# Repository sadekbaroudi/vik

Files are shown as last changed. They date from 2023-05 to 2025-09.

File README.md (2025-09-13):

# VIK

> **Warning**  
> This is a work in progress. It has been tested to be functional, but please consult **sadekbaroudi** in the **#vik** channel of the [fingerpunch discord server](https://fingerpunch.xyz/discord) if you'd like to design a keyboard or module.

> **Note**  
> **To see the list of known supported keyboards and modules, go to [this section](#known-list-of-vik-certifications) at the bottom of the readme**

> **Note**  
> Please be aware that for keyboard pcbs, VIK assumes that it's running at 3.3v logic levels. This is easily achieved by using a RP2040. If you are using a 5v controller, it is the keyboard's responsibility to level shift before going to the VIK module. See the [Microcontroller selection](#microcontroller-selection) section below

## License

**The licensing for VIK works as follows:**  
The main `LICENSE.md` in the git repository root directory applies to the whole repo, except where there is a `LICENSE.md` in the sub-folder. In that case, that `LICENSE.md` is then applied recursively until there is another `LICENSE.md` in any of its subdirectories (if any).

## Overview

VIK is a standard for a data interface between printed circuit boards. It is intended to provide modularity between a mechanical keyboard pcb and additional features. The main pcb can have a controller and a switch matrix, while the modules can provide additional features.

The standard specifies the following:
1. The type of connector
2. The signals mapped to each pin on the connector
3. The type of cable
4. (optional) The size of the module pcb and mounting hole locations
5. Inclusion of the VIK logo on the PCB

> **Note**  
> Adding support for VIK is as simple as adding a symbol and footprint, provided in this repository, followed by some basic wiring. If you want to jump straight to the guide to do this using Kicad, go to [Implementation with Kicad](#implementation-with-kicad) 

## Renders

Keyboard with VIK certification using the keyboard footprint

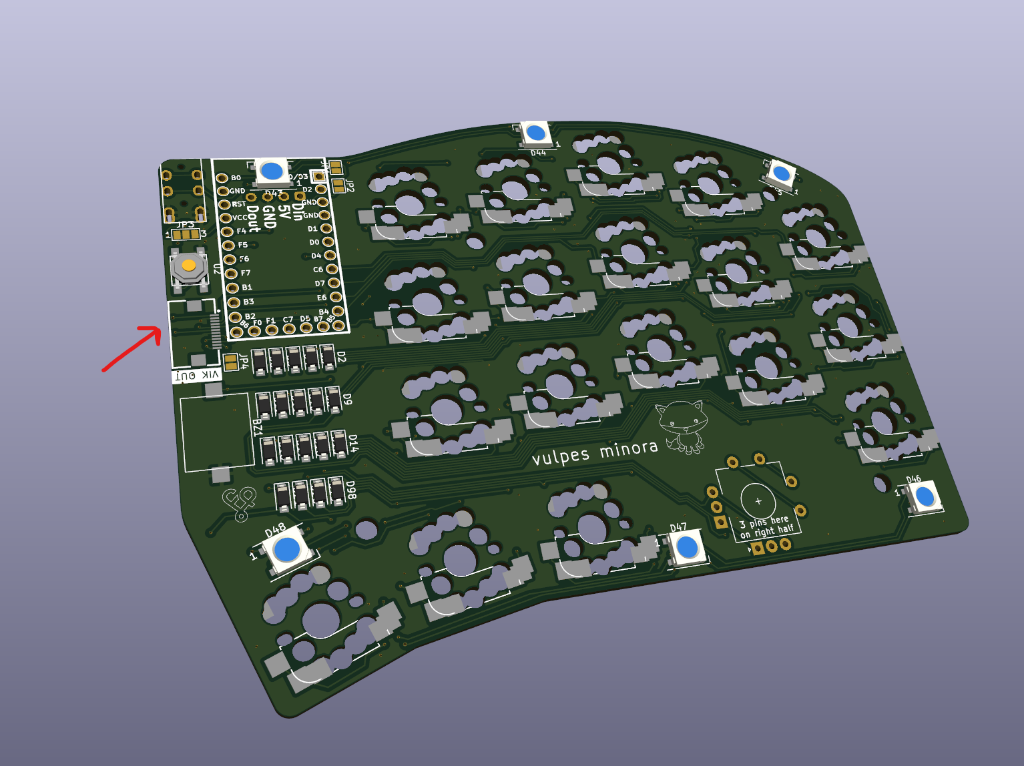
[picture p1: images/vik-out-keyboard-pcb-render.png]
vik-out-keyboard-pcb-render


Module with VIK certification using the module footprint

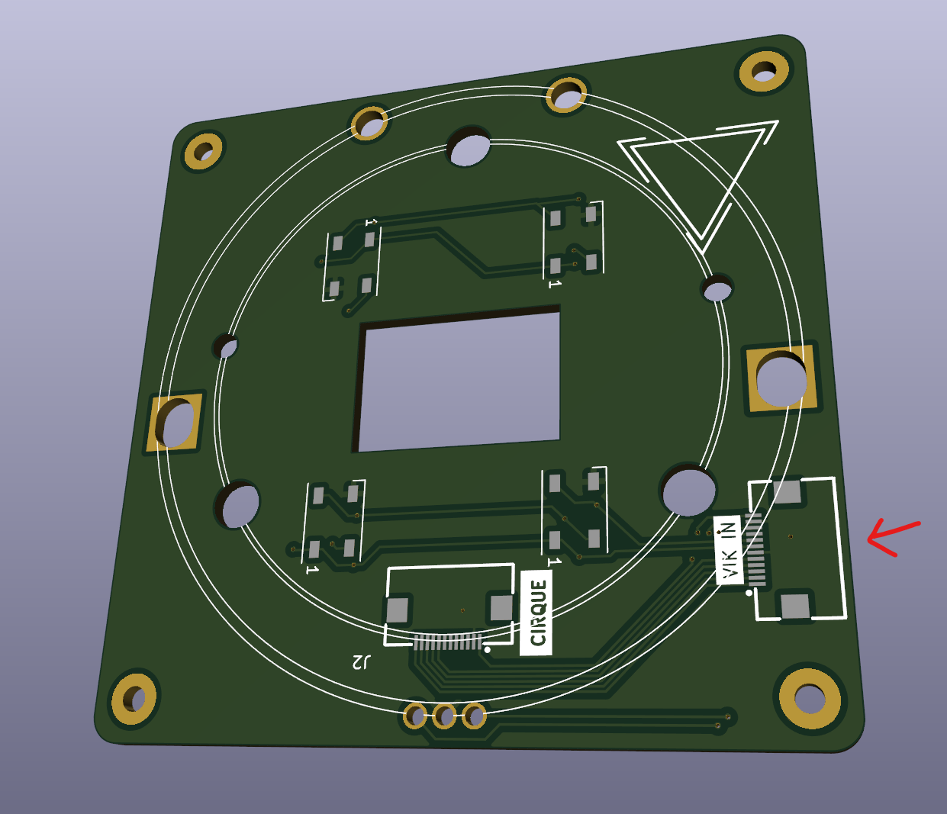
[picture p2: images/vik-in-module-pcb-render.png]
vik-in-module-pcb-render


### What value does this bring?

#### Consoldiates efforts for feature design

In a community full of talented people doing lots of innovation, we are seeing a plethora of new options for keyboard layout configurations, features, etc. With all this innovation, we're doing very little to share our efforts.

For example, if one person invests in adding support for a trackball with a scroll wheel, others have to identify how to do that, and add support for their keyboard design.

#### Ease of upgrades

With VIK support, upgrading your features is as simple as getting a new VIK module, and swapping it out.

Let's say you built a keyboard with an integrated trackpad, and you love it. Months after setting it up, you realize that you'd love to have a trackball and haptic feedback. Now you need to design a new pcb (or find someone who has) with the features you'd like. Most people don't know how, or don't want to put forth this effort, so they will settle for their current configuration. With much less effort, you can create a new VIK module, assemble it, and connect to your existing keyboard.

#### One feature for many keyboard layouts

One of the biggest challengs I find, is that a keyboard may have some really excellent features, but I really don't like the key layout. In that case, I won't be interested in the keyboard, despite wanting the features.

Provided that keyboard designers adopt the VIK standard on the main keyboard pcb, the modules are usable on any of those keyboards. So, you can design or find a keyboard that has your preferred layout, and then add the features that you like. True customizability for the exact keyboard you want to use.

## Specifications

There are two things that must be implemented for this to be successful. The keyboard pcb must support the VIK interface, and the module pcb must support the VIK interface

### Connector

The required connector is a FPC 12 pin 0.5mm pitch connector. It should be available on both the keyboard pcb and the module pcb.

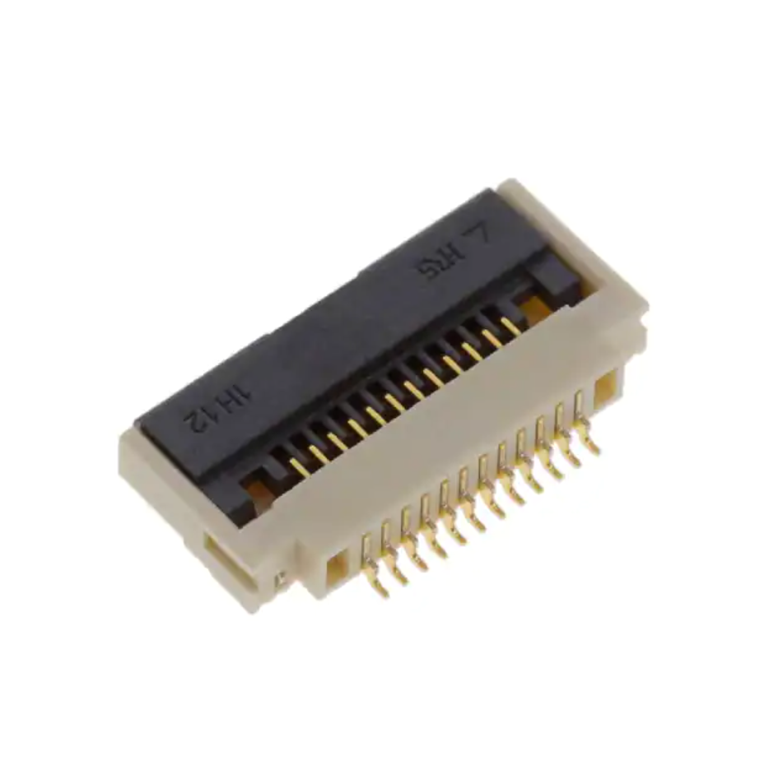
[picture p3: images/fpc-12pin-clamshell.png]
fpc 12 pin 0.5mm clamshell


#### JLCPCB part selection tips

I've received feedback that the recommended part number `C479750` for the fpc connector (`vik-{keyboard|module}-connector-horizontal`) is frequently out of stock. Fortunately, there are many equivalent parts that line up identically to this one.

To find an equivalent, I generally just search for "12p 0.5mm fpc clamshell". Then I pick one that looks identical to `C479750`. During PCBA part placement, go into 3D mode and adjust the view to make sure the pads line up nicely with the connectors. An example of an alternative part number is `C2906115`.

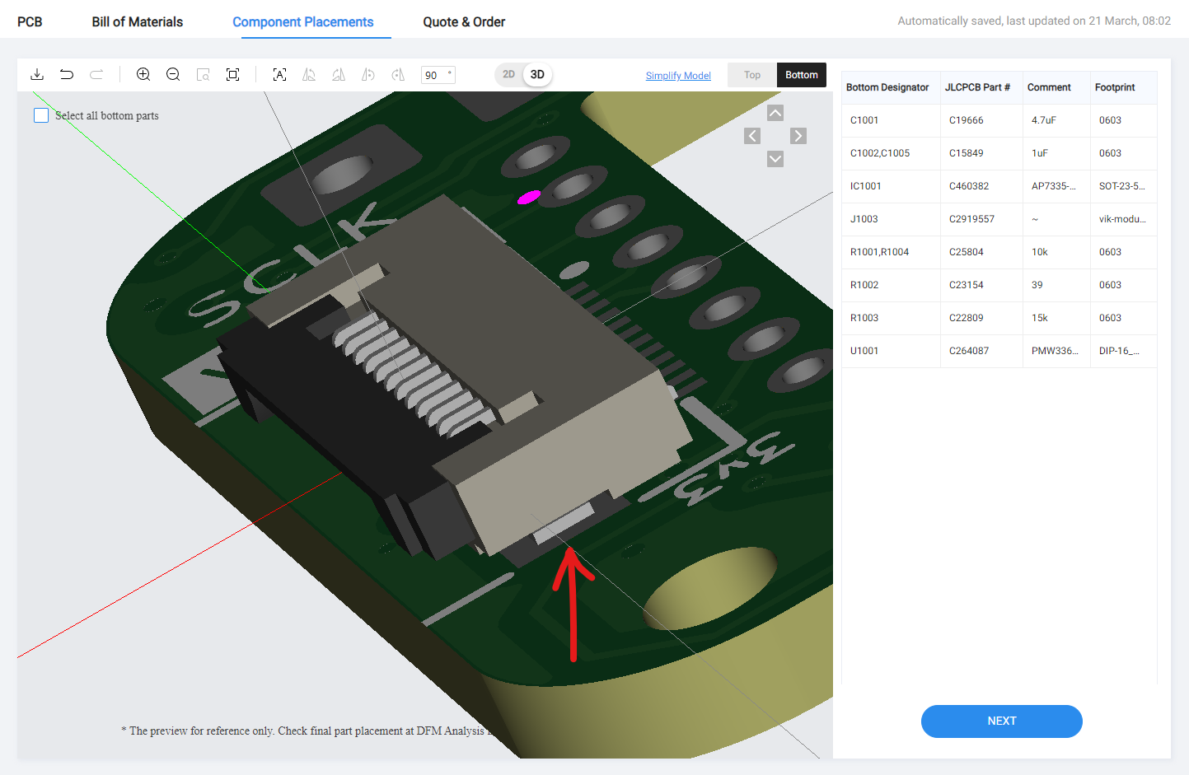
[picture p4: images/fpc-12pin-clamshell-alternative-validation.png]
fpc 12 pin 0.5mm clamshell alternative validation


### Cable

The cable should be a 12 pin 0.5mm pitch FPC Type A cable (leads are exposed on the same side).

The specs below state that you must invert the connector pin order between the keyboard and the module, which means Type A is required.

### Interface

The interface includes the following signals:
* 3.3V
* GND
* SDA
* SCL
* RGB Data Out
* 5V
* Digital/Analog GPIO 1
* MOSI
* Digital/Analog GPIO 2
* SPI CS
* MISO
* SCLK

The order specified above is the order they should be used on the FPC connector on the **keyboard side**, pins 1 through 12. For the module pcbs, they should be inverted, since the cable will automatically invert the order when connected. If you use the VIK Kicad symbols and footprints, this is managed for you. See the [Implementation with Kicad](#implementation-with-Kicad) section below

### VIK logo

So long as you adhere to the specs above, you can consider your keyboard pcb or module VIK enabled. The last thing you do before publishing or manufacturing your PCB is to include the VIK logo.

There are a collection of logos you can use in the kicad/vik.pretty directory of this repository, all prefixed with `vik-logo`. For instance, you could take the pre-made kicad footprints and include them on your pcb. If you aren't using kicad, there is a dxf and svg you can use as well.

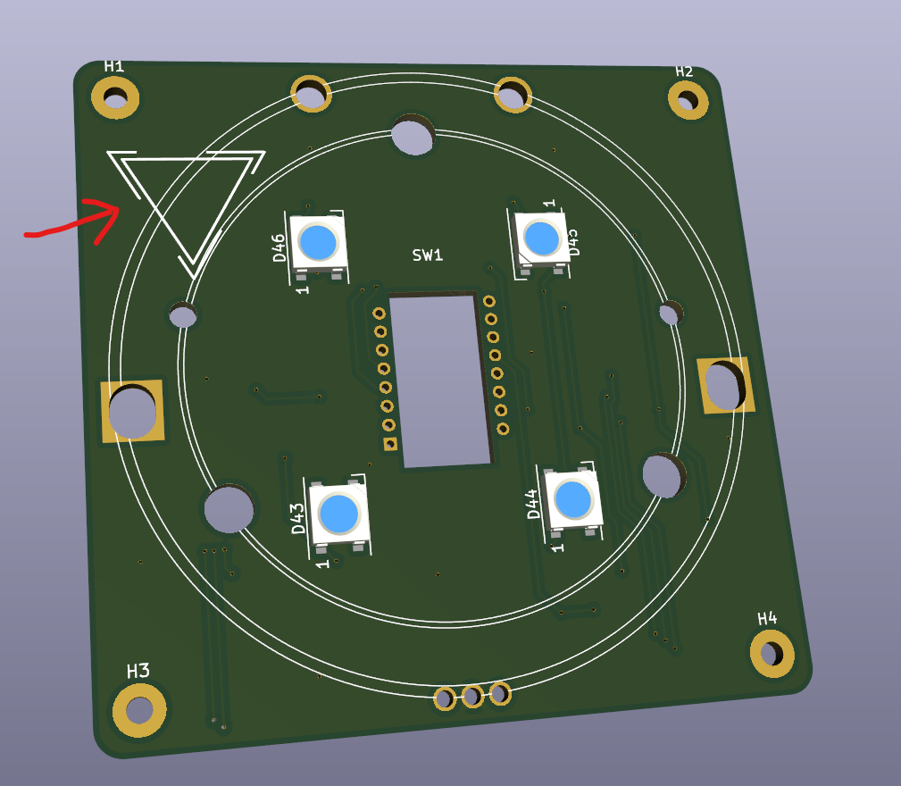
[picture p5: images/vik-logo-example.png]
vik logo example


## Module PCB shape and mounting

This is optional, but highly recommended. By adhereing to a standard size and mounting, this will allow others to design keyboard pcbs and/or cases that will support mounting a variety of modules.

There are two specs, a small and large pcb.

**All mounting holes should fit M2 screws**

### Small PCB

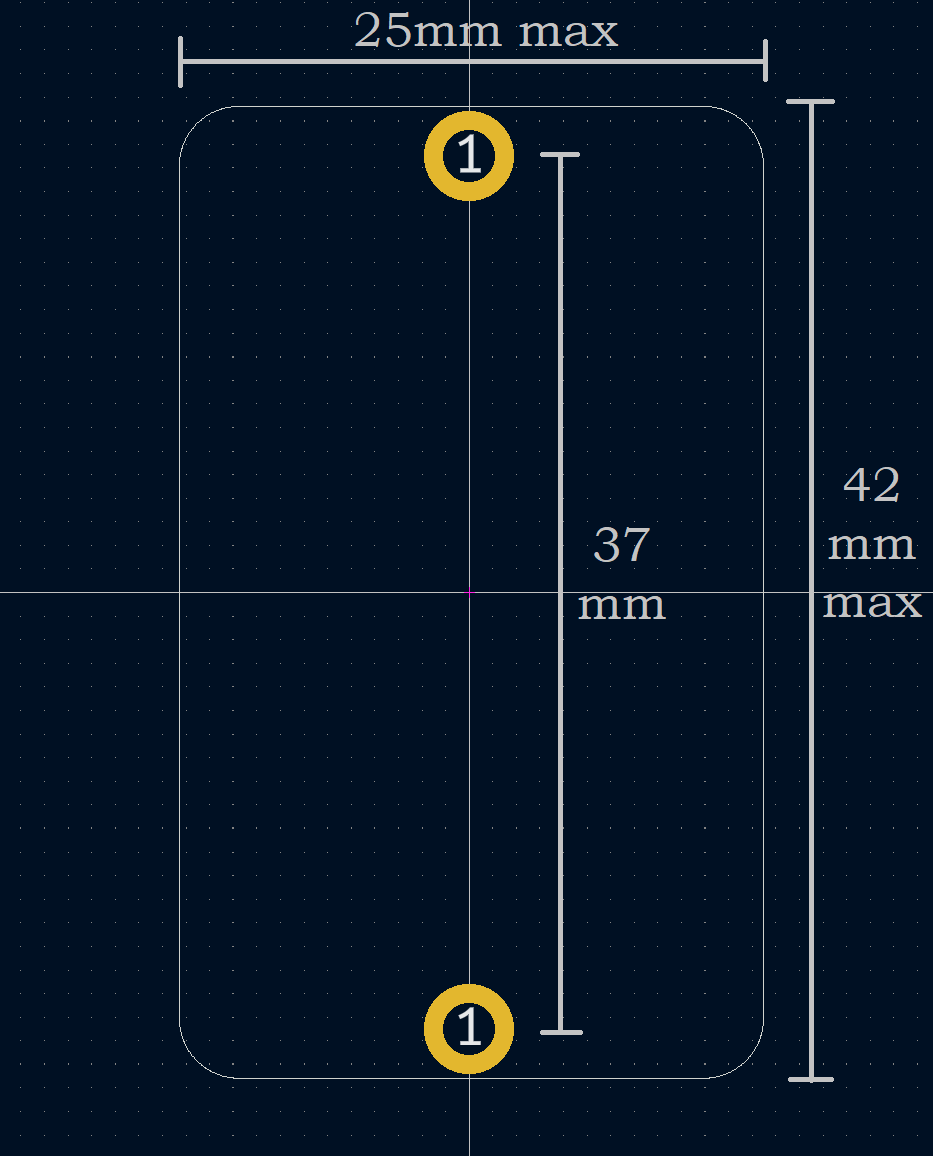
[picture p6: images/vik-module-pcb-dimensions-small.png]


Size: less than 25mm by 42mm

Mounting: 2 mounting holes

### Large PCB

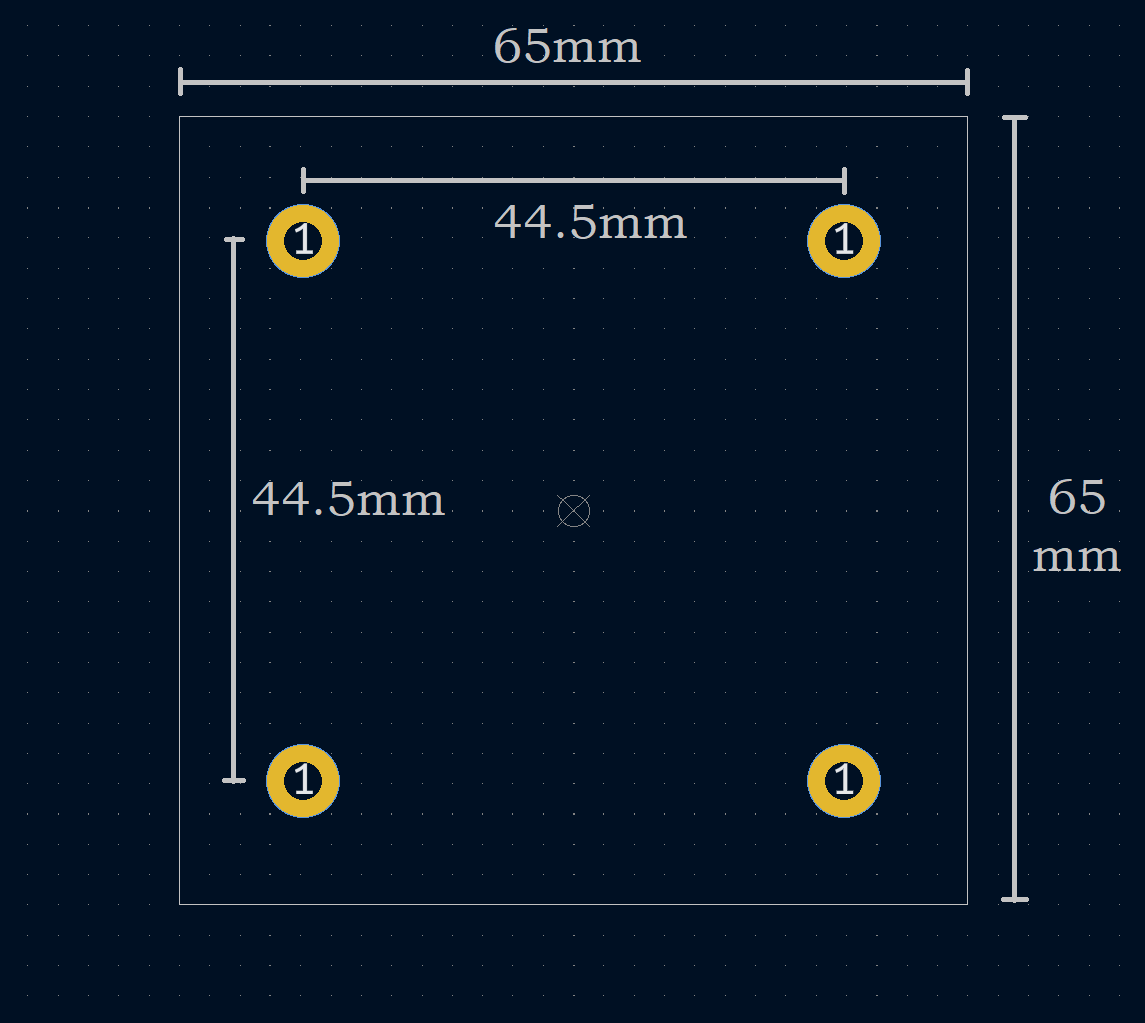
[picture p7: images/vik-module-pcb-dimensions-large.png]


Size: less than 65mm by 65mm

Mounting: 4 mounting holes

The mounting holes should 44.5mm apart in a square, centered around the center of the pcb. Alternatively, you can place these mounting holes evenly distributed around a 63mm circle, also centered around the center of the pcb.

### Module mounting Kicad footprints

There are two mounting footprints, found in the vik.pretty footprints folder:
* vik-module-mounting-small
* vik-module-mounting-large

You can use these for one of two purposes:
1) When creating a module, use the footprint to ensure that your module pcb has the correct mounting locations
2) When creating a keyboard, use the footprint to position where you'd like to mount a module pcb

You can use the Mounting Hole symbol in the schematic, and associate one of the footprints as shown below:

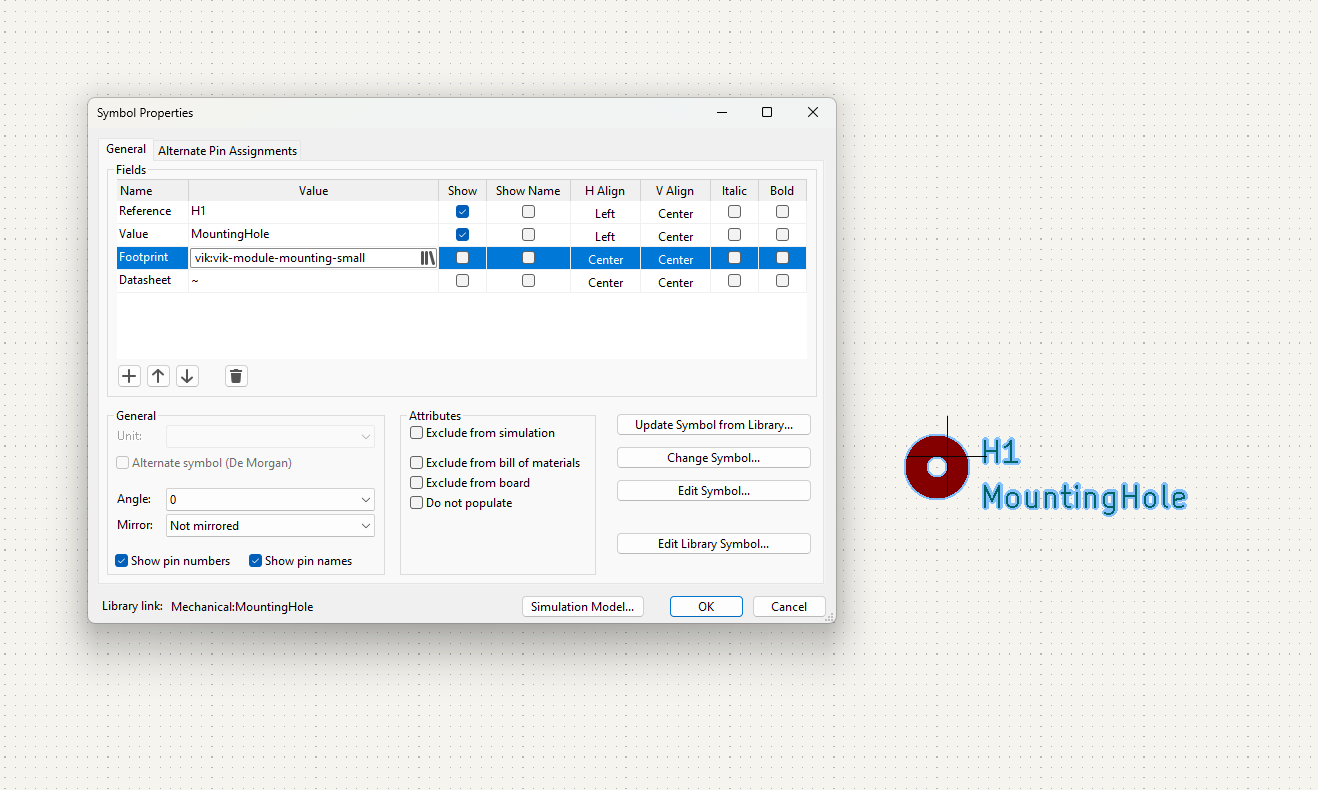
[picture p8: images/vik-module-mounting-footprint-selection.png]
vik-module-mounting-selection


## Implementation with Kicad

Given Kicad's popularity, I've made it (hopefully) very convenient to implement VIK on the keyboard and module side.

### Add symbols and footprints to your Kicad project

1. Clone this repository to your local machine
2. Add the VIK symbol library your project
3. Add the VIK footprint library to your project

Please note that the path in the screenshots won't be the same as yours. It should be:  
`{PATH TO CLONE OF THIS REPO}/kicad/vik.kicad_sym`  
and  
`{PATH TO CLONE OF THIS REPO}/kicad/vik.pretty`  

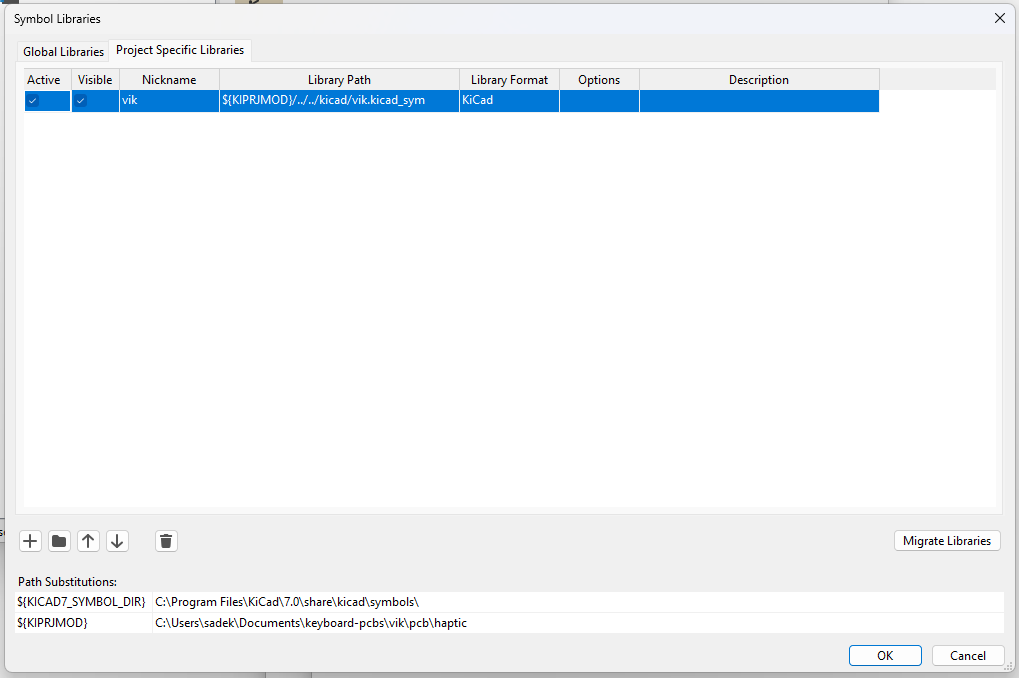
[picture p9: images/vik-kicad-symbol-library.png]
vik-kicad-symbol-library


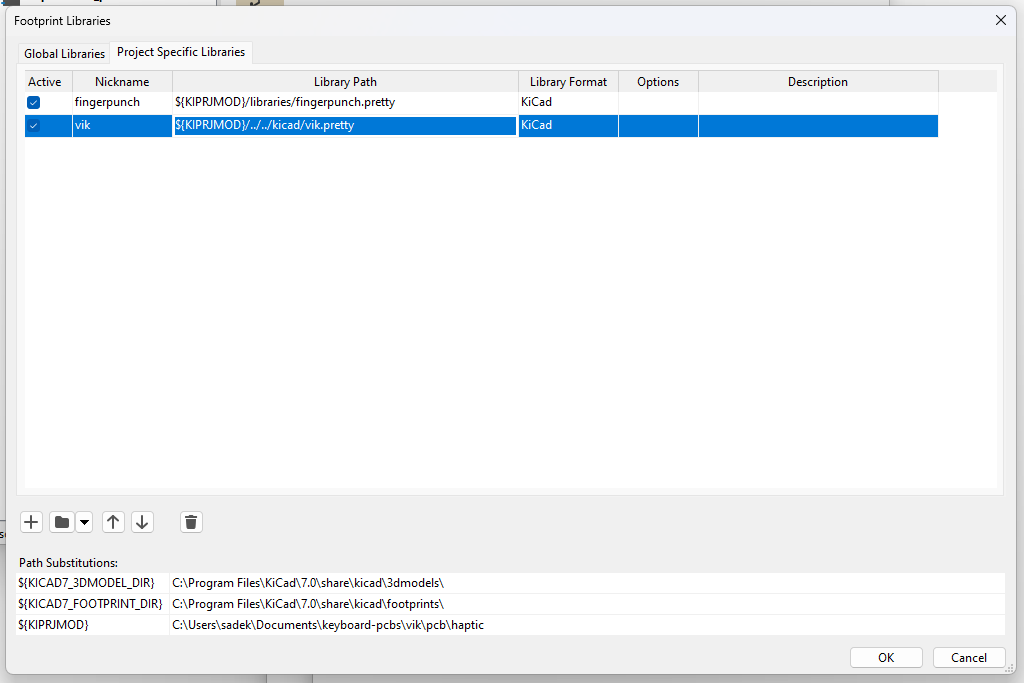
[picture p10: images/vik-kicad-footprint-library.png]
vik-kicad-footprint-library


### Kicad keyboard connector

1. Add a new symbol in the schematic, and select the `vik-keyboard-connector`
2. Connect all the signals as specified
3. Associate with the type of footprint you'd like to use (all of the VIK examples use the horizontal connector footprint). Given you are making a keyboard connector, be sure to use the ones that have the word keyboard in them. See the image below for an example.
4. Update your PCB from the schematic and wire it up!

#### Adding the keyboard connector symbol

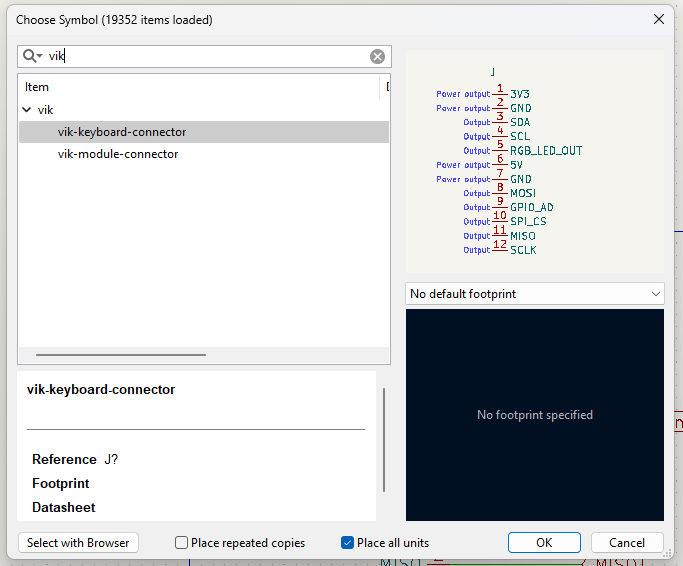
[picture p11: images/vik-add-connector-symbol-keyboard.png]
vik-add-connector-symbol-keyboard


#### Assigning the keyboard connector footprint

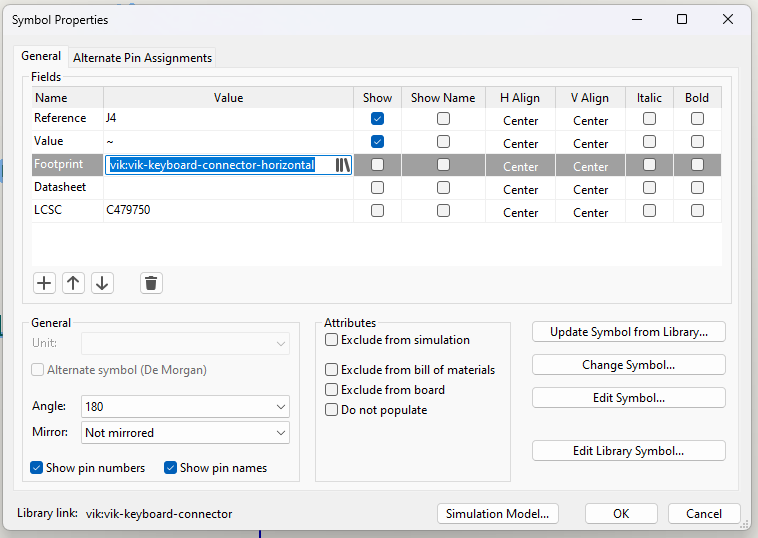
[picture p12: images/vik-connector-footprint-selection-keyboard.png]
vik-connector-footprint-selection-keyboard


#### Example schematic for keyboard connector

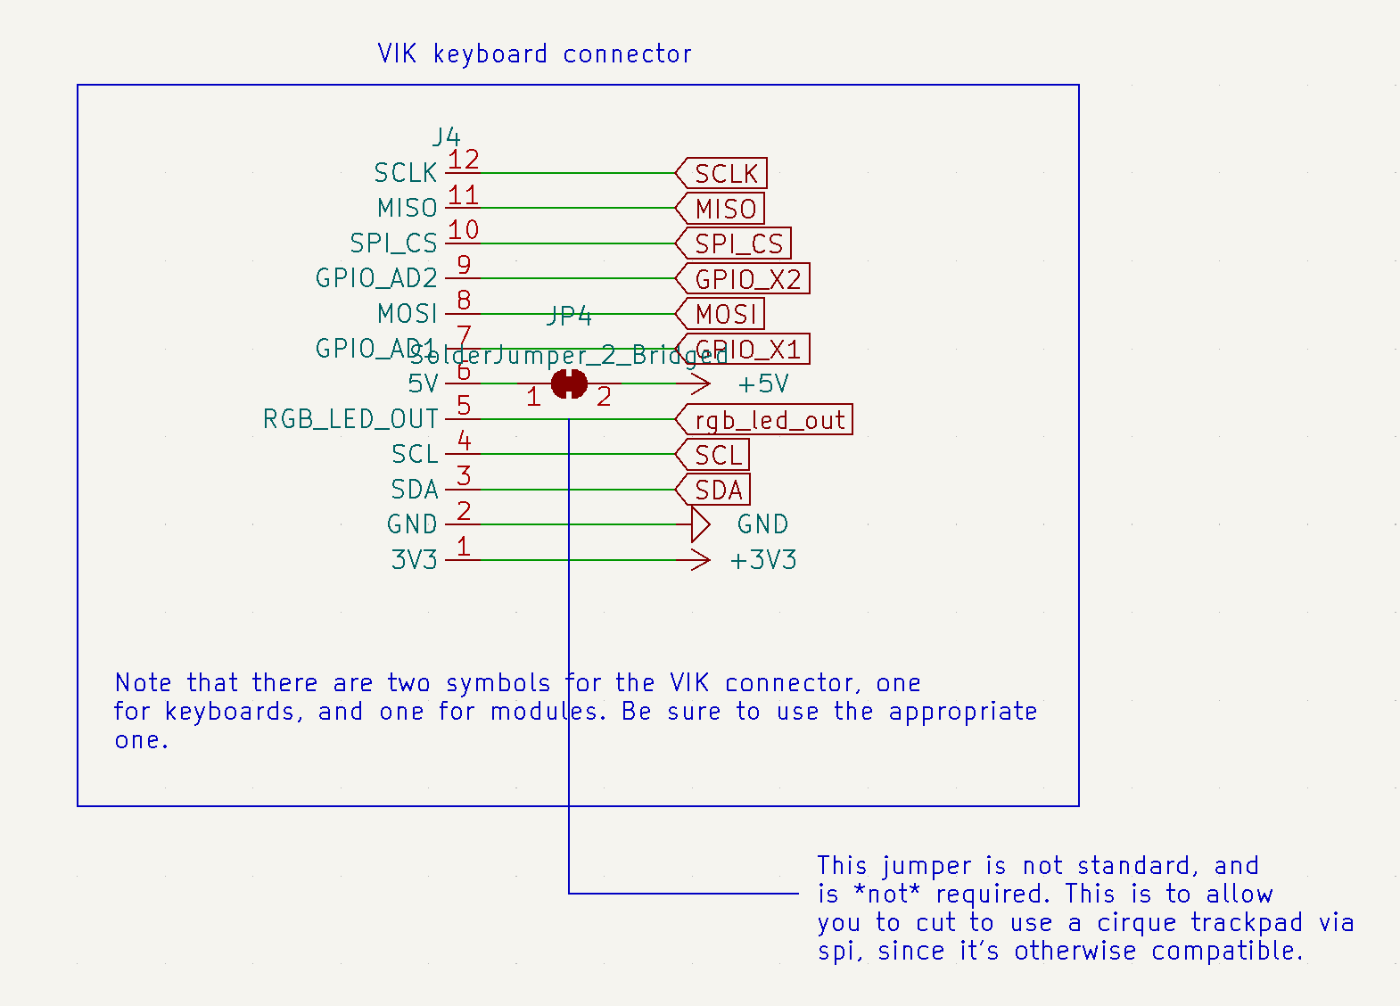
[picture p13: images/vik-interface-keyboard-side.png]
vik fpc keyboard


#### Example wiring for keyboard connector

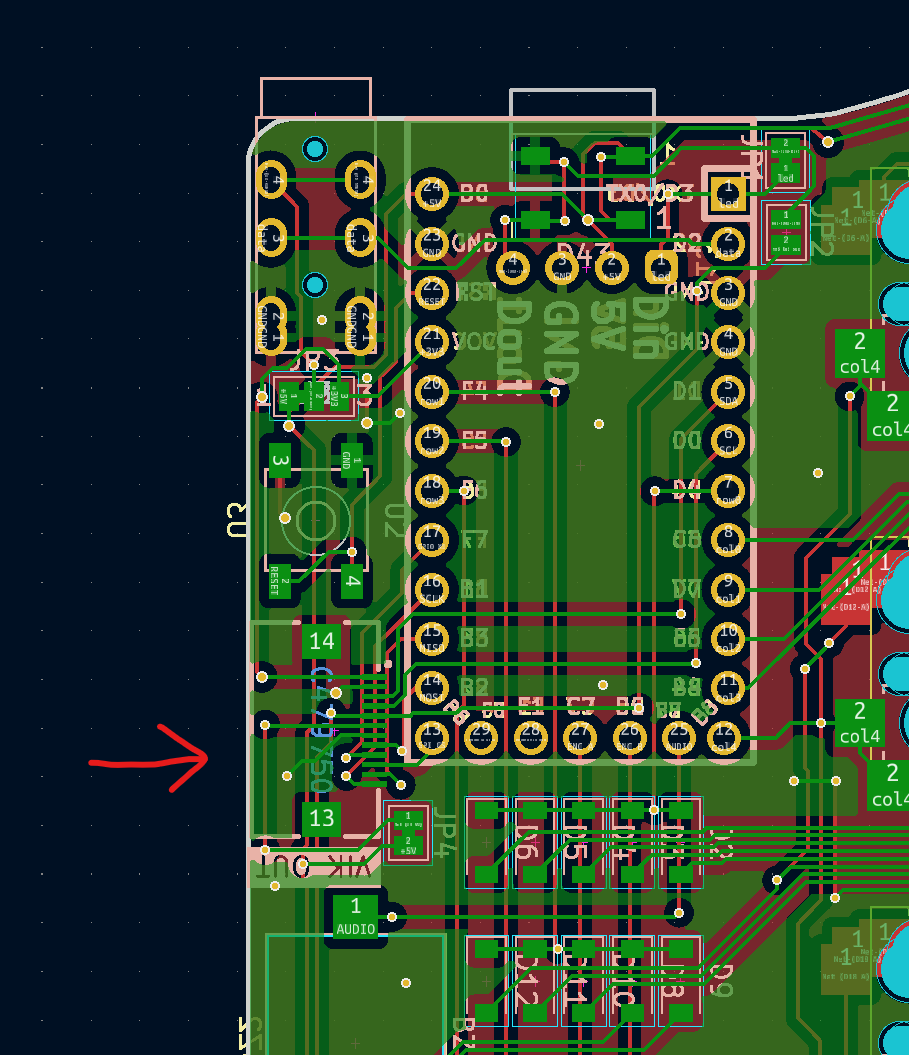
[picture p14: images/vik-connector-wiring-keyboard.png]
vik-connector-wiring-keyboard


### Kicad module connector

1. Add a new symbol in the schematic, and select the `vik-module-connector`
2. Connect all the signals as specified
3. Associate with the type of footprint you'd like to use (all of the VIK examples use the horizontal connector footprint). Given you are making a module connector, be sure to use the ones that have the word module in them. See the image below for an example.
4. Update your PCB from the schematic and wire it up!

#### Adding the module connector symbol

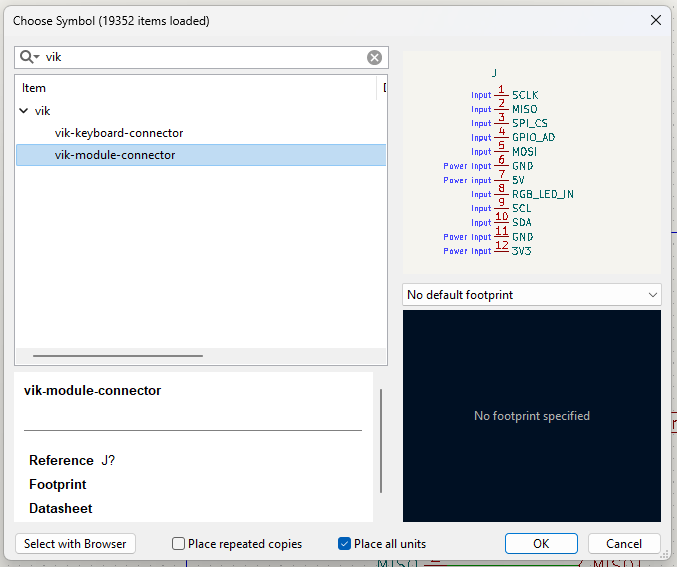
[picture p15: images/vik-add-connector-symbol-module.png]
vik-add-connector-symbol-module


#### Assigning the module connector footprint

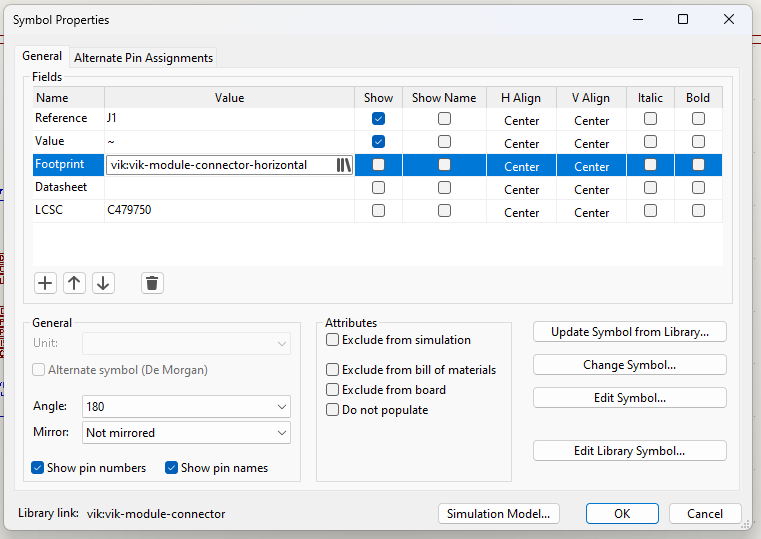
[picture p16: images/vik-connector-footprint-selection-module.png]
vik-connector-footprint-selection-


#### Example schematic for module connector

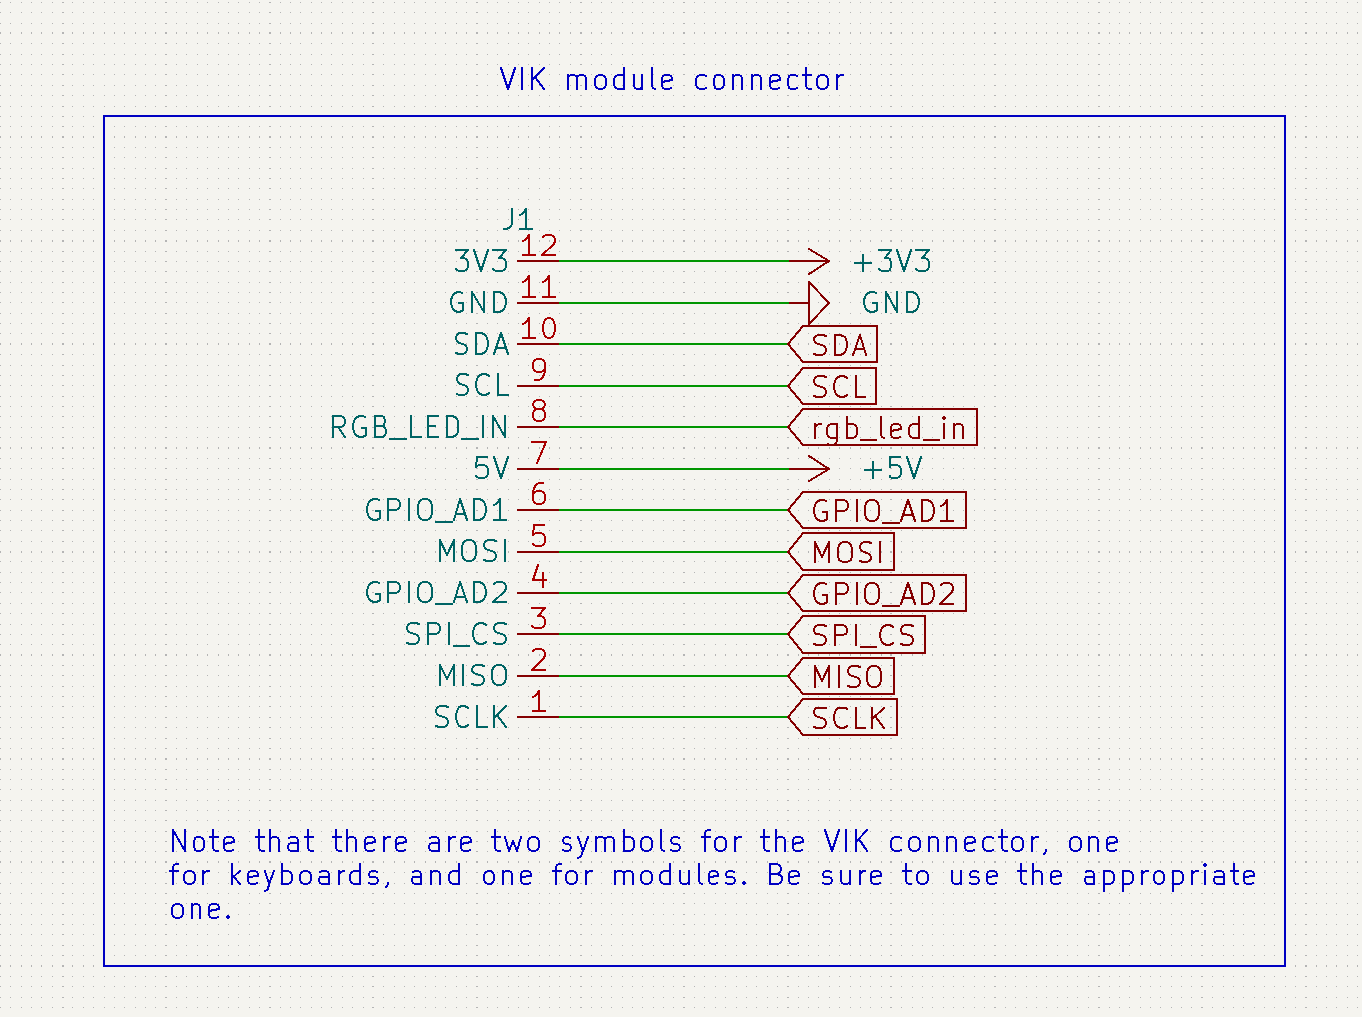
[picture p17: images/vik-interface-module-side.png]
vik fpc module


#### Example wiring for module connector

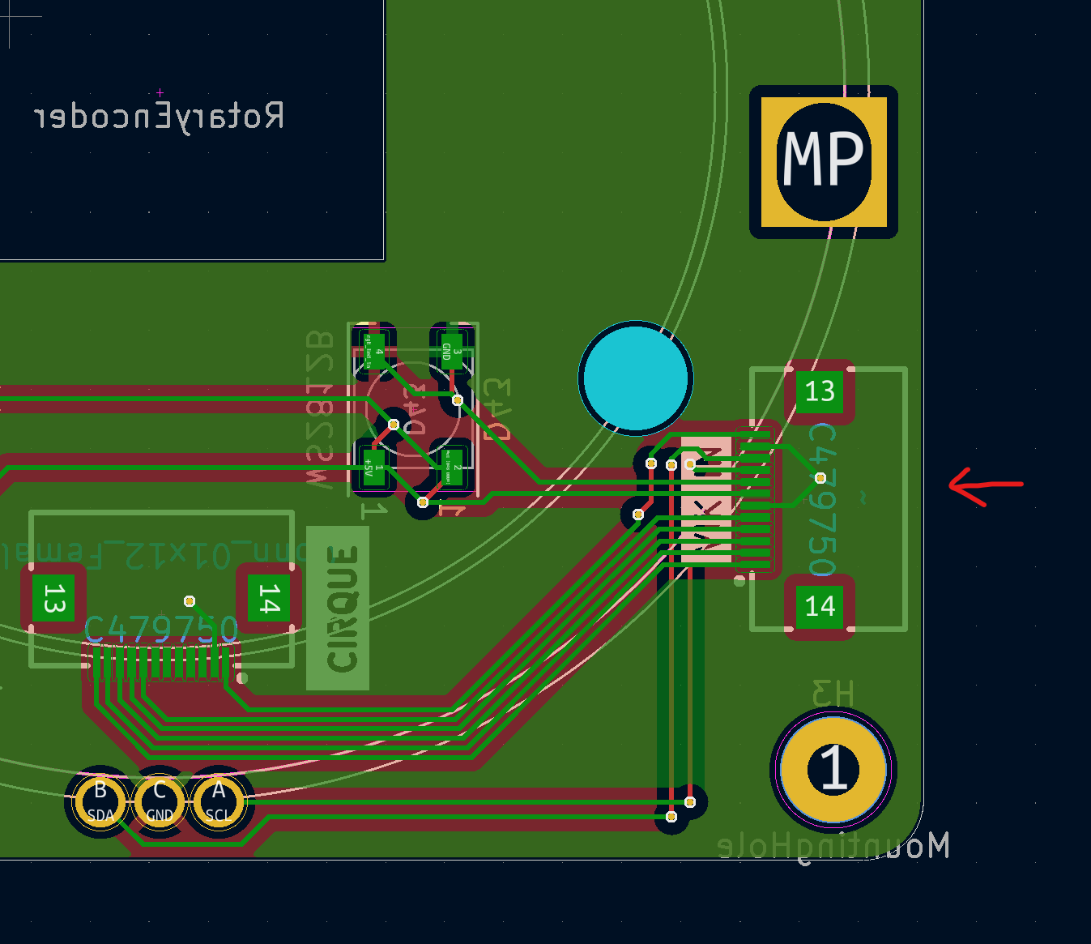
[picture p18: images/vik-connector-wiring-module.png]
vik-connector-wiring-module


## Schematic design guide

Assuming you already have the VIK symbols and footprints included in your schematic, you will need to wire them according to the specs. Let's walk through each signal, and review how to wire. I'll break this into two parts, one for the keyboard design, and one for the module design.

### Keyboard schematic guide

First and foremost, it's very important that the keyboard have everything set up correctly. Given it's the one supplying the signals to the module, you want to be fully compatible with as many modules as possible.

Here is each signal, and an overview of how to wire it.

**3.3V**

This one is fairly straight forward in the sense that you just need to supply 3.3v. That said, there are controllers out there that do not include it natively. Please review the [Microcontroller selection](#Microcontroller-selection) section below for details.

**GND**

Connect ground to this pin.

**SDA**

Microcontrollers usually have more than one set of I2C signals. On dev boards like the [Helios](https://github.com/0xCB-dev/0xCB-Helios) or [Elite-Pi](https://docs.keeb.io/elite-pi-guide), it's as simple as wiring the SDA pin to the corresponding SDA pin on the VIK connector.

**SCL**

This is the exact same as described for SDA, but using SCL instead

**RGB Data Out**

If you don't have RGB leds on your keyboard, this can be any digital GPIO. Just pick any data signal, and route it to the RGB pin on the VIK connector.

If you are using RGB leds, you'll want to do two things:
1. Wire the data out from the last LED to the RGB pin on the VIK connector
2. Connect from the controller LED data pin to the VIK connector, but put an open jumper in the middle. The nice thing about this is that it allows the end user to still use the LED feature on a module without necessarily having the LEDs assembled on their keyboard.

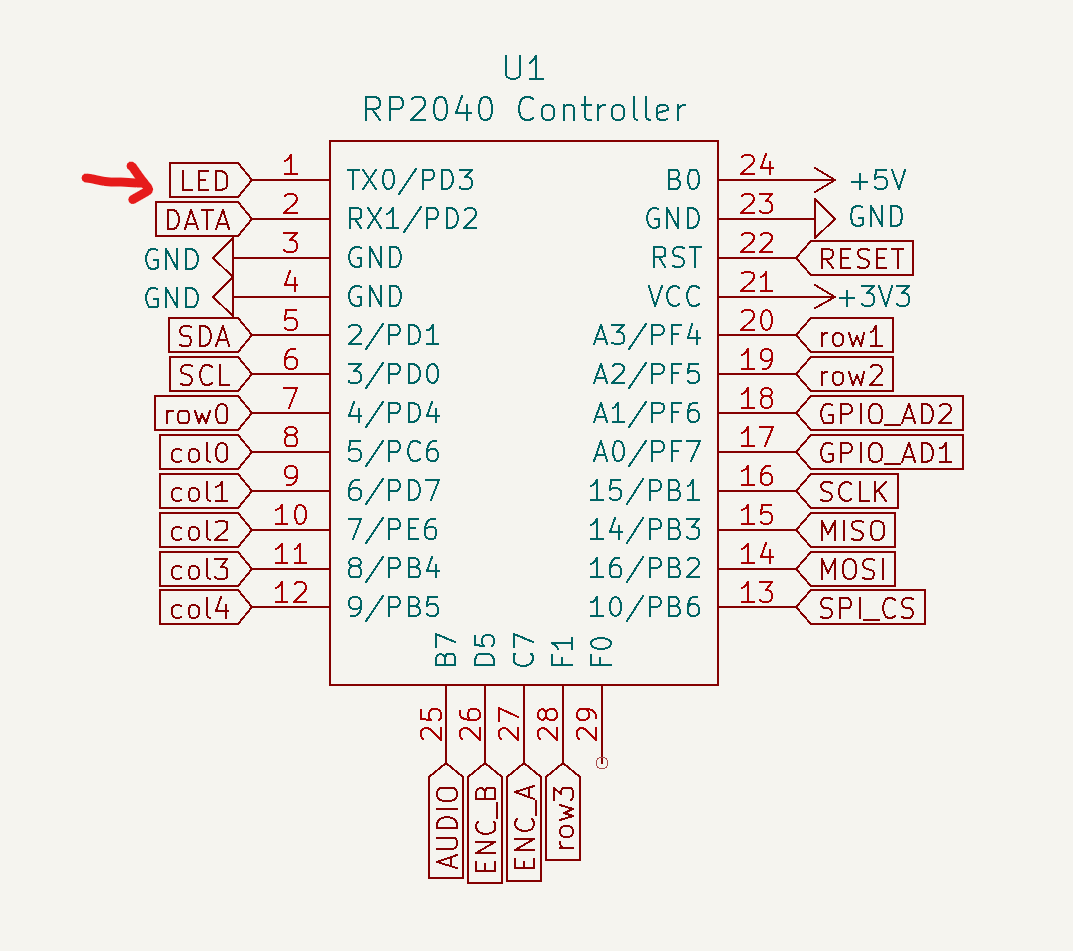
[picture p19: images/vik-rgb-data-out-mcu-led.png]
vik-rgb-data-out-mcu-led

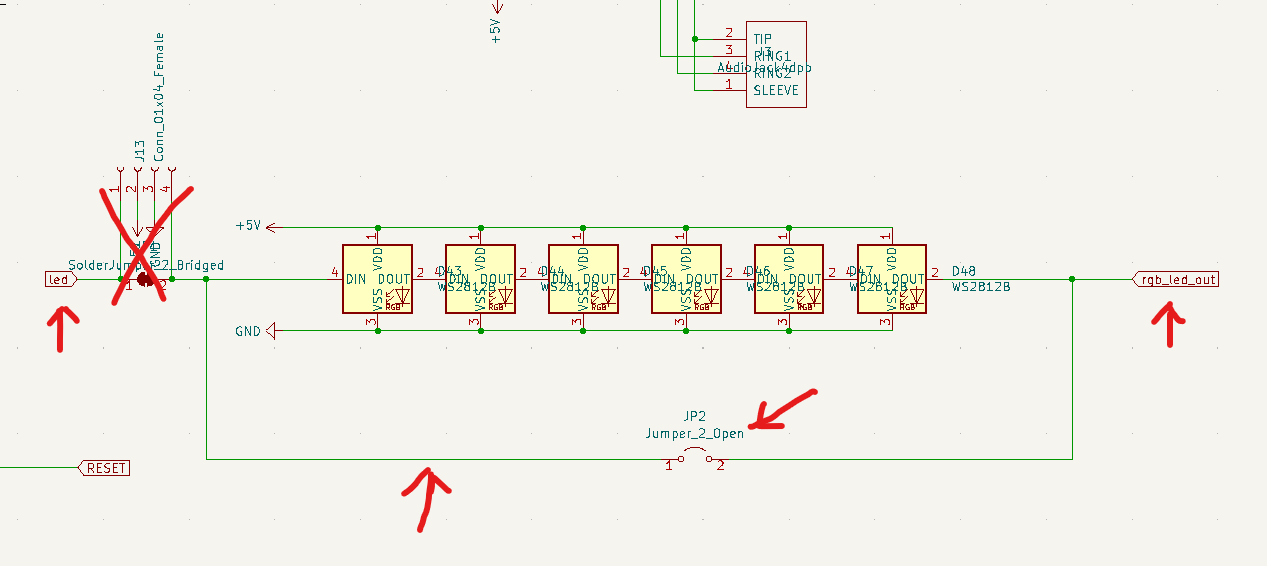
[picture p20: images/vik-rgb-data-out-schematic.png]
vik-rgb-data-out-schematic

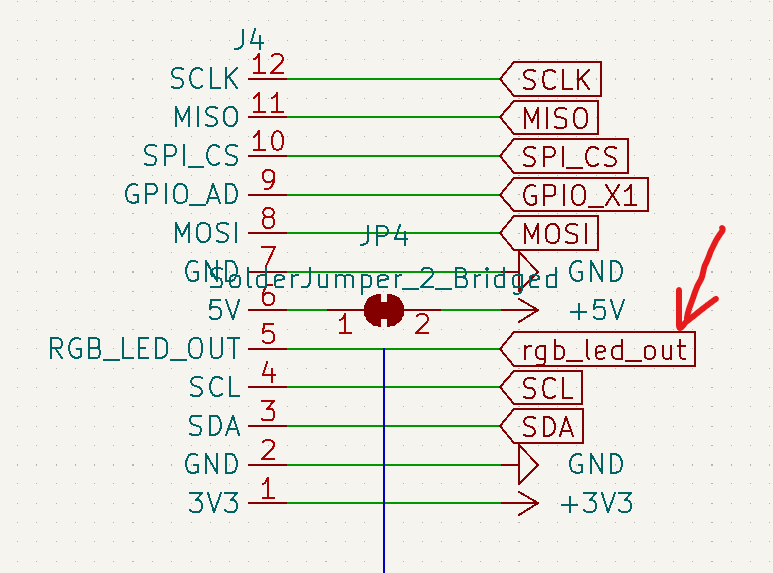
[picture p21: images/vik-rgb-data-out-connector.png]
vik-rgb-data-out-connector


**5V**

Connect 5V to the VIK connector. Be careful not to use VCC on an RP2040 controller, as that is 3.3V. Instead, you can take the RAW output from a controller. On all controllers that I'm aware of as of this writing, it's the top right pin (please double check this before you wire it up).

For example, on the elite-pi:
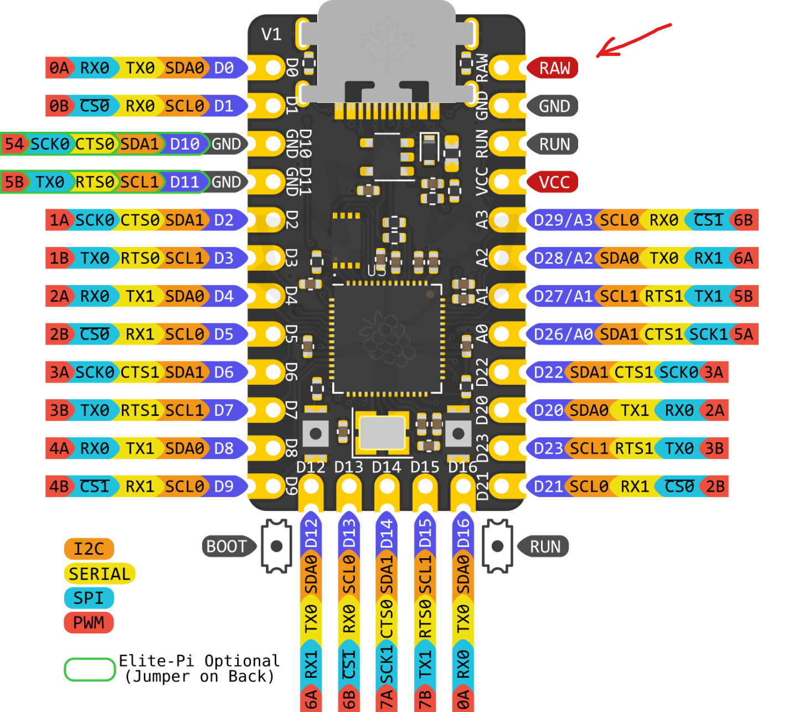
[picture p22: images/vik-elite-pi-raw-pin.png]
vik-elite-pi-raw-pin


**Digital/Analog GPIO 1**

Similar to the RGB Data Out, you can select any pin, but it should support both digital and analog. Below is an example of the Elite-Pi, highlighting its pins that support both.

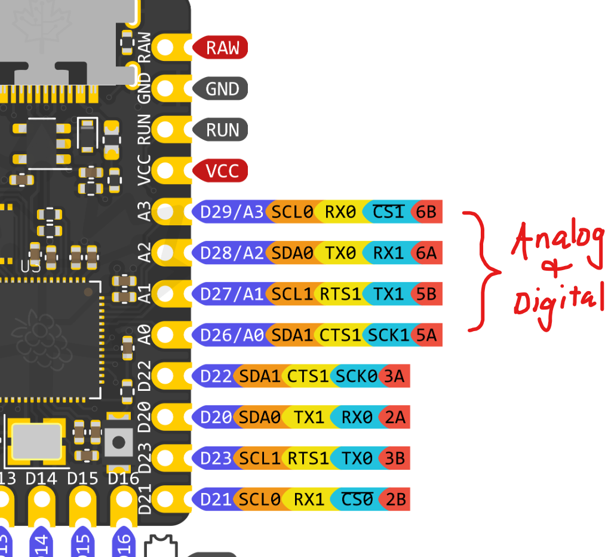
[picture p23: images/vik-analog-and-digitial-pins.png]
vik-analog-and-digitial-pins


**MOSI**

Similar to I2C, SPI has predefined locations on most controllers. If doing an integrated controller, please refer to the datasheet to determine the correct pins.

That said, on dev controllers like the [Helios](https://github.com/0xCB-dev/0xCB-Helios) or [Elite-Pi](https://docs.keeb.io/elite-pi-guide), they are standard locations. See the image below. You can wire the 4 SPI pins as shown.

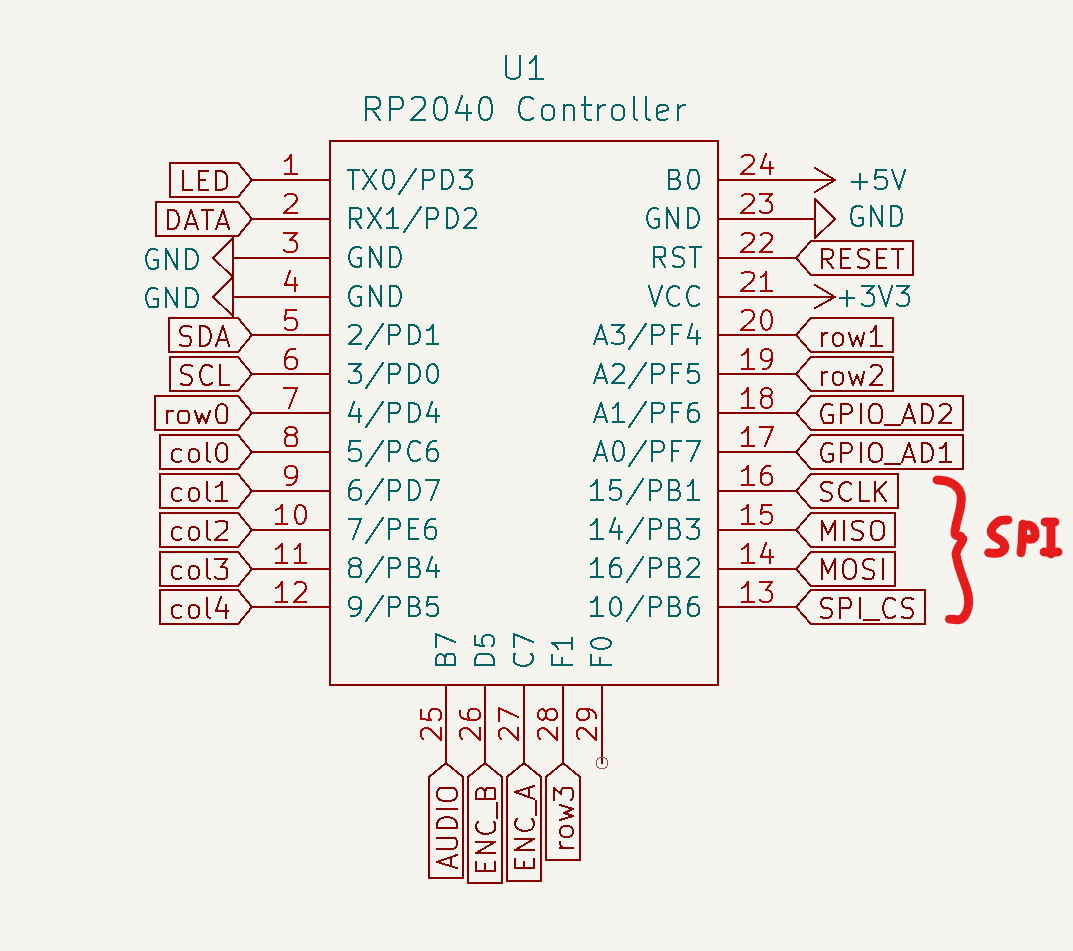
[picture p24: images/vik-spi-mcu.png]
vik-spi-mcu


**Digital/Analog GPIO 2**

Same as `Digital/Analog GPIO 1`, but this should be a second independent GPIO of the same specifications.

**SPI CS**

No additional info beyond the `MOSI` section above. Same course of action, but for the SPI CS signal.

**MISO**

No additional info beyond the `MOSI` section above. Same course of action, but for the MISO signal.

**SCLK**

No additional info beyond the `MOSI` section above. Same course of action, but for the SCLK signal.

### Module schematic guide

There aren't any major considerations for the schematic for the module. Everything on the connector is an input, so you can choose what to do with them.

That said, please note that using the I2C or SPI pins for anything **other than I2C or SPI** will break on keyboards that use those signals on the main board. So, please avoid doing so if you care about maximizing compatibility.

## Design guidelines and recommendations

### Reference designs

For the keyboard side, I created a keyboard called [vulpes minora](http://github.com/sadekbaroudi/vulpes-minora). This keyboard has been manufactured and tested to work with VIK modules.

For the module side, please see the pcb directory in this repository. Each subdirectory within it has a module that you can review to see how these are implemented.

### I2C guidelines

#### Keyboard pcb

As mentioned above, the responsibility of using pull up resistors is on the VIK modules. This may cause challenges for a few reasons. You may want (or need) to use I2C on the main keyboard PCB, which means you need to use pull up resistors. If this is the case, please provide instructions to inform the users that when using VIK modules, they will need to remove (or not place) the pull up resistor on the keyboard.

#### Module pcb

When designing a module, please ensure that you include pull up resistors, since the guidelines state that the keyboard pcb is not responsible for it.

### Microcontroller selection

If you are designing a keyboard pcb that uses a dev board as a controller (e.g. pro micro, elite-c, stemcell, etc), you should consider that the VIK specs calls for 3.3V and 5V. Given these controllers operate on 5V and don't provide 3.3V, you won't be able to use them for VIK compatibility without additonal circuitry to convert 5V to 3.3V.

**As described at the top of the README in the note, the keyboard pcb should run at at 3.3v logic levels. The simplest option is to use a RP2040 based development board. For integrated controllers, either use a controller that already runs at 3.3v logic, or level shift the GPIO before going into the VIK connector.**

Some options include:
1. Support only RP2040 based controllers (e.g. splinky, elite-pi, helios), where VCC is 3.3V, and the RAW pin provides 5V
2. Support other 5V controllers, and use something like an LDO to convert 5V to 3.3V for the VIK 3.3V signal and GPIO signals
3. Anything you want, as long as you can provide 5V and 3.3V (both power and 3.3v gpio logic levels)

The vulpes minora is an example of point number 1 above.

## VIK certification

In order to be VIK certified, you should be compliant with everything above, and have your keyboard or module reviewed. Upon review, the reviewer will make a card for your pcb, as explained below.

### VIK keyboard certification card

#### Descriptions

* **FPC connector:** has the correct FPC connector with the right pinout, and is wired to specificaton. See the connectors in the kicad/vik.pretty directory
* **Breakout pins:** includes breakout pins using the [VIK breakout pin footprint](https://github.com/sadekbaroudi/vik/blob/master/kicad/vik.pretty/vik-keyboard-throughole.kicad_mod), or has through holes for all the signals. This allows easy access to all the signals. Also, the footprint is compatible with a [hand solderable FPC breakout board](https://www.amazon.com/uxcell-Converter-Couple-Extend-Adapter/dp/B07RVD1J1K).
* **Supplies: SPI** supplies SPI signals, including MISO, MOSI, SCLK, and CS
* **Supplies: I2C:** supplies I2C, including SDA and SCL
* **I2C on main PCB:** Does the main PCB use any I2C already. Valid responses are `yes` or `no`. If this is true, the `I2C pull ups` field must have a value
* **I2C pull ups:** I2C pull up resistor value, :x: if no pull ups on the main pcb, or resistor value if present
* **Supplies: RGB:** supplies RGB data out
* **Supplies: Extra GPIO 1:** supplies the extra GPIO, response will be one of: (**:x: | Digital Only | Analog/Digital**)
* **Supplies: Extra GPIO 2:** supplies the extra GPIO, response will be one of: (**:x: | Digital Only | Analog/Digital**)

#### Keyboard sample cards

Example of a failing card:

| Category | Classification | Response |
| ---  | --- | --- |
| FPC connector | Required | :heavy_check_mark: |
| Breakout pins | Recommended | :x: |
| Supplies: SPI | Required | :heavy_check_mark: |
| Supplies: I2C | Required | :heavy_check_mark: |
| I2C on main PCB | Discouraged | yes |
| I2C pull ups | Informative | 2.2kΩ |
| Supplies: RGB | Required | :x: |
| Supplies: Extra GPIO 1 | Required | :x: |
| Supplies: Extra GPIO 2 | Required | :x: |

A "perfect" keyboard card would look like this:

| Category | Classification | Response |
| ---  | --- | --- |
| FPC connector | Required | :heavy_check_mark: |
| Breakout pins | Recommended | :heavy_check_mark: |
| Supplies: SPI | Required | :heavy_check_mark: |
| Supplies: I2C | Required | :heavy_check_mark: |
| I2C on main PCB | Discouraged | no |
| I2C pull ups | Informative | N/A |
| Supplies: RGB | Required | :heavy_check_mark: |
| Supplies: Extra GPIO 1 | Required | Analog/Digital |
| Supplies: Extra GPIO 2 | Required | Analog/Digital |

### VIK module certification card

#### Descriptions

* **FPC connector:** has the correct FPC connector with the right pinout, and is wired to specificaton. See the connectors in the kicad/vik.pretty directory
* **Breakout pins:** includes breakout pins using the [VIK breakout pin footprint](https://github.com/sadekbaroudi/vik/blob/master/kicad/vik.pretty/vik-keyboard-throughole.kicad_mod), or has through holes for all the signals. This allows easy access to all the signals. Also, the footprint is compatible with a [hand solderable FPC breakout board](https://www.amazon.com/uxcell-Converter-Couple-Extend-Adapter/dp/B07RVD1J1K).
* **Uses: SPI:** the module is utilizing SPI
* **SPI used for SPI only:** if you are using any of the SPI gpio for any purpose other than SPI, this will remain unchecked. This means that keyboard pcbs that use SPI will be incompatible with this module.
* **Uses: I2C:**
* **I2C used for I2C only:** if you are using any of the I2C gpio for any purpose other than I2C, this will remain unchecked. This means that keyboard pcbs that use I2C will be incompatible with this module.
* **I2C pull ups:** I2C pull up resistor value, if applicable. These are only required if I2C is being used on the module.
* **Uses: RGB:** uses RGB data out
* **Uses: Extra GPIO 1:** uses the extra GPIO, response will be one of: (**:x: | Digital Only | Analog/Digital**)
* **Uses: Extra GPIO 2:** uses the extra GPIO, response will be one of: (**:x: | Digital Only | Analog/Digital**)
* **Standard PCB Size/Mount:** adheres to standard module size and mounts, responses will be one of: (**:x: | Small | Large**)

#### Module sample card

General example:

| Category | Classification | Response |
| --- | --- | --- |
| FPC connector | Required | :heavy_check_mark: |
| Breakout pins | Recommended | :x: |
| Uses: SPI | Optional | :heavy_check_mark: |
| SPI used for SPI only | Strongly recommended | :heavy_check_mark: |
| Uses: I2C | Optional | :heavy_check_mark: |
| I2C used for I2C only | Strongly Recommended | :heavy_check_mark: |
| I2C pull ups | Required | 4.7kΩ |
| Uses: RGB | Optional | :x: |
| Uses: Extra GPIO 1 | Optional | :x: |
| Uses: Extra GPIO 2 | Optional | :x: |
| Standard PCB Size/Mount | Strongly recommended | Large |

## Known list of VIK certifications

### Controllers

| Name | GPIO (excluding VIK connector) | Status | Open source or Commercial | Creator |
| --- | --- | --- | --- | --- |
| [svlinky](https://github.com/sadekbaroudi/svlinky/) | 18 | Complete | Open source | [Sadek Baroudi](https://github.com/sadekbaroudi/) |
| [xivik](https://fingerpunch.xyz/product/xivik/) | 11 | Complete | Commercial | [Sadek Baroudi](https://github.com/sadekbaroudi/) |
| [lemon-microcontroller](https://github.com/rianadon/Cosmos-Keyboard-PCBs) | 19 | Complete | Open Source / Commercial | [rianadon](https://github.com/rianadon/) |
| [lemon-wireless](https://github.com/rianadon/Cosmos-Keyboard-PCBs) | 15 | Complete | Open Source / Commercial | [rianadon](https://github.com/rianadon/) |

### Keyboards

| Name | Keys  | Style | Status | Open source or Commercial | Creator |
| --- | ----- | --- | --- | --- | --- |
| [vulpes minora](https://github.com/sadekbaroudi/vulpes-minora/) | 36 | Split | Complete | Open source | [Sadek Baroudi](https://github.com/sadekbaroudi/) |
| [ximi](https://fingerpunch.xyz/product/ximi/) | 36/42 | Split | Complete | Commercial | [Sadek Baroudi](https://github.com/sadekbaroudi/) |
| [stront](https://github.com/zzeneg/stront/) | 38 | Split | Partial support (see stront readme) | Open source | [zzeneg](https://github.com/zzeneg/) |
| [Honeydew](https://github.com/Ariamelon/Honeydew/) | 63 | Unibody | Work in progress | Open source | [Ariamelon](https://github.com/Ariamelon/Honeydew/) |
| [Benboard](https://github.com/ben-labs-ltd/benboard) / [Benboard - commercial](https://ben-labs.co.uk/) | 42 | Split | Work in progress | Commercial / Open source | [Ben](https://github.com/ben-labs-ltd/) |
| [DragonFruit](https://github.com/protieusz/DragonFruit) | 38 | Unibody | Complete | Open source | [protieusz](https://github.com/protieusz/) |
| [ZodiarkPi (product)](https://www.splitlogic.xyz/shop/splitlogic/p/zodiarkpi) [(cert)](https://github.com/sadekbaroudi/vik/tree/master/pcb/splitlogic/) | 68 | Split | Complete | Commercial | [Aleblazer](https://github.com/aleblazer/) |
| [ZodiPact (product)](https://www.splitlogic.xyz/shop/splitlogic/p/zodipact-pcb-kit) [(cert)](https://github.com/sadekbaroudi/vik/tree/master/pcb/splitlogic/) | 68 | Split | Complete | Commercial | [Aleblazer](https://github.com/aleblazer/) |
| peacock trackpad macropad/controller [(project)](https://github.com/george-norton/peacock) [(cert)](https://github.com/sadekbaroudi/vik/tree/master/pcb/peacock) | 5 | Unibody | Complete | Open source | [George Norton](https://github.com/george-norton) |
| Dilemma [(product)](https://bastardkb.com/dilemma/) [(project)](https://github.com/Bastardkb/Dilemma/tree/features/dilemma_3x0/3x5_3) [(cert)](https://github.com/sadekbaroudi/vik/tree/master/pcb/dilemma) | 36 | Split | Complete | Commercial / Open source | [Quentin Lebastard](https://github.com/Bastardkb) |

### Modules

| Name | Function | Status | Open source or Commercial | Creator |
|---| --- | --- | --- |---|
| [haptic](https://github.com/sadekbaroudi/vik/tree/master/pcb/haptic/) | Pimoroni Haptic Feedback | Complete | Open source | [Sadek Baroudi](https://github.com/sadekbaroudi/) |
| [haptic-drv2605l](https://github.com/sadekbaroudi/vik/tree/master/pcb/haptic-drv2605l/) | Haptic Feedback using DRV2605L controller | Complete | Open source | [zzeneg](https://github.com/zzeneg/) |
| [per56-cirque-leds](https://github.com/sadekbaroudi/vik/tree/master/pcb/per56-cirque-leds/) | Scroll ring, cirque trackpad, RGB LEDs | Complete | Open source | [Sadek Baroudi](https://github.com/sadekbaroudi/) |
| [per56-pmw3360-leds](https://github.com/sadekbaroudi/vik/tree/master/pcb/per56-pmw3360-leds/) | Scroll ring, trackball, RGB LEDs | Complete | Open source | [Sadek Baroudi](https://github.com/sadekbaroudi/) |
| [per56-pmw3360-cirque-leds (Kiwano)](https://github.com/Ariamelon/Kiwano/) | Scroll ring, cirque or trackball, RGB LEDs | Complete | Open source | [Ariamelon](https://github.com/Ariamelon/Honeydew/) |
| [pmw3360](https://github.com/sadekbaroudi/vik/tree/master/pcb/pmw3360/) | Trackball | Complete | Open source | [Sadek Baroudi](https://github.com/sadekbaroudi/) |
| [ssd1351 (Crenshaw)](https://github.com/Ariamelon/Crenshaw/) | Color display | Complete | Open source | [Ariamelon](https://github.com/Ariamelon/Honeydew/) |
| [weact-st7735](https://github.com/sadekbaroudi/vik/tree/master/pcb/weact-st7735/) | WeAct ST7735 1.8" color display adapter | Complete | Open source | [Sadek Baroudi](https://github.com/sadekbaroudi/) |
| [gc9a01](https://github.com/sadekbaroudi/vik/tree/master/pcb/gc9a01/) | gc9a01 round display breakout adapter | Complete | Open source | [Sadek Baroudi](https://github.com/sadekbaroudi/) |
| [waveshare-22224](https://github.com/sadekbaroudi/vik/tree/master/pcb/waveshare-22224/) | waveshare 22224 1.47" display adapter | Complete | Open source | [Sadek Baroudi](https://github.com/sadekbaroudi/) |
| [azoteq-tps](https://github.com/sadekbaroudi/vik/tree/master/pcb/azoteq-tps/) | Azoteq Proxsense TPS43 and TPS65 | Complete | Open source | [Sadek Baroudi](https://github.com/sadekbaroudi/) |
| [trackpoint](https://github.com/sadekbaroudi/vik/tree/master/pcb/trackpoint-2-piece/) | Trackpoint 2 piece adapter | Complete | Open source | [Sadek Baroudi](https://github.com/sadekbaroudi/) |
| [ec11-evqwgd001](https://github.com/sadekbaroudi/vik/tree/master/pcb/ec11-evqwgd001/) | EC11 and EVQWDG001 with RGB leds | Complete | Open source | [Sadek Baroudi](https://github.com/sadekbaroudi/) |
| [joysticks](https://github.com/sadekbaroudi/vik/tree/master/pcb/joysticks/) | adafruit 2765, sparkfun 9032, joycon | Complete | Open source | [Sadek Baroudi](https://github.com/sadekbaroudi/) |
| [vik-playground](https://github.com/sadekbaroudi/vik/tree/master/pcb/vik-playground/) | module for prototyping and testing VIK | Complete | Open source | [Sadek Baroudi](https://github.com/sadekbaroudi/) |
| [vik-universal](https://github.com/sadekbaroudi/vik/tree/master/pcb/vik-universal/) | for connecting any through hole board w/VIK | Complete | Open source | [Sadek Baroudi](https://github.com/sadekbaroudi/) |
| [ili9341v](https://github.com/sadekbaroudi/vik/tree/master/pcb/ili9341v/) | Display with capacitive touch and SD card | Complete | Open source | [Sadek Baroudi](https://github.com/sadekbaroudi/) |
| [nice!view](https://github.com/sadekbaroudi/vik/tree/master/pcb/niceview/) | nice!view display | Untested | Open source | [Sadek Baroudi](https://github.com/sadekbaroudi/) |
| [vik-display-adapter](https://github.com/zzeneg/vik-display-adapter) | various display adapters in different sizes | Complete | Open source | [zzeneg](https://github.com/zzeneg/) |
| [shift-register-spi-breakout-pcb](https://github.com/christrotter/shift-register-spi-breakout-pcb) | dual shift register breakout for extended key matrix | Untested | Open source | [Chris Trotter](https://github.com/christrotter/) |
| [pmw3610](https://github.com/sadekbaroudi/vik/tree/master/pcb/pmw3610/) | Trackball (for wireless boards) | Complete | Open source | [Sadek Baroudi](https://github.com/sadekbaroudi/) |
| [pmw3610-xs](https://github.com/sadekbaroudi/vik/tree/master/pcb/pmw3610-xs/) | Trackball (for wireless boards) | Complete | Open source | [Sadek Baroudi](https://github.com/sadekbaroudi/) |
| [pmw3610-xxs](https://github.com/sadekbaroudi/vik/tree/master/pcb/pmw3610-xxs/) | Trackball (for wireless boards) | Complete | Open source | [ykz89](https://github.com/ykz89/) |
| [vikropad](https://github.com/sadekbaroudi/vik/tree/master/pcb/vikropad/) | Macropad (18 key) with 2x 5 way switches | Complete | Open source | [Sadek Baroudi](https://github.com/sadekbaroudi/) |
| [solenoid-1](https://github.com/sadekbaroudi/vik/tree/master/pcb/solenoid/) | Solenoid module using 3.3v or 5v and 1 gpio | Complete | Open source | [Sadek Baroudi](https://github.com/sadekbaroudi/) |
| [solenoid-2](https://github.com/sadekbaroudi/vik/tree/master/pcb/solenoid/) | Solenoid module using 5v and 1 gpio | Complete | Open source | [Aleblazer](https://github.com/Aleblazer/) |
| [peacock trackpad](https://github.com/george-norton/peacock) | Large trackpad module | Complete | Open source | [George Norton](https://github.com/george-norton) |
| [procyon trackpad](https://github.com/george-norton/procyon) | multi touch trackpad module | Complete | Open source | [George Norton](https://github.com/george-norton) |
| [vik-splitter](https://github.com/sadekbaroudi/vik/tree/master/pcb/vik-splitter/) | module to split one vik in connector to two vik outs | Untested | Open source | [Sadek Baroudi](https://github.com/sadekbaroudi/) |

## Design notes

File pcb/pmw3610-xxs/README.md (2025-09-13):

# PMW3610 trackball pcb - xxs version

## Overview

This module is similar to the other PMW3610 modules, but even smaller. It is the same size as the sensor PCB used in the [KeyBall](https://github.com/Yowkees/keyball) and its derative [roBa](https://github.com/kumamuk-git/roBa). This module was modified from the PMW3610 breakout module of the latter.
Do note that because of the connector size, the KeyBall trackball holder does need a small adjustment.

This is a VIK module to use a PMW3610 low power motion sensor. This sensor is primarily used for mousing applications. The most common use in the keyboard community is for (wireless) trackballs.

Note that while I2C, RGB, and extra GPIO are broken out, but are not used in the circuitry, so they are not needed for the sensor. There are also footprints for I2C pull up resistors, which are also not needed, as I2C is not used.

## IMPORTANT

The PMW3610 sensor is a low power sensor, and uses serial data communication with a motion status pin (to reduce power consumption). This pcb uses the SPI pins, but is not standard SPI communication. This means that you cannot connect this module to a controller or board that uses the VIK SPI pins for any other purpose. These are being treated as standard GPIO for this module. This is not a VIK compliant module!

That said, if you understand the above, you can still use this module with no issues.

## Fabrication and BOM

For PCB fabrication, you can use the files in the jlcpcb/production_files folder.

* `GERBER-pmw3610_xxs.zip` - the file used to fabricate the pcb
* `BOM-pmw3610_xxs.csv` - used for PCBA. You can also use the part numbers in this file to look up the exact parts as [lcsc.com](https://lcsc.com)
* `CPL-pmw3610_xxs.csv` - used for PCBA

Using the 3 files above, this has been tested at [jlcpcb.com](https://jlcpcb.com)
These files were generated by the [KiCAD JLCPCB tools plugin](https://github.com/Bouni/kicad-jlcpcb-tools).

## PCB images

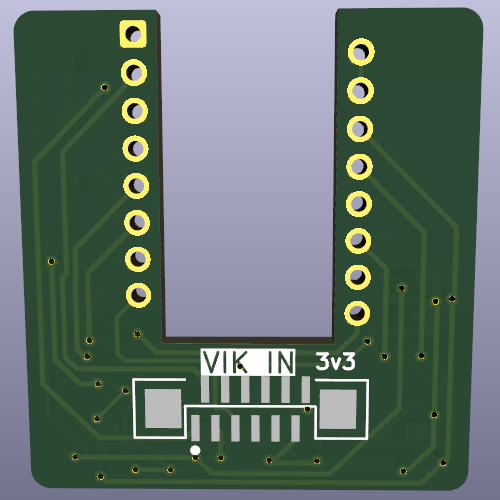
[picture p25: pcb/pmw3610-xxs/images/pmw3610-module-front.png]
pcb front


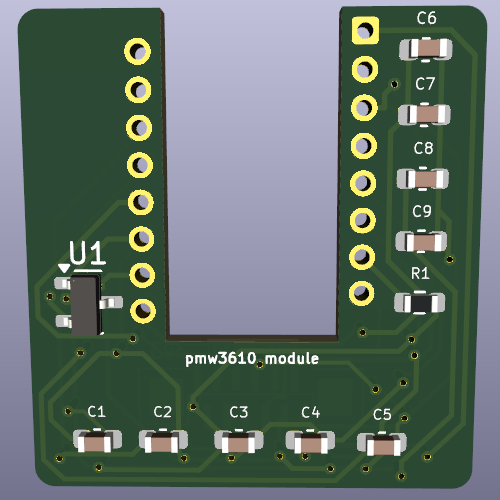
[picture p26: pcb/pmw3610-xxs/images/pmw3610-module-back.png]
pcb back


To view the PCB and schematics without using KiCad copy this module's url in https://kicanvas.org or click [here](https://kicanvas.org/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).

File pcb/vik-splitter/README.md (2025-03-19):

# vik-splitter

## Overview

This is a very simple pcb that takes in a VIK cable for input, and redirects them to two outputs.

Please note that *you* are responsible for ensuring that the two output modules don't conflict with each other.

Examples of using valid uses would be:
* Using one output module that uses SPI only, and one output module that uses I2C only
* Using two output modules that both only use I2C (but you should be aware of the pull up resistor values when combining two I2C modules
* Using one module that uses GP1 and GP2, and another module that uses SPI

Examples of invalid uses:
* Using two output modules that both use SPI (only because the CS pin can't be shared between them)
* Using one module that uses I2C and GP1, and another module that uses SPI and GP1

## Fabrication and BOM

For PCB fabrication, you can use the files in the production folder.

* vik-splitter.zip - the gerber file used to fabricate the pcb
* bom.csv - used for PCBA. You can also use the part numbers in this file to look up the exact parts as [lcsc.com](https://lcsc.com)
* positions.csv - used for PCBA

Using the 3 files above, this has been tested at [jlcpcb.com](https://jlcpcb.com)

## VIK module certification

| Category | Classification | Response |
| --- | --- | --- |
| FPC connector | Required | :heavy_check_mark: |
| Breakout pins | Recommended | :heavy_check_mark: |
| Uses: SPI | Optional | :heavy_check_mark: |
| SPI used for SPI only | Strongly recommended | N/A |
| Uses: I2C | Optional | N/A |
| I2C used for I2C only | Strongly Recommended | N/A |
| I2C pull ups | Required | N/A |
| Uses: RGB | Optional | N/A |
| Uses: Extra GPIO 1 | Optional | N/A |
| Uses: Extra GPIO 2 | Optional | N/A |
| Standard PCB Size/Mount | Strongly recommended | :heavy_check_mark: |

Note that all of the `N/A` values above are there only because they are dependent on the modules being connected on the VIK OUT connectors.

## PCB images

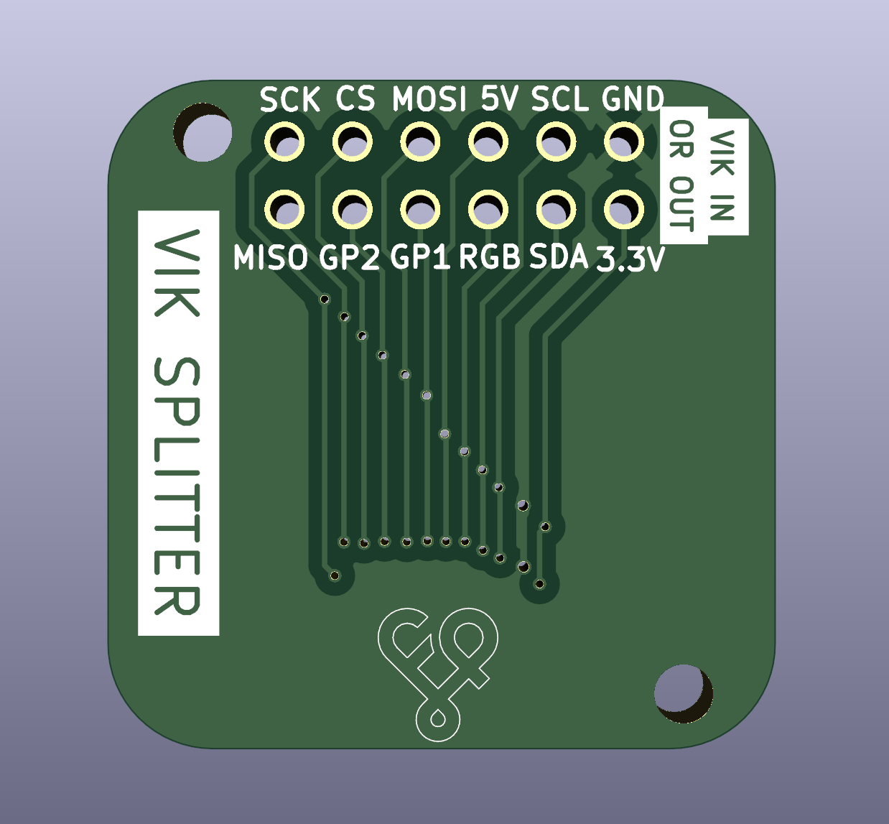
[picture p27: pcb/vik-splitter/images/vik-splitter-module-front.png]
pcb front


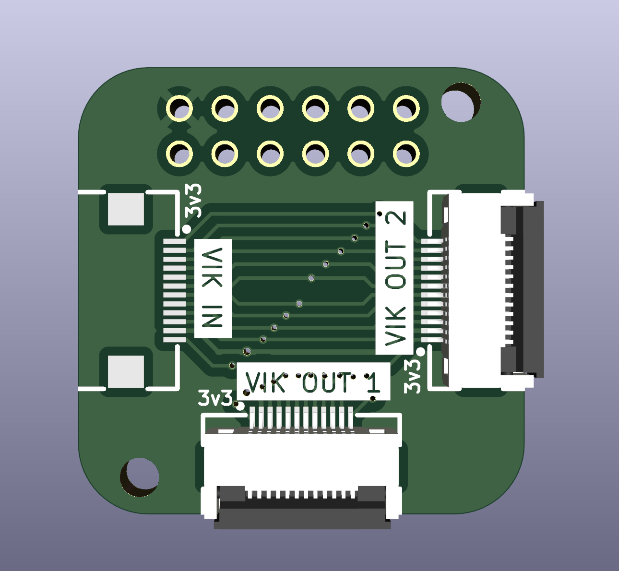
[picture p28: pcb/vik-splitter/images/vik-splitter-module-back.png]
pcb back


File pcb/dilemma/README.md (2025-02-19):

# Dilemma keyboard

This design is for the [dilemma keyboard](https://github.com/Bastardkb/Dilemma/tree/features/dilemma_3x0) by [Quentin](https://github.com/Bastardkb).

Git repository and branch reviewed:
https://github.com/Bastardkb/Dilemma/tree/features/dilemma_3x0/3x5_3

Notes:
* This keyboard requires a Type B fpc cable, instead of a Type A.
* If connecting an LCD to the keyboard with the breakout pins, you cannot use the SPI MOSI function through VIK on that half

## Controller pcb certification

| Category | Classification | Response |
| ---  | --- | --- |
| FPC connector | Required | :heavy_check_mark: |
| Breakout pins | Recommended | Partial |
| Supplies: SPI | Required | :heavy_check_mark: |
| Supplies: I2C | Required | :heavy_check_mark: |
| I2C on main PCB | Discouraged | :x: |
| I2C pull ups | Informative | 4.7k |
| Supplies: RGB | Required | :heavy_check_mark: |
| Supplies: Extra GPIO 1 | Required | Digital only |
| Supplies: Extra GPIO 2 | Required | Digital only |

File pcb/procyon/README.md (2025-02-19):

# Procyon trackpad

This design is a trackpad vik module. For a description of the design, schematics, pcb, and usage, see the git repository below.

Git repository:  
https://github.com/george-norton/procyon

## Module certification

| Category | Classification | Response |
| --- | --- | --- |
| FPC connector | Required | :heavy_check_mark: |
| Breakout pins | Recommended | :x: |
| Uses: SPI | Optional | :heavy_check_mark: |
| SPI used for SPI only | Strongly recommended | :heavy_check_mark: |
| Uses: I2C | Optional | :heavy_check_mark: |
| I2C used for I2C only | Strongly Recommended | :heavy_check_mark: |
| I2C pull ups | Required | 3.3k |
| Uses: RGB | Optional | :x: |
| Uses: Extra GPIO 1 | Optional | :heavy_check_mark: |
| Uses: Extra GPIO 2 | Optional | :heavy_check_mark: |
| Standard PCB Size/Mount | Strongly recommended | :x: |

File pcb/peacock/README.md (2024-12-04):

# Peacock trackpad

This design includes both a controller pcb and a vik module, integrated into one. So, there will be certifications on both.

Git repository:  
https://github.com/george-norton/peacock

Schematics and pcb image available in the github repo

## Controller pcb certification

| Category | Classification | Response |
| ---  | --- | --- |
| FPC connector | Required | :heavy_check_mark: |
| Breakout pins | Recommended | :heavy_check_mark: |
| Supplies: SPI | Required | :heavy_check_mark: |
| Supplies: I2C | Required | :heavy_check_mark: |
| I2C on main PCB | Discouraged | :x: |
| I2C pull ups | Informative | N/A |
| Supplies: RGB | Required | :heavy_check_mark: |
| Supplies: Extra GPIO 1 | Required | Analog/Digital |
| Supplies: Extra GPIO 2 | Required | Analog/Digital |

## Module pcb certification

| Category | Classification | Response |
| --- | --- | --- |
| FPC connector | Required | :heavy_check_mark: |
| Breakout pins | Recommended | :heavy_check_mark: |
| Uses: SPI | Optional | :x: |
| SPI used for SPI only | Strongly recommended | N/A |
| Uses: I2C | Optional | :heavy_check_mark: |
| I2C used for I2C only | Strongly Recommended | :heavy_check_mark: |
| I2C pull ups | Required | 3.3k |
| Uses: RGB | Optional | :x: |
| Uses: Extra GPIO 1 | Optional | :heavy_check_mark: |
| Uses: Extra GPIO 2 | Optional | :x: |
| Standard PCB Size/Mount | Strongly recommended | :x: |

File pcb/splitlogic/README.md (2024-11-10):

# Split Logic Keyboards

## ZodiarkPi

https://www.splitlogic.xyz/shop/splitlogic/p/zodiarkpi

| Category | Classification | Response |
| ---  | --- | --- |
| FPC connector | Required | :heavy_check_mark: |
| Breakout pins | Recommended | :x: |
| Supplies: SPI | Required | :heavy_check_mark: |
| Supplies: I2C | Required | :heavy_check_mark: |
| I2C on main PCB | Discouraged | :heavy_check_mark: |
| I2C pull ups | Informative | 4.7kΩ |
| Supplies: RGB | Required | :heavy_check_mark: |
| Supplies: Extra GPIO 1 | Required | Analog/Digital |
| Supplies: Extra GPIO 2 | Required | Analog/Digital |

Note: VIK standard is enabled by 4 jumpers.

## ZodiPact

https://www.splitlogic.xyz/shop/splitlogic/p/zodipact-pcb-kit

| Category | Classification | Response |
| ---  | --- | --- |
| FPC connector | Required | :heavy_check_mark: |
| Breakout pins | Recommended | :x: |
| Supplies: SPI | Required | :heavy_check_mark: |
| Supplies: I2C | Required | :heavy_check_mark: |
| I2C on main PCB | Discouraged | :x: |
| I2C pull ups | Informative | N/A |
| Supplies: RGB | Required | :heavy_check_mark: |
| Supplies: Extra GPIO 1 | Required | Analog/Digital |
| Supplies: Extra GPIO 2 | Required | Analog/Digital |

Note: VIK 5V is enabled by a jumper.

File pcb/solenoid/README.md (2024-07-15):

# solenoid

## vik repo version

### Overview (sadek version)

This is a VIK module by [sadekbaroudi](https://github.com/sadekbaroudi) to add a solenoid to a VIK enabled board or controller. It has the option to use 3.3v or 5v from VIK using a jumper, and additionally requires GND and GPIO_AD1.

### Fabrication and BOM (sadek version)

For PCB fabrication, you can use the files in the production folder.

* gerbers.zip - the file used to fabricate the pcb
* bom.csv - used for PCBA. You can also use the part numbers in this file to look up the exact parts as [lcsc.com](https://lcsc.com)
* positions.csv - used for PCBA

Using the 3 files above, this has been tested at [jlcpcb.com](https://jlcpcb.com)

For the parts not listed in the bom, you'll need the following:

| Quantity | Part name / number | Example URL for purchase |
| --- | --- | --- |
| 1 | TIP120 - NPN Transistor | https://www.aliexpress.us/item/2251832720365467.html |
| 1 | 2.2K Ohm resistor | https://www.aliexpress.us/item/3256802900888178.html |
| 1 | 1N4001 Rectifier Diode | https://www.aliexpress.us/item/3256805759330925.html |

### VIK module certification (sadek version)

| Category | Classification | Response |
| --- | --- | --- |
| FPC connector | Required | :heavy_check_mark: |
| Breakout pins | Recommended | :x: |
| Uses: SPI | Optional | :x: |
| SPI used for SPI only | Strongly recommended | :x: |
| Uses: I2C | Optional | :x: |
| I2C used for I2C only | Strongly Recommended | :x: |
| I2C pull ups | Required | :x: |
| Uses: RGB | Optional | :x: |
| Uses: Extra GPIO 1 | Optional | :heavy_check_mark: |
| Uses: Extra GPIO 2 | Optional | :x: |
| Standard PCB Size/Mount | Strongly recommended | Small |

## PCB images (sadek version)

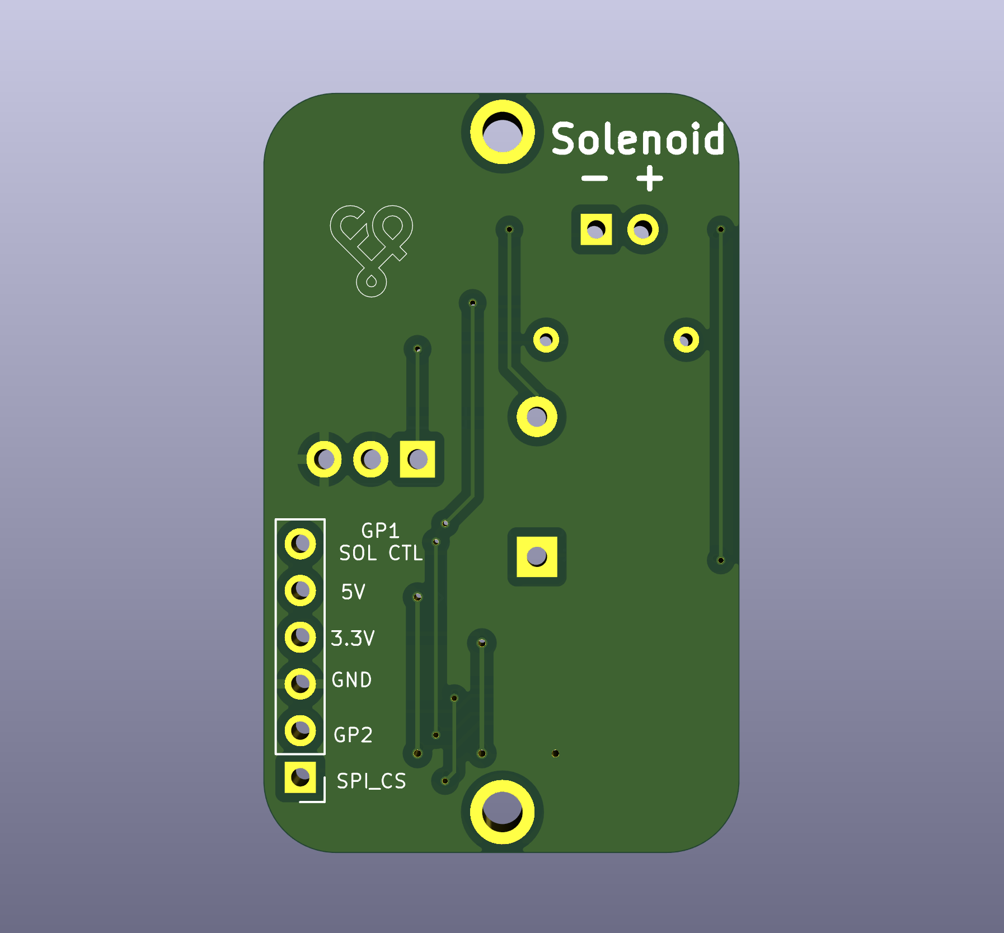
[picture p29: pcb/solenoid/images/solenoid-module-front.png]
pcb front


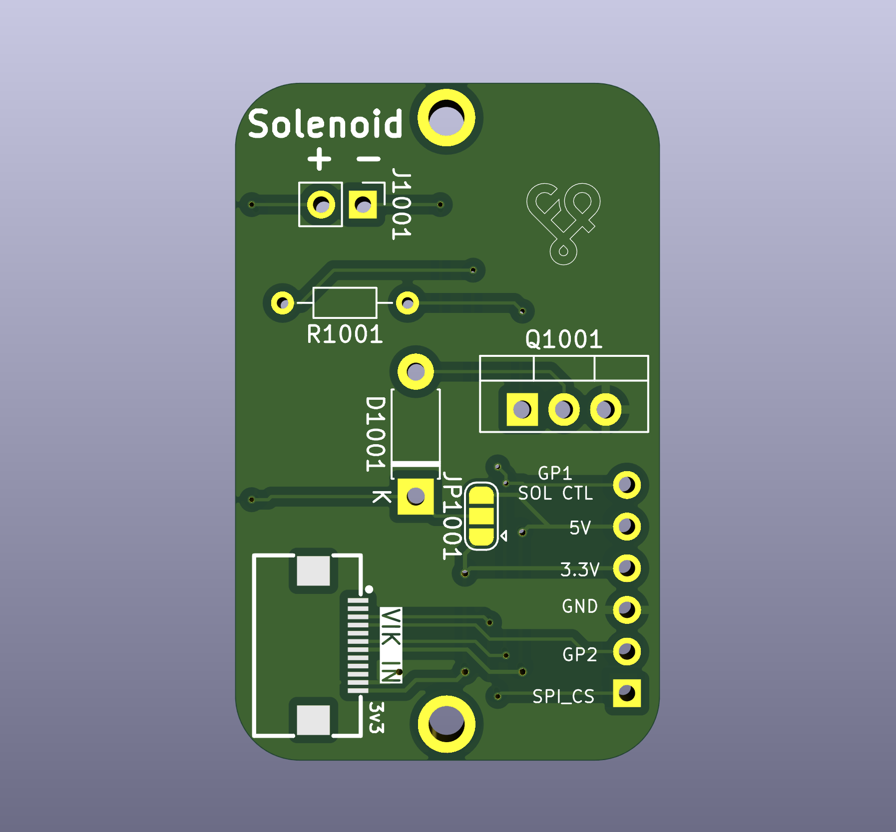
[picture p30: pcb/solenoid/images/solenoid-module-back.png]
pcb back


## aleblazer version

### Overview (aleblazer version)

This is a VIK module created by [Aleblazer](https://github.com/Aleblazer) to add a solenoid to a controller. It requires 5V, GND, and the GPIO_AD1 VIK connection.

### Details (aleblazer version)

Please refer to the [VIK-solenoid repo](https://github.com/Aleblazer/VIK-Solenoid) for any necessary details.

Note that as of this writing, there is also a VIK xs (extra small) version in the [ExtraSmallVIK branch](https://github.com/Aleblazer/VIK-Solenoid/tree/ExtraSmallVIK)

### VIK module certification (aleblazer version)

| Category | Classification | Response |
| --- | --- | --- |
| FPC connector | Required | :heavy_check_mark: |
| Breakout pins | Recommended | :x: |
| Uses: SPI | Optional | :x: |
| SPI used for SPI only | Strongly recommended | :x: |
| Uses: I2C | Optional | :x: |
| I2C used for I2C only | Strongly Recommended | :x: |
| I2C pull ups | Required | :x: |
| Uses: RGB | Optional | :x: |
| Uses: Extra GPIO 1 | Optional | :heavy_check_mark: |
| Uses: Extra GPIO 2 | Optional | :x: |
| Standard PCB Size/Mount | Strongly recommended | Small/XS |

### PCB images (aleblazer version)

See repo linked above

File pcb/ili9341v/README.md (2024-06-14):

# ILI9341 display VIK module

## Overview

This is a VIK module made to add a VIK connector to the [ILI9341](https://www.aliexpress.us/item/3256805692275620.html) board ([alternate link](https://www.aliexpress.us/item/3256805720349132.html))

## Display housing 3D models

I have put together [display housings and covers](https://github.com/sadekbaroudi/fingerpunch/tree/master/3d-models/display-housings/ili9341) for this module, in the form of step files that you can download and incorporate into your own design.

## Fabrication and BOM

For PCB fabrication, you can use the files in the production folder.

* gerbers.zip - the file used to fabricate the pcb
* bom.csv - used for PCBA. You can also use the part numbers in this file to look up the exact parts as [lcsc.com](https://lcsc.com)
* positions.csv - used for PCBA

Using the 3 files above, this has been tested at [jlcpcb.com](https://jlcpcb.com)

# Display module dimensions

Look inside the `./images/` directory for dimensions for the various modules that this has been tested to work with. These images were all pulled from [lcdwiki.org](http://www.lcdwiki.com/Main_Page)

## VIK module certification

| Category | Classification | Response |
| --- | --- | --- |
| FPC connector | Required | :heavy_check_mark: |
| Breakout pins | Recommended | :x: |
| Uses: SPI | Optional | :heavy_check_mark: |
| SPI used for SPI only | Strongly recommended | :heavy_check_mark: |
| Uses: I2C | Optional | :heavy_check_mark: |
| I2C used for I2C only | Strongly Recommended | :heavy_check_mark: |
| I2C pull ups | Required | :x: |
| Uses: RGB | Optional | :x: |
| Uses: Extra GPIO 1 | Optional | :heavy_check_mark: |
| Uses: Extra GPIO 2 | Optional | :heavy_check_mark: |
| Standard PCB Size/Mount | Strongly recommended | :x: |

## PCB images

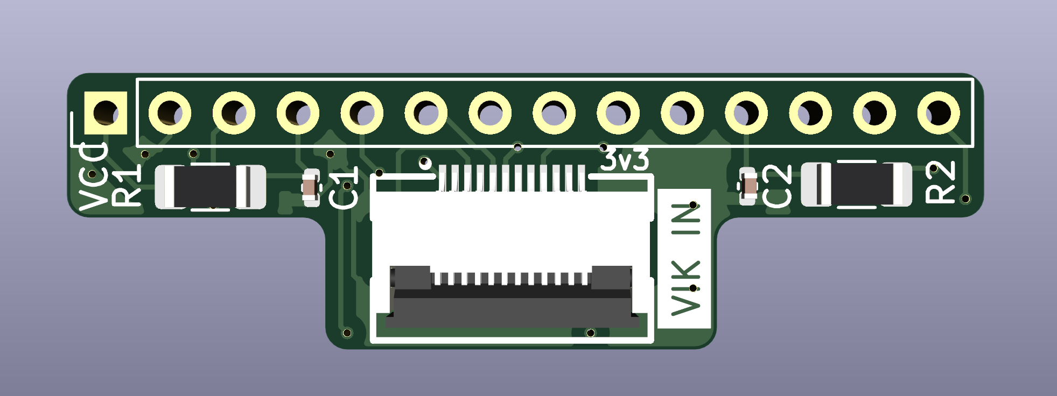
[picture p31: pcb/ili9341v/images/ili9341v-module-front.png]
pcb front


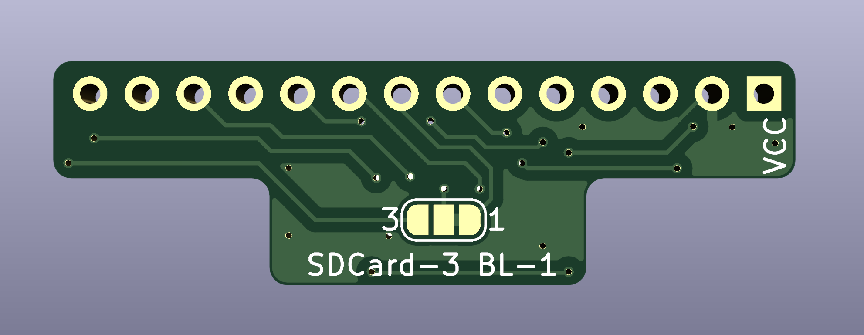
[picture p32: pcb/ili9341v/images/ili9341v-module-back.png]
pcb back


## Assembled image

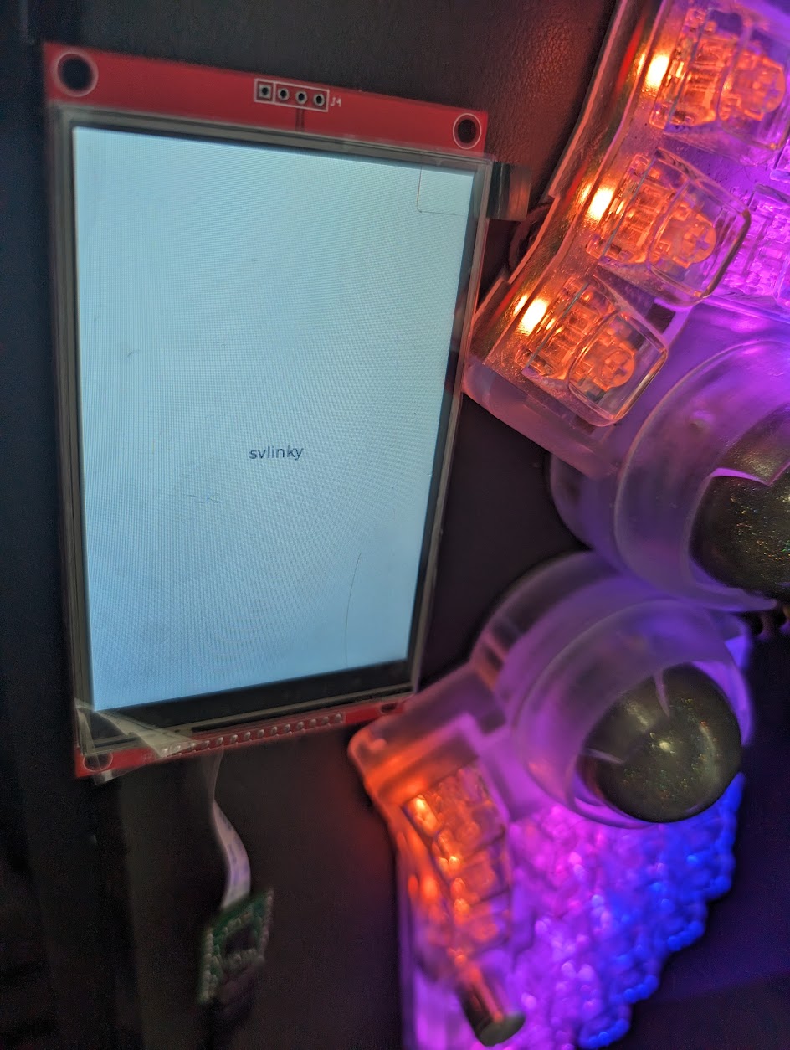
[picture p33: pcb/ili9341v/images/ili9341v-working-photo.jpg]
assembled


## Product images

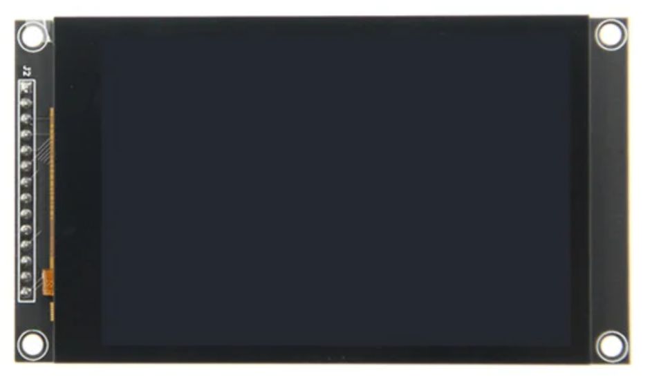
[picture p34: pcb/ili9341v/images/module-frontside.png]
pcb front


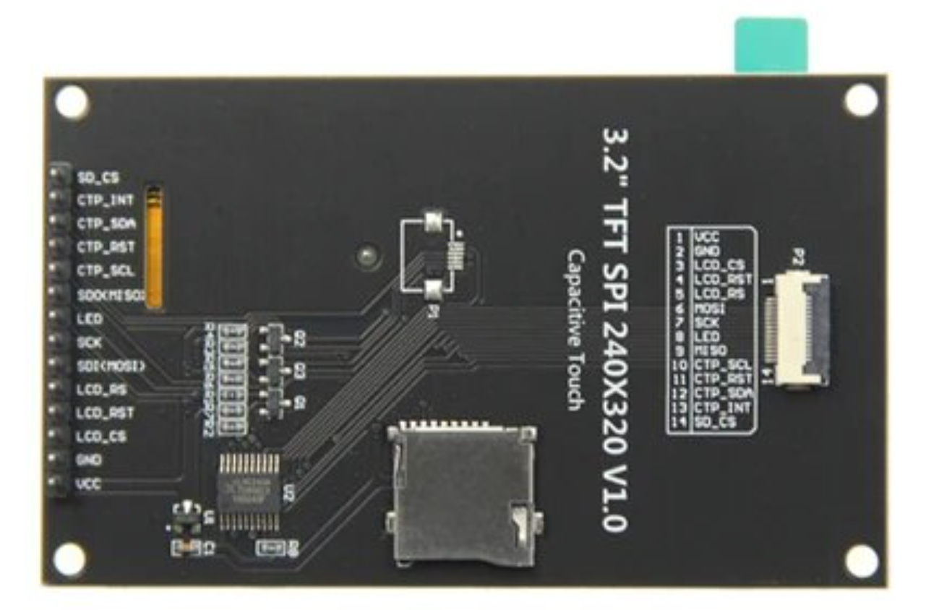
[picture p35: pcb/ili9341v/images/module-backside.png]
pcb back


## Product Spec images

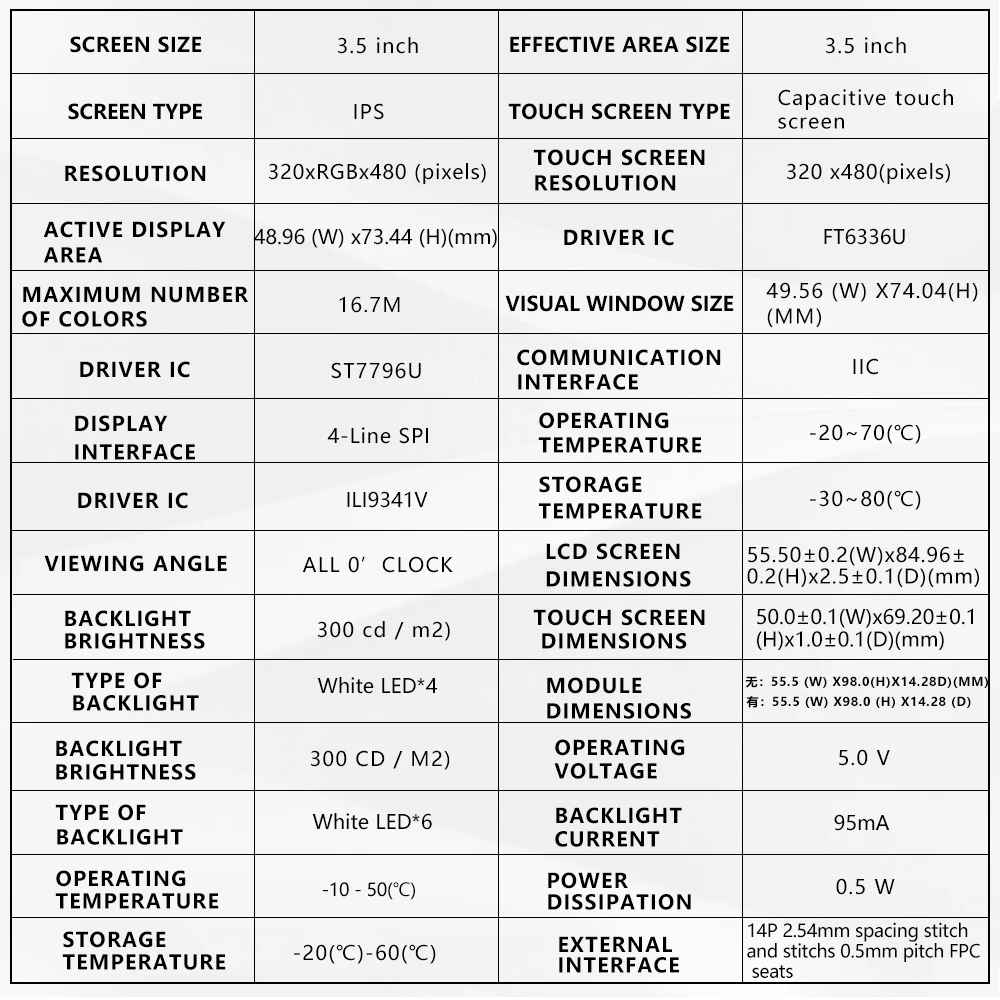
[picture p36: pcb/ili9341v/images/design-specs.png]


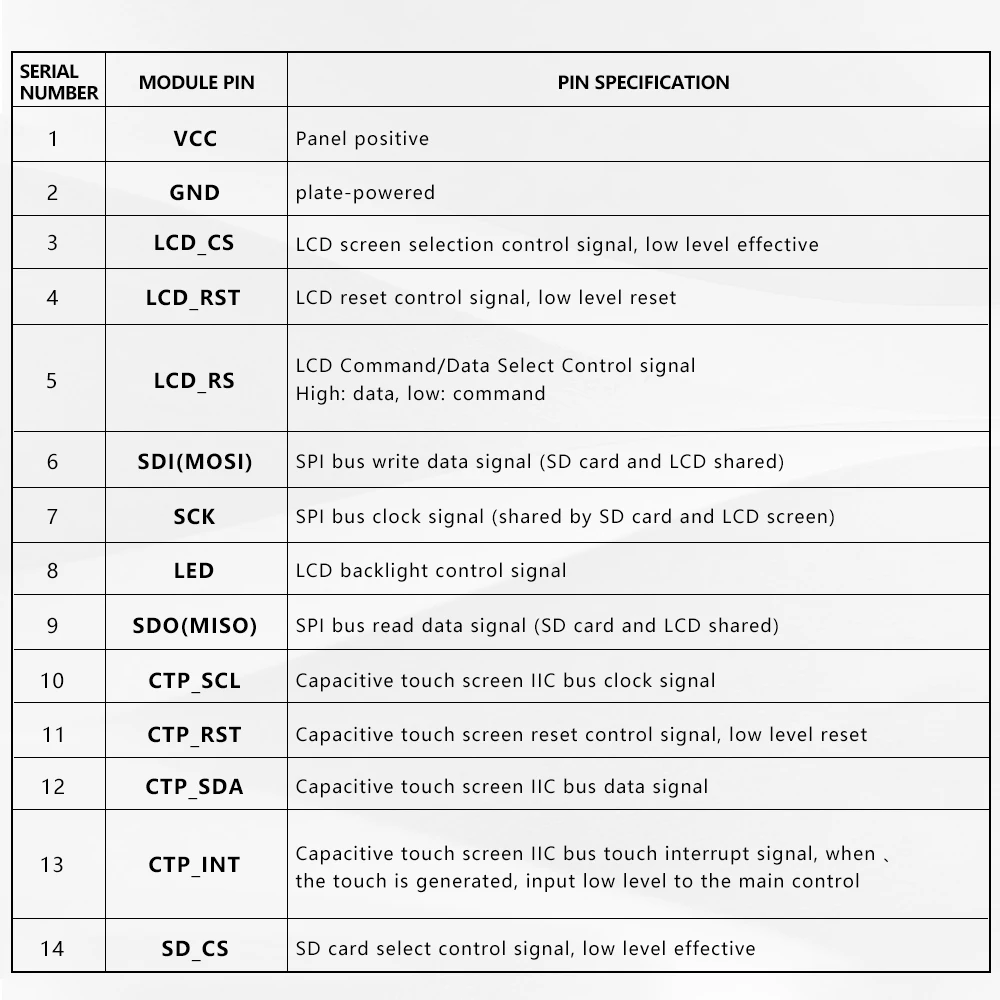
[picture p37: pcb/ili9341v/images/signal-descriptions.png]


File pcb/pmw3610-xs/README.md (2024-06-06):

# PMW3610 trackball pcb - xs version

## Overview

First and foremost, note that this module is identical to the PMW3610 module, except in a extra small (xs) form factor.

This is a VIK module to use a PMW3610 motion sensor. This sensor is primarily used for mousing applications.

The most common use in the keyboard community is for trackballs.

Note that while I2C, RGB, and extra GPIO are broken out, but are not used in the circuitry, so they are not needed for the sensor. There are also footprints for I2C pull up resistors, which are also not needed, as I2C is not used.

There is a jumper for NRESET, with an option to:  
* Route to 3.3V, which means that it's inactive
* Route to the VIK GPIO 1, which allows you to control the state with the connected controller

You do not need to solder the jumper at all, since there is a weak pull up resistor in the PMW3610, but if you have any trouble with the state, and want to explicitly attach to 3.3V, you can.

## IMPORTANT

The PMW3610 sensor is a low power sensor, and uses serial data communication with a motion status pin (to reduce power consumption). This pcb uses the SPI pins, but is not standard SPI communication. This means that you cannot connect this module to a controller or board that uses the VIK SPI pins for any other purpose. These are being treated as standard GPIO for this module. This is not a VIK compliant module!

That said, if you understand the above, you can still use this module with no issues.

## Alternate parts

The LDO seems to be frequently out of stock at JLCPCB. The part number specified in this module is `C146366`. As an alternate part, you can try to use `C2862411` or `C2869109` (`TLV70019DDCR` or `TLV70019DDCT`, respectively)

## Fabrication and BOM

For PCB fabrication, you can use the files in the production folder.

* gerbers.zip - the file used to fabricate the pcb
* bom.csv - used for PCBA. You can also use the part numbers in this file to look up the exact parts as [lcsc.com](https://lcsc.com)
* positions.csv - used for PCBA

Using the 3 files above, this has been tested at [jlcpcb.com](https://jlcpcb.com)

## VIK module certification

| Category | Classification | Response |
| --- | --- | --- |
| FPC connector | Required | :heavy_check_mark: |
| Breakout pins | Recommended | :heavy_check_mark: |
| Uses: SPI | Optional | :heavy_check_mark: |
| SPI used for SPI only | Strongly recommended | :x: |
| Uses: I2C | Optional | :x: |
| I2C used for I2C only | Strongly Recommended | :x: |
| I2C pull ups | Required | N/A |
| Uses: RGB | Optional | :x: |
| Uses: Extra GPIO 1 | Optional | :x: |
| Uses: Extra GPIO 2 | Optional | :x: |
| Standard PCB Size/Mount | Strongly recommended | Small |

## PCB images

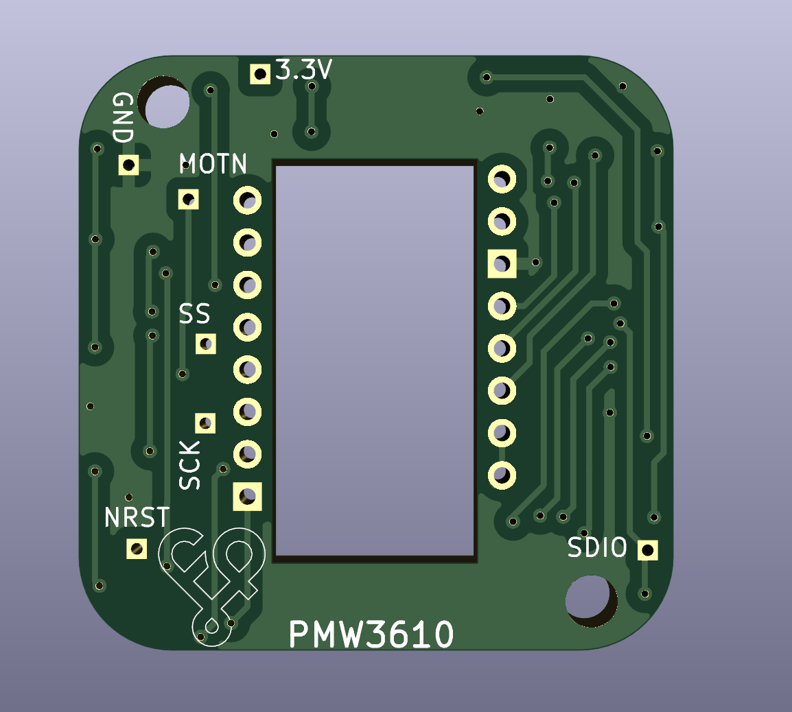
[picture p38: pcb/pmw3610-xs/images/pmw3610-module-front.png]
pcb front


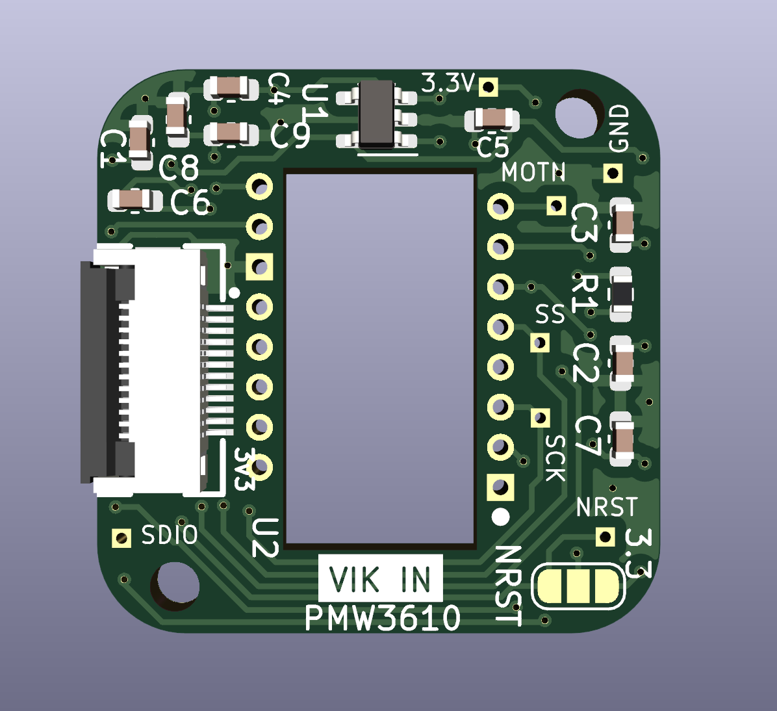
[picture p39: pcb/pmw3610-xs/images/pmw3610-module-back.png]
pcb back


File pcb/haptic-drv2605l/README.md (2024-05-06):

# Haptic feedback DRV2605L module

## Overview

This is a VIK module made to house the DRV2605L motor controller for haptic feedback.

DRV2605L controller uses only I2C communication, so the module may serve as a VIK pass-through allowing a next module to be connected.

Module adheres to default small PCB size and mounting with additional holes for FFC cable which can also be used for breaking off mounting holes if even smaller size is needed.

## Fabrication

For PCB fabrication, you can use the files in the production folder.

- [haptic-drv2605l.zip](./production/haptic-drv2605l.zip) - the file used to fabricate the pcb

## BOM

- DRV2605L motor controller
- 2 1uF capacitors (SMD 1206 size)
- 2 4.7kOhm resistors (SMD 1206 size)
- vertical and horizontal VIK connectors
- LRA or ERM [motor](https://docs.qmk.fm/#/feature_haptic_feedback?id=known-supported-hardware)

## VIK module certification

| Category | Classification | Response |
| --- | --- | --- |
| FPC connector | Required | :heavy_check_mark: |
| Breakout pins | Recommended | :x: |
| Uses: SPI | Optional | :x: |
| SPI used for SPI only | Strongly recommended | N/A |
| Uses: I2C | Optional | :heavy_check_mark: |
| I2C used for I2C only | Strongly Recommended | :heavy_check_mark: |
| I2C pull ups | Required | 4.7kΩ <sup>[1]</sup> |
| Uses: RGB | Optional | :x: |
| Uses: Extra GPIO 1 | Optional | :x: |
| Uses: Extra GPIO 2 | Optional | :x: |
| Standard PCB Size/Mount | Strongly recommended | Small |

**[1]**: I2C pull ups can be enabled/disabled with solder jumpers

## Images

#### Renders

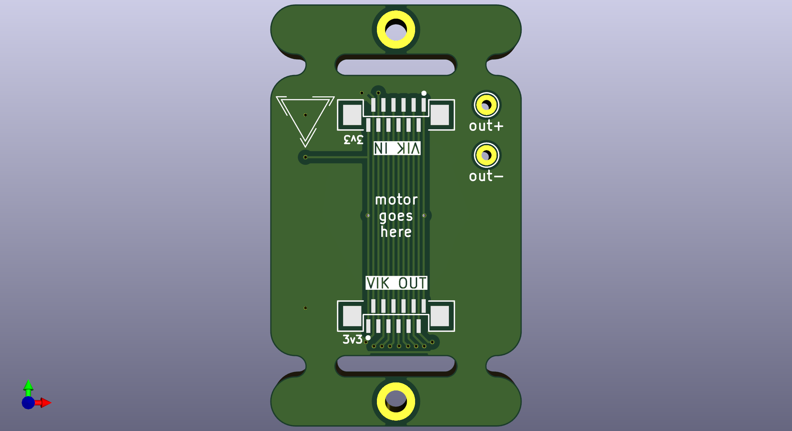
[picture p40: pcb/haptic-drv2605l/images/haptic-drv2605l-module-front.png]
pcb front


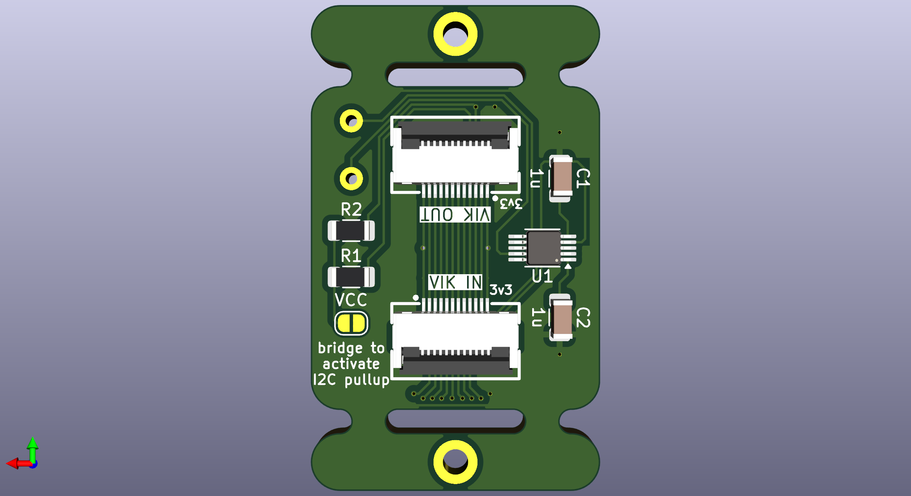
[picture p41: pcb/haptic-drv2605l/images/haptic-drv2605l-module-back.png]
pcb back


#### Soldered PCB

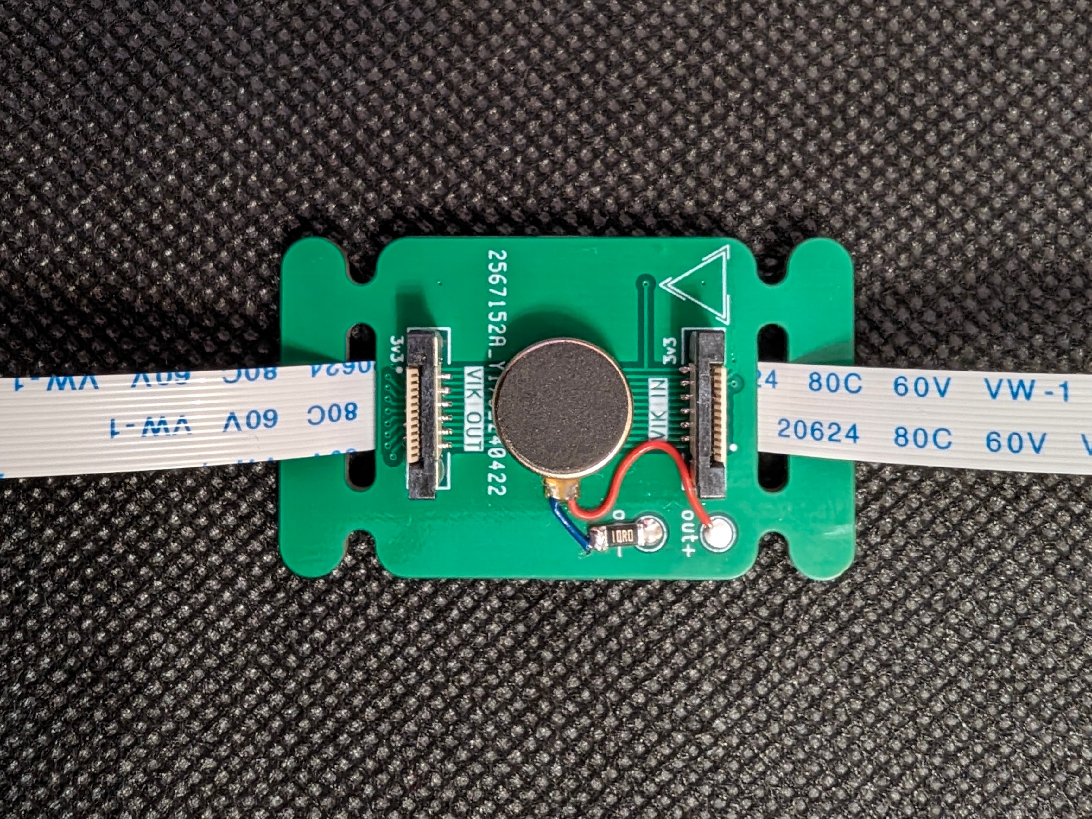
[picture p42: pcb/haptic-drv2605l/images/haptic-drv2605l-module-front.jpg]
pcb front


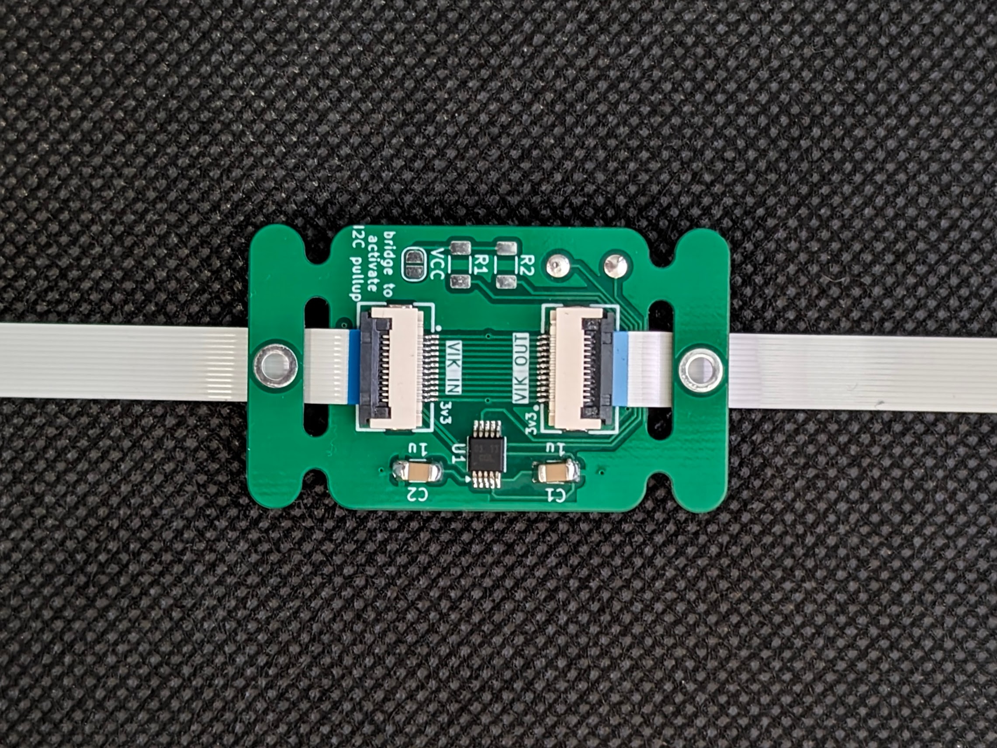
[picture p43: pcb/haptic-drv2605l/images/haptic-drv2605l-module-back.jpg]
pcb back


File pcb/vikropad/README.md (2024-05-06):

# vikropad

## Overview

This is a VIK module designed to demonstrate a macropad using 2 shift registers for the columns, and using VIK GPIO AD1 and GPIO AD2 for the rows.

It requires some custom firmware to handle the matrix scanning, as it's independent of whatever keyboard you connect this to.

It includes:  
* 2x 74hc595 shift register (THT or SMD)
* [2x 5 way switch hat](https://www.adafruit.com/product/504), e.g. adafruit 504
* MX/Choc V1/Gateron low profile switch footprint, both hotswap and solderable

All pins are broken out (except RGB), either via the shift registers or extra through holes.

## Fabrication and BOM

For PCB fabrication, you can use the files in the production folder.

* gerbers.zip - the file used to fabricate the pcb
* bom.csv - used for PCBA. You can also use the part numbers in this file to look up the exact parts as [lcsc.com](https://lcsc.com)
* positions.csv - used for PCBA

Using the 3 files above, this has been tested at [jlcpcb.com](https://jlcpcb.com)

## vikropad case files

You can find the [vikropad case files](https://github.com/sadekbaroudi/fingerpunch/tree/master/keyboards/vikropad) in the fingerpunch github repository

## VIK module certification

| Category | Classification | Response |
| --- | --- | --- |
| FPC connector | Required | :heavy_check_mark: |
| Breakout pins | Recommended | :heavy_check_mark: |
| Uses: SPI | Optional | :heavy_check_mark: |
| SPI used for SPI only | Strongly recommended | :heavy_check_mark: |
| Uses: I2C | Optional | :x: |
| I2C used for I2C only | Strongly Recommended | N/A |
| I2C pull ups | Required | :heavy_check_mark: |
| Uses: RGB | Optional | :heavy_check_mark: |
| Uses: Extra GPIO 1 | Optional | :heavy_check_mark: |
| Uses: Extra GPIO 2 | Optional | :heavy_check_mark: |
| Standard PCB Size/Mount | Strongly recommended | :x: |

## PCB images

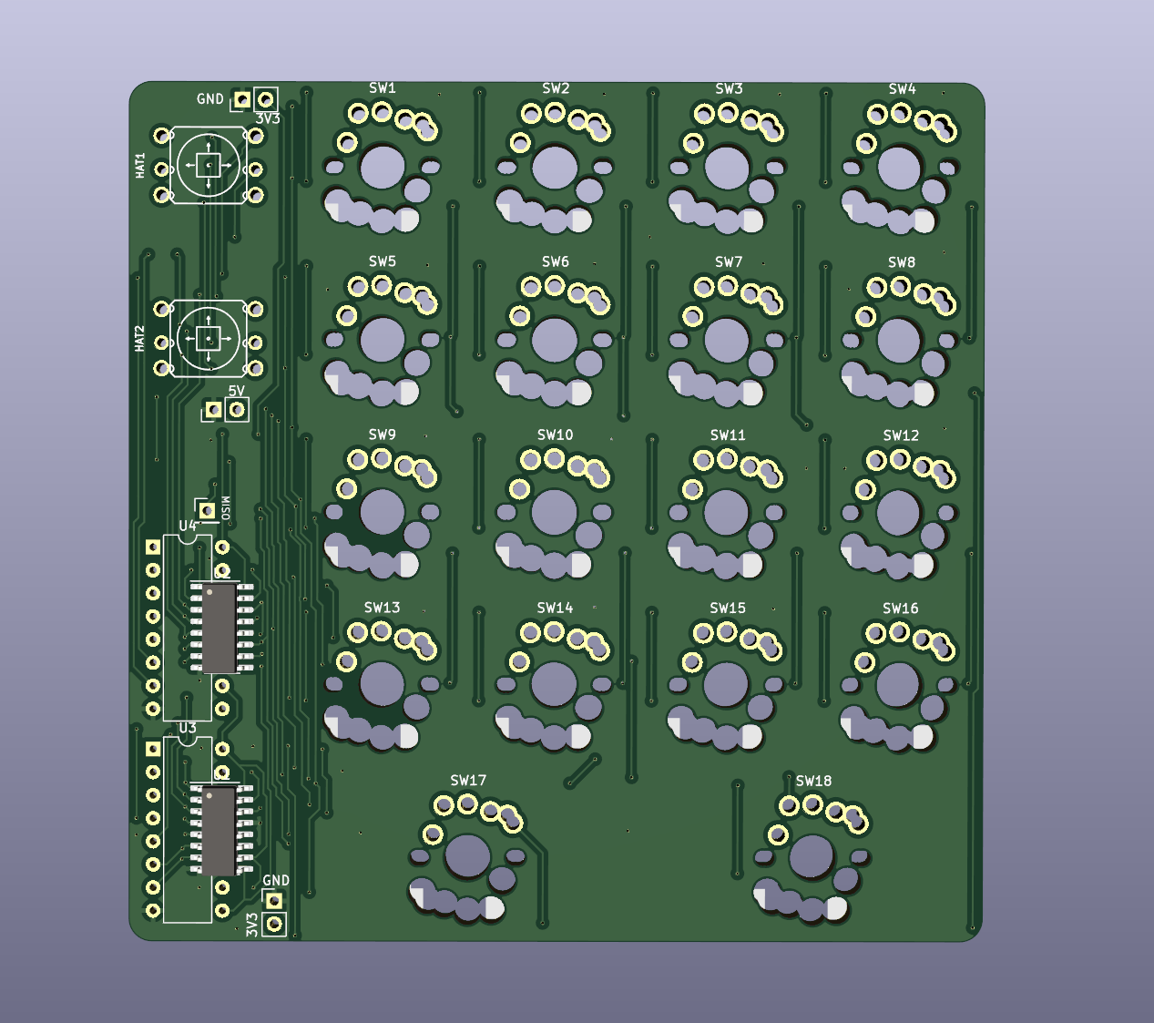
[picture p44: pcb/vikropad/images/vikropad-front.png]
pcb front


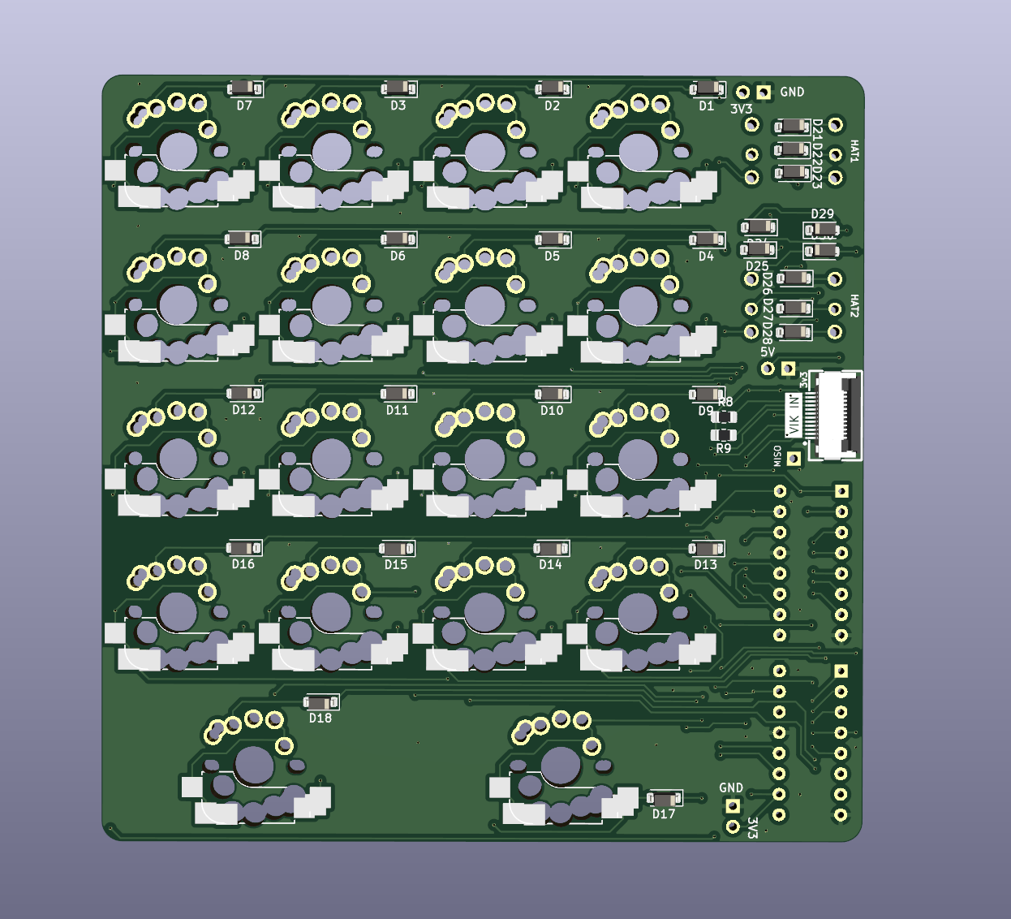
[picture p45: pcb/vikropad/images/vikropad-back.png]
pcb back


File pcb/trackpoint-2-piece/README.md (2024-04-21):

# Trackpoint 2 piece module

## Overview

This is a VIK module made to connect the [trackpoint 2 piece](https://deskthority.net/wiki/TrackPoint_Hardware#2-piece_Trackpoint) breakout board.

The through holes should be used if connecting this to a controller that uses 5v logic. The VIK connector is assumed to be connecting to a 3.3v controller, so the logic levels are 3.3v.

The overall design is as follows:
* VIK uses 3.3V, so the 3.3V through holes all goes to the VIK connector, since VIK expects 3.3V logic.
* The mosfets (etc) convert the 3.3V logic to 5V logic (and the other way around), so none of the 5V through holes are connected to the VIK connector. The trackpoint expects 5V logic
* The 5V logic is all connected directly to the trackpoint, since as mentioned, the trackpoint expects 5V, and VIK does not

The general usage of this is:
* If you are connecting to a 5V controller, you just use the 5V through holes. You can't use the VIK connector
* If you are connecting to a 3.3V controller, you can use either VIK connector or the 3.3V through holes

## Fabrication and BOM

For PCB fabrication, you can use the files in the production folder.

* gerbers.zip - the file used to fabricate the pcb
* bom.csv - used for PCBA. You can also use the part numbers in this file to look up the exact parts as [lcsc.com](https://lcsc.com)
* positions.csv - used for PCBA

Using the 3 files above, this has been tested at [jlcpcb.com](https://jlcpcb.com)

## VIK module certification

| Category | Classification | Response |
| --- | --- | --- |
| FPC connector | Required | :heavy_check_mark: |
| Breakout pins | Recommended | :x: |
| Uses: SPI | Optional | :x: |
| SPI used for SPI only | Strongly recommended | N/A |
| Uses: I2C | Optional | :x: |
| I2C used for I2C only | Strongly Recommended | :x: |
| I2C pull ups | Required | :x: |
| Uses: RGB | Optional | :x: |
| Uses: Extra GPIO 1 | Optional | :heavy_check_mark: |
| Uses: Extra GPIO 2 | Optional | :heavy_check_mark: |
| Standard PCB Size/Mount | Strongly recommended | :x: |

## PCB images

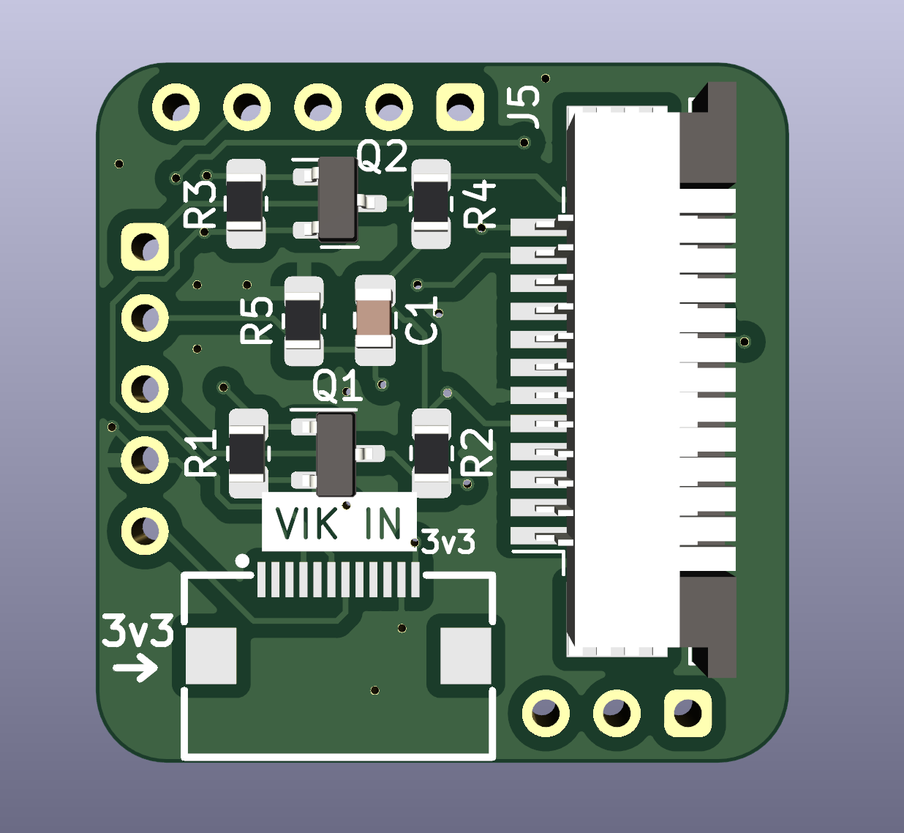
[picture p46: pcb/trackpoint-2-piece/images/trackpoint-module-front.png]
pcb front


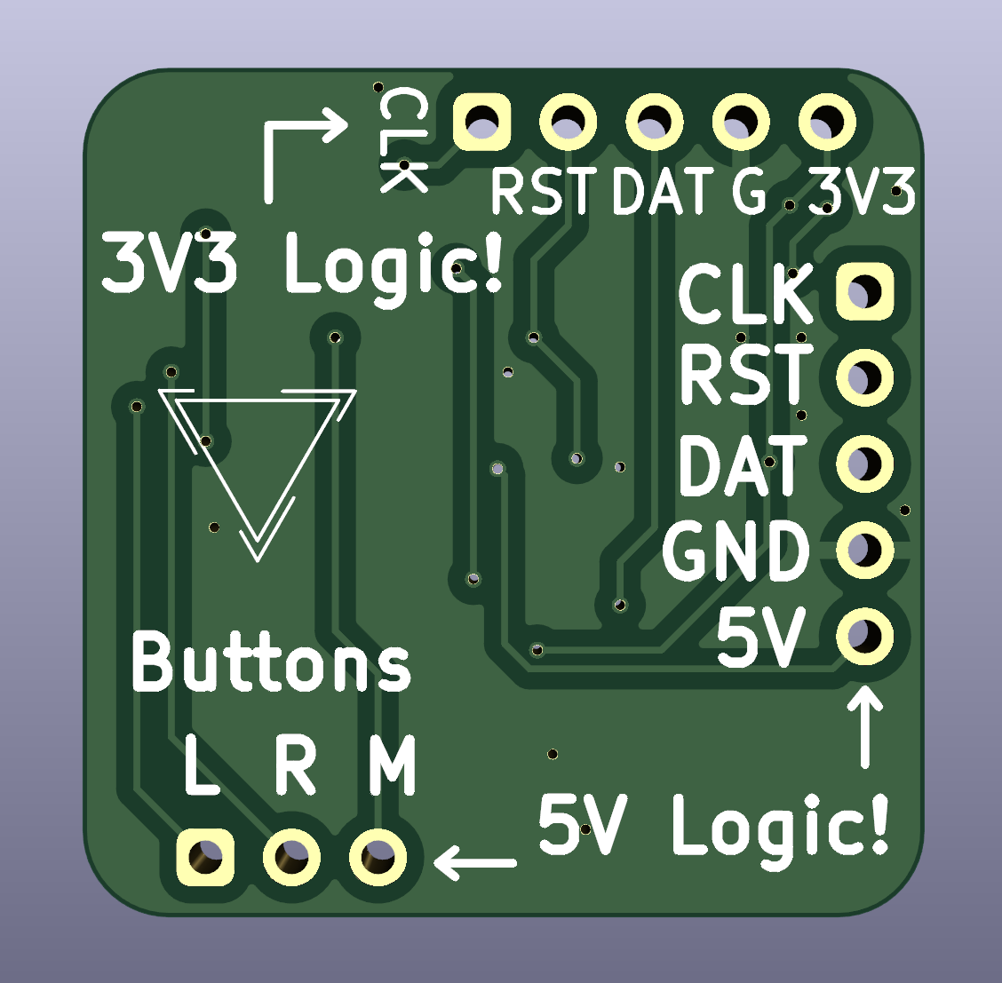
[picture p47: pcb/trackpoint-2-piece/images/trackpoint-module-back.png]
pcb back


## Trackpoint module images

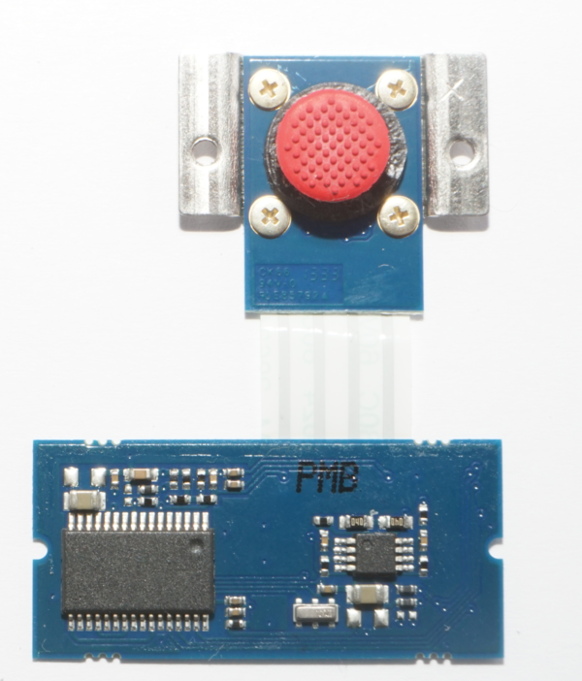
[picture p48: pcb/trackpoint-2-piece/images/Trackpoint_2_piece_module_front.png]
trackpoint module front


trackpoint module pinout

## Credit

Thank you to crehmann for testing this module with their design of the following keyboard, clear instructions and images. This was monumentally helpful in getting this ironed out quickly:  
https://github.com/crehmann/TPS42  

Thanks to quappo for doing the research on existing solutions for trackpoint connectivity  

Thanks to Pete Johanson for adding the logic level conversion circuitry.  

Images: from https://deskauthority.net/wiki/TrackPoint_Hardware

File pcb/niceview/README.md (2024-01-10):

# nice!view

## Overview

This is a VIK module made to add a VIK connector to the [nice!view](https://nicekeyboards.com/nice-view/) display.

## Fabrication and BOM

For PCB fabrication, you can use the files in the production folder.

* gerbers.zip - the file used to fabricate the pcb
* bom.csv - used for PCBA. You can also use the part numbers in this file to look up the exact parts as [lcsc.com](https://lcsc.com)
* positions.csv - used for PCBA

Using the 3 files above, this has been tested at [jlcpcb.com](https://jlcpcb.com)

## VIK module certification

| Category | Classification | Response |
| --- | --- | --- |
| FPC connector | Required | :heavy_check_mark: |
| Breakout pins | Recommended | :x: |
| Uses: SPI | Optional | :heavy_check_mark: |
| SPI used for SPI only | Strongly recommended | :heavy_check_mark: |
| Uses: I2C | Optional | :x: |
| I2C used for I2C only | Strongly Recommended | :x: |
| I2C pull ups | Required | :x: |
| Uses: RGB | Optional | :x: |
| Uses: Extra GPIO 1 | Optional | :x: |
| Uses: Extra GPIO 2 | Optional | :x: |
| Standard PCB Size/Mount | Strongly recommended | :x: |

## PCB images

### horizontal fpc

pcb front

pcb back

### vertical fpc

pcb front

pcb back

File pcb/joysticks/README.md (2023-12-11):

# joysticks vik module

## Overview

This is a vik module to support the following joysticks:  
* [adafruit 2765](https://www.adafruit.com/product/2765)
* [sparkfun 9032](https://www.sparkfun.com/products/9032)
* [nintendo joycon joystick](https://www.amazon.com/Replacement-Joystick-Nintendo-Original-Professional/dp/B08397JQZG/)

Please note that this PCB does **not** support the click on the sparkfun analog joystick, only x and y movements

## Fabrication and BOM

For PCB fabrication, you can use the files in the production folder.

* gerbers.zip - the file used to fabricate the pcb
* bom.csv - used for PCBA. You can also use the part numbers in this file to look up the exact parts as [lcsc.com](https://lcsc.com)
* positions.csv - used for PCBA

Using the 3 files above, this has been tested at [jlcpcb.com](https://jlcpcb.com)

## VIK module certification

| Category | Classification | Response |
| --- | --- | --- |
| FPC connector | Required | :heavy_check_mark: |
| Breakout pins | Recommended | :x: |
| Uses: SPI | Optional | :x: |
| SPI used for SPI only | Strongly recommended | N/A |
| Uses: I2C | Optional | :x: |
| I2C used for I2C only | Strongly Recommended | :x: |
| I2C pull ups | Required | N/A |
| Uses: RGB | Optional | :x: |
| Uses: Extra GPIO 1 | Optional | :heavy_check_mark: |
| Uses: Extra GPIO 2 | Optional | :heavy_check_mark: |
| Standard PCB Size/Mount | Strongly recommended | :x: |

## PCB images

pcb front

pcb back

## joycon joystick wiring

Caution: I have not tested the joycon joystick, but I wired per the image below  

I got this diagram from here:  
https://sudomod.com/forum/viewtopic.php?t=3485

joycon wiring

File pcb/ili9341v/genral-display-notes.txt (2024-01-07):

Pulled from Adafruit's guide, found here:
https://learn.adafruit.com/2-2-tft-display/pinouts

Information below is written to a specific Adafruit display, but generally applicable to most display devices

------------------------------------------------

GND - this is the power and signal ground pin

Vin - this is the power pin, connect to 3-5VDC - it has reverse polarity protection but try to wire it right!

D/C - this is the TFT SPI data or command selector pin. Use 3-5V logic level

RESET - this is the TFT reset pin. Connect to ground to reset the TFT! Its best to have this pin controlled by the library so the display is reset cleanly, but you can also connect it to the Arduino Reset pin, which works for most cases. There is an automatic-reset chip connected so it will reset on power-up. Use 3-5V logic level

SD Card CS / SDCS - this is the SD card chip select, used if you want to read from the SD card. Use 3-5V logic level

LCD_CS - this is the TFT SPI chip select pin. Use 3-5V logic level

MOSI - this is the SPI Microcontroller Out Serial In pin, it is used to send data from the microcontroller to the SD card and/or TFT. Use 3-5V logic level

MISO - this is the SPI Microcontroller In Serial Out pin, its used for the SD card. It isn't used for the TFT display which is write-only. It is 3.3V logic out (but can be read by 5V logic)

CLK - this is the SPI clock input pin. Use 3-5V logic level

Backlite - this is the PWM input for the backlight control. It is by default pulled high (backlight on) you can PWM at any frequency or pull down to turn the backlight off. Use 3-5V logic level

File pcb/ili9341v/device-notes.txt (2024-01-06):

Firmware (not validated):
https://github.com/juj/fbcp-ili9341
https://github.com/dhirajms/mtk-sensors/blob/master/touchpanel/ft6336_pixi4global/ft6336.c

Purchased from:
https://www.aliexpress.us/item/3256805692275620.html
https://www.aliexpress.us/item/3256805720349132.html

Features:
1.3.5-inch color screen, upgraded IPS full view panel, excellent viewing angle
2.320X480 resolution 65K colors, optional capacitive touch function
3.Onboard level conversion chip, compatible with 5V/3.3V microcontroller
4.It can be directly connected to a 5V microcontroller (example for Arduino UNO/Mega2560)
5.Adopting a 4W-SPI serial bus, it only requires a few IOs to light up the display
6.Equipped with Micro TF card slot for easy storage expansion

Parameter:
LCD screen parameters:
Screen size: 3.5 inches
Screen type: IPS
Resolution: 320xRGBx480 (pixels)
Effective display area: 48.96 (W) x 73.44 (H) (mm)
Drive IC: ST7796U
Display interface: 4-Line SPI
Pixel size: 0.153 (H) x 0.153 (V) (mm)
Visual angle: ALL 0 'CLOCK
Backlight brightness: (typical value) 300 (cd/m2)
Backlight type: White LED * 6
Working temperature: -10~50 (℃)
Storage temperature: -20~60 (℃)
Touch screen parameters:
Effective area size: 3.5 inches
Touch screen type: capacitive touch screen
Touch screen resolution: 320x480 (pixels)
Drive IC: FT6336U
Visual window size: 49.56 (w) x 74.04 (H) (mm)
Communication interface: IIC
Structural material: G+F
Working temperature: -20~70 (℃)
Storage temperature: -30~80 (℃)
Electrical parameters
Working voltage: 5.0 V
Backlight current: 95 mA
Power consumption: 0.5 W
External interface: 14P 2.54mm pin and 0.5mm FPC

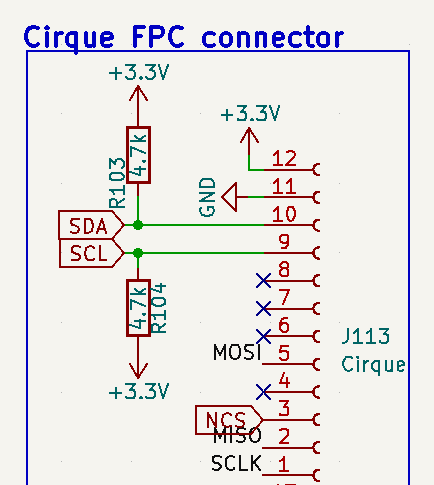
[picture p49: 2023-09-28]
images/cirque-to-vik-schematic-before.png

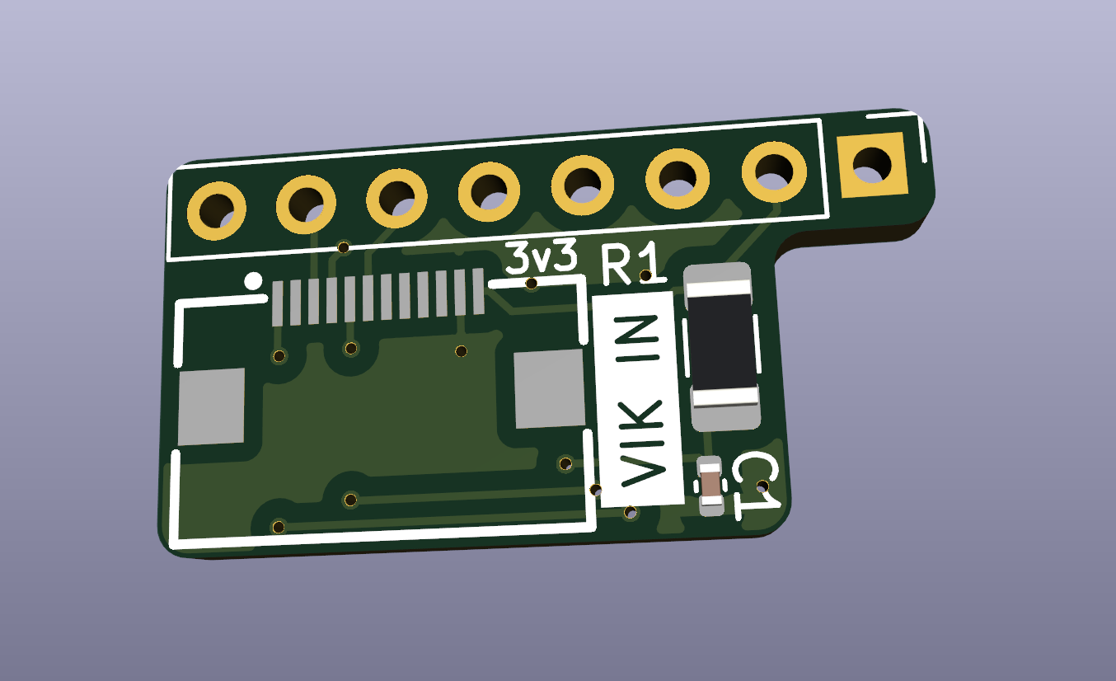
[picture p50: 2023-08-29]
pcb/weact-st7735/images/weact-st7735-module-back.png

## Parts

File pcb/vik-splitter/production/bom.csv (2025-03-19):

Designator | Footprint | Quantity | Value | LCSC Part #
J1001, J1004 | vik-keyboard-connector-horizontal | 2 | ~ | C2919557
J1002 | vik-module-throughole | 1 | ~ | C2919557
J1003 | vik-module-connector-horizontal | 1 | ~ | C2919557

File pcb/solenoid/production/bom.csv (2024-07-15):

Designator | Footprint | Quantity | Value | LCSC Part #
D1001 | D_DO-41_SOD81_P7.62mm_Horizontal | 1 | 1N4001
J1001 | PinHeader_1x02_P2.54mm_Vertical | 1 | Conn_01x02_Female
J1002 | PinHeader_1x06_P2.54mm_Vertical | 1 | Conn_01x06_Female
J1003 | vik-module-connector-horizontal | 1 | ~ | C479750
Q1001 | TO-220-3_Vertical | 1 | TIP120
R1001 | R_Axial_DIN0204_L3.6mm_D1.6mm_P7.62mm_Horizontal | 1 | R2.2

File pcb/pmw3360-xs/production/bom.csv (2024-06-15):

Designator | Footprint | Quantity | Value | LCSC Part #
_2, |  | 2
C1001 | 0603 | 1 | 4.7uF | C19666
C1002, C1005 | 0603 | 2 | 1uF | C15849
IC1001 | SOT-23-5_HandSoldering | 1 | AP7335-WG-7 | C460382
J1001, J1002, J1004, J1005, J1006, J1007, J1008 | SolderWire-0.5sqmm_1x01_D0.9mm_OD2.3mm | 7 | Conn_01x01_Socket
J1003 | vik-module-connector-horizontal | 1 | ~ | C2919557
R1001, R1004 | 0603 | 2 | 10k | C25804
R1002 | 0603 | 1 | 39 | C23154
R1003 | 0603 | 1 | 15k | C22809
U1001 | DIP-16_W10.16mm | 1 | PMW3360DM-T2QU

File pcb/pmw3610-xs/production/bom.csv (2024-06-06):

Designator | Footprint | Quantity | Value | LCSC Part #
C1, C2, C3, C6, C7, C8, C9 | 0603 | 7 | 4.7uF | C19666
C4 | 0603 | 1 | 0.1u | C14663
C5 | 0603 | 1 | 1u | C15849
J1, J2, J3, J5, J6, J7, J8 | PinHeader_1x01_P1.00mm_NoSilk | 7 | Conn_01x01_Socket
J4 | vik-module-connector-horizontal | 1 | ~ | C479750
JP1 | SolderJumper-3_P1.3mm_Open_RoundedPad1.0x1.5mm_NumberLabels | 1 | SolderJumper_3_Open
R1 | 0603 | 1 | 2M | C465466
U1 | SOT-23-5 | 1 | TCR2EF19 | C146366
U2 | PMW3610 | 1 | PMW3610

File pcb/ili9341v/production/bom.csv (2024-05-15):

Designator | Footprint | Quantity | Value | LCSC Part #
C1, C2 | 1206 | 2 | 1u | C90539
J1 | vik-module-connector-horizontal | 1 | ~ | C479750
J2 | PinHeader_1x14_P2.54mm_Vertical | 1 | Conn_01x14_Socket
JP1 | SolderJumper-3_P1.3mm_Bridged12_RoundedPad1.0x1.5mm_NumberLabels | 1 | SolderJumper_3_Bridged12
R1, R2 | 1206 | 2 | 100k | C17900

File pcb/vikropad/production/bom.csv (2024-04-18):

Designator | Footprint | Quantity | Value | LCSC Part #
D1, D10, D11, D12, D13, D14, D15, D16, D17, D18, D2, D3, D4, D5, D6, D7, D8, D9 | D_SOD-123 | 18 | 1N4148W | C909967
D21, D22, D23, D24, D25, D26, D27, D28, D29, D30 | D_SOD-123 | 10 | 1N4148 | C8598
HAT1, HAT2 | 5Way-Tactile_K1-1506DN-01 | 2 | 5Way-Tactile_K1-1506DN-01
J1 | vik-module-connector-horizontal | 1 | ~ | C479750
J2 | PinHeader_1x01_P2.54mm_Vertical | 1 | Conn_01x01_Socket
J3, J4, J5 | PinHeader_1x02_P2.54mm_Vertical | 3 | Conn_01x02_Socket
R8, R9 | 0805 | 2 | 4.7kΩ | C17673
SW1, SW10, SW11, SW12, SW13, SW14, SW15, SW16, SW17, SW18, SW2, SW3, SW4, SW5, SW6, SW7, SW8, SW9 | gateron-ks27-choc-v1-mx-soldered-and-hotswap | 18 | SW_Push
U1, U2 | SOIC-16_3.9x9.9mm_P1.27mm | 2 | SN74HC595 | C5947
U3, U4 | DIP-16_W7.62mm | 2 | SN74HC595

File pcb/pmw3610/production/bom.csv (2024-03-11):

Designator | Footprint | Quantity | Value | LCSC Part #
C1, C2, C3, C6, C7, C8, C9 | 0603 | 7 | 4.7uF | C19666
C4 | 0603 | 1 | 0.1u | C14663
C5 | 0603 | 1 | 1u | C15849
J2, J3 | PinHeader_1x06_P2.54mm_Vertical | 2 | Conn_01x06_Female
J4 | vik-module-connector-horizontal | 1 | ~ | C479750
JP1 | SolderJumper-3_P1.3mm_Open_RoundedPad1.0x1.5mm_NumberLabels | 1 | SolderJumper_3_Open
R1 | 0603 | 1 | 2M | C465466
R2, R3 | D3_TH_SMD | 2 | 4.7k
U1 | SOT-23-5 | 1 | TCR2EF19 | C146366
U2 | PMW3610 | 1 | PMW3610

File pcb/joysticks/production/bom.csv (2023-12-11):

Designator | Footprint | Quantity | Value | LCSC Part #
_2, |  | 2
J1001, J1007 | SolderWire-0.5sqmm_1x01_D0.9mm_OD2.3mm | 2 | Conn_01x01_Socket
J1002 | TE_0-1734839-5_1x05-1MP_P0.5mm_Horizontal | 1 | Conn_01x05_Socket | C3041165
J1003 | vik-module-connector-horizontal | 1 | ~ | C2919557
JOY1001 | joystick_analog_xy | 1 | JOYSTICK_ANALOG_XY
S1001 | sparkfun_9032_joystick_thumb | 1 | JOYSTICK_THUMB

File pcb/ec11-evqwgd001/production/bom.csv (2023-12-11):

Designator | Footprint | Quantity | Value | LCSC Part #
_2, |  | 2
D1001, D1002, D1003, D1004 | SK6812MINI-E-no-switch-outline | 4 | SK6812MINI-E
J1001, J1007, J1013 | SolderWire-0.5sqmm_1x01_D0.9mm_OD2.3mm | 3 | Conn_01x01_Socket
J1003 | vik-module-connector-horizontal | 1 | ~ | C2919557
SW1001 | EVQWGD001 | 1 | EVQWGD001
SW1002 | RotaryEncoder_EC11-no-legs | 1 | RotaryEncoder

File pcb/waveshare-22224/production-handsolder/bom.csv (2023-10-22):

Designator | Footprint | Quantity | Value | LCSC Part #
C1 | 0805 | 1 | 1u
J1 | vik-module-connector-horizontal | 1 | ~ | C479750
J2 | JST_PH_S8B-PH-SM4-TB_1x08-1MP_P2.00mm_Horizontal-Bridge | 1 | Conn_01x08_Socket
R1 | 0805 | 1 | 100k

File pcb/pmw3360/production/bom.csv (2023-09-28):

Designator | Footprint | Quantity | Value | LCSC Part #
_2, |  | 2
C1001 | 0603 | 1 | 4.7uF | C19666
C1002, C1005 | 0603 | 2 | 1uF | C15849
IC1001 | SOT-23-5_HandSoldering | 1 | AP7335-WG-7 | C460382
J1001, J1002 | PinHeader_1x06_P2.54mm_Vertical | 2 | Conn_01x06_Female
J1003 | vik-module-connector-horizontal | 1 | ~ | C479750
R1001, R1004 | 0603 | 2 | 10k | C25804
R1002 | 0603 | 1 | 39 | C23154
R1003 | 0603 | 1 | 15k | C22809
R1005, R1006 | D3_TH_SMD | 2 | 4.7k
U1001 | DIP-16_W10.16mm | 1 | PMW3360DM-T2QU

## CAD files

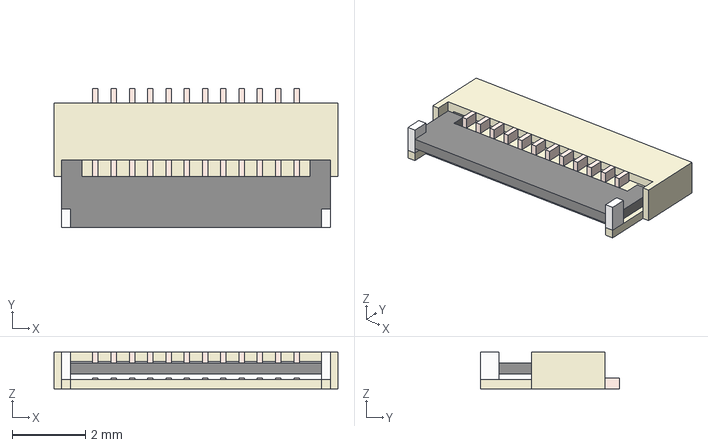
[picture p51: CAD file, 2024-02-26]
kicad/3dmodels/vik-connector-horizontal-mini.step
7.77 x 3.80 x 1.00 mm

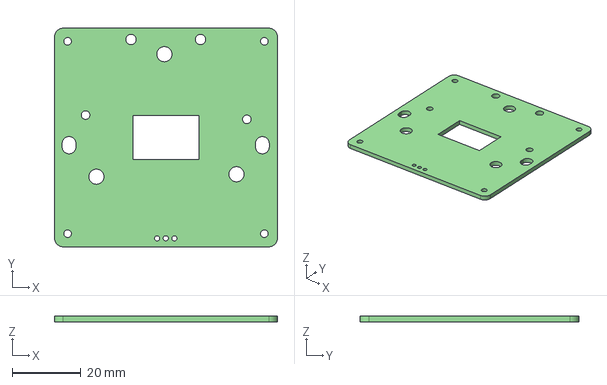
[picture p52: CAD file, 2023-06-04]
pcb/per56-cirque-leds/pers60-cirque-leds-pcb.step
64.8 x 63.5 x 1.60 mm

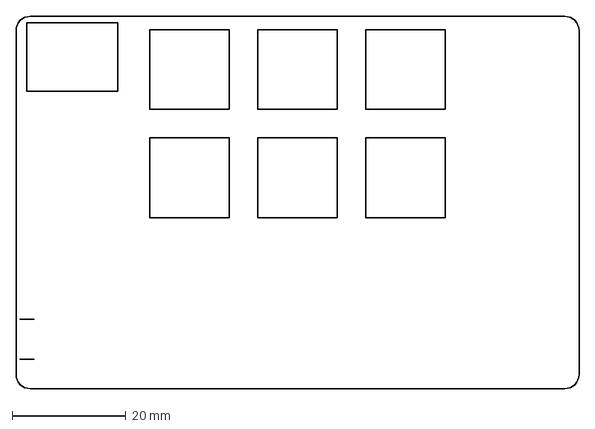
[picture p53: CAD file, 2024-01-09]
pcb/vik-playground/vik-playground-brd.dxf
99.0 x 65.5 mm

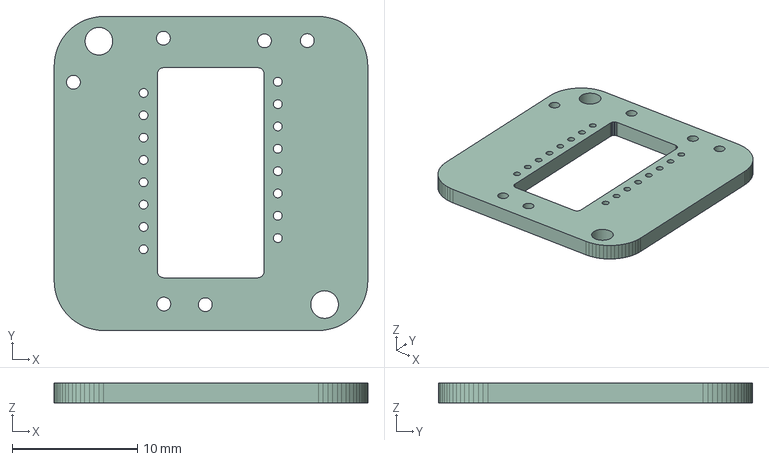
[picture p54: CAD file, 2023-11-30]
pcb/vik-splitter/vik-pmw3360-xs.step
25.0 x 25.0 x 1.58 mm

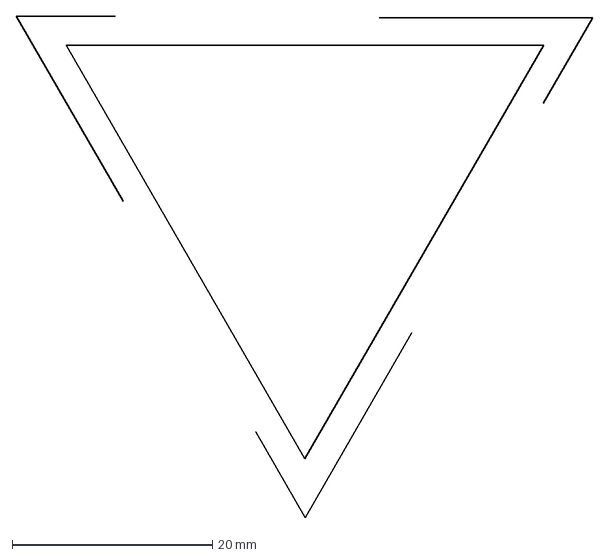
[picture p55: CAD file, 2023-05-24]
vik-logo.dxf
57.5 x 50.0 mm

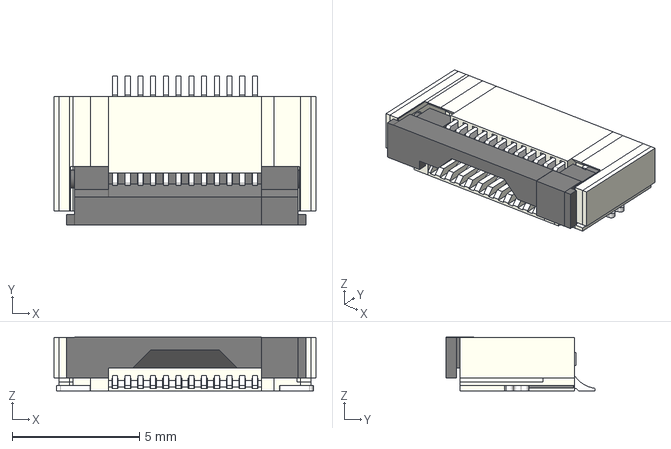
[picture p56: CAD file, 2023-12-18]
kicad/3dmodels/vik-connector-horizontal.stp
10.3 x 5.85 x 2.11 mm

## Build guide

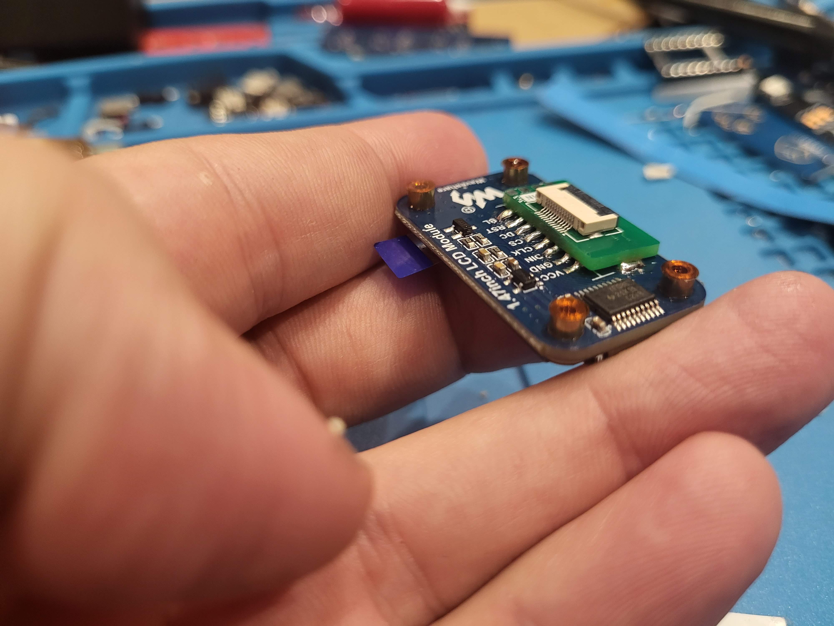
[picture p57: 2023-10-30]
pcb/waveshare-22224/images/waveshare-22224-soldering-02.jpg

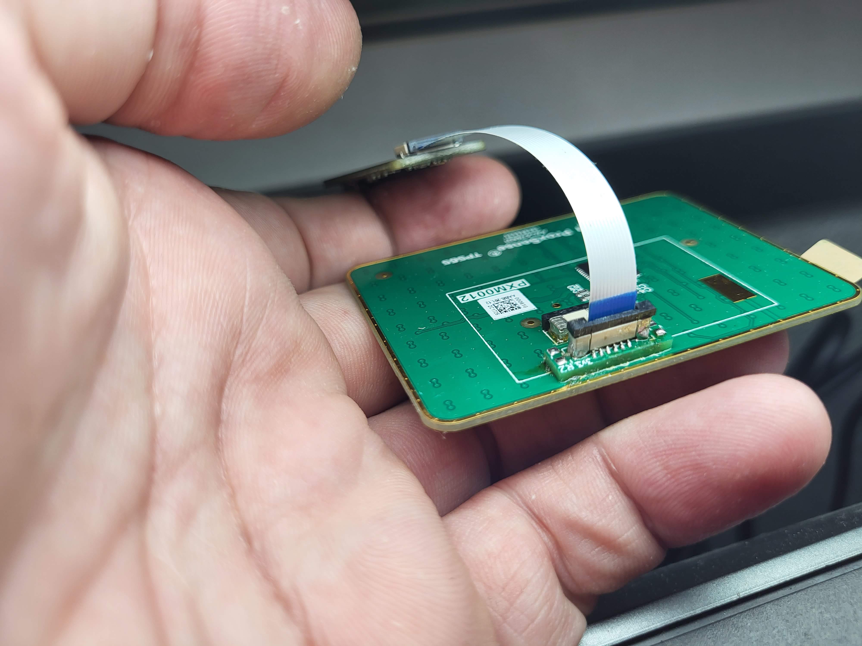
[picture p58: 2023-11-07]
pcb/azoteq-tps/vertical-fpc/images/assembled-vertical-2.jpg

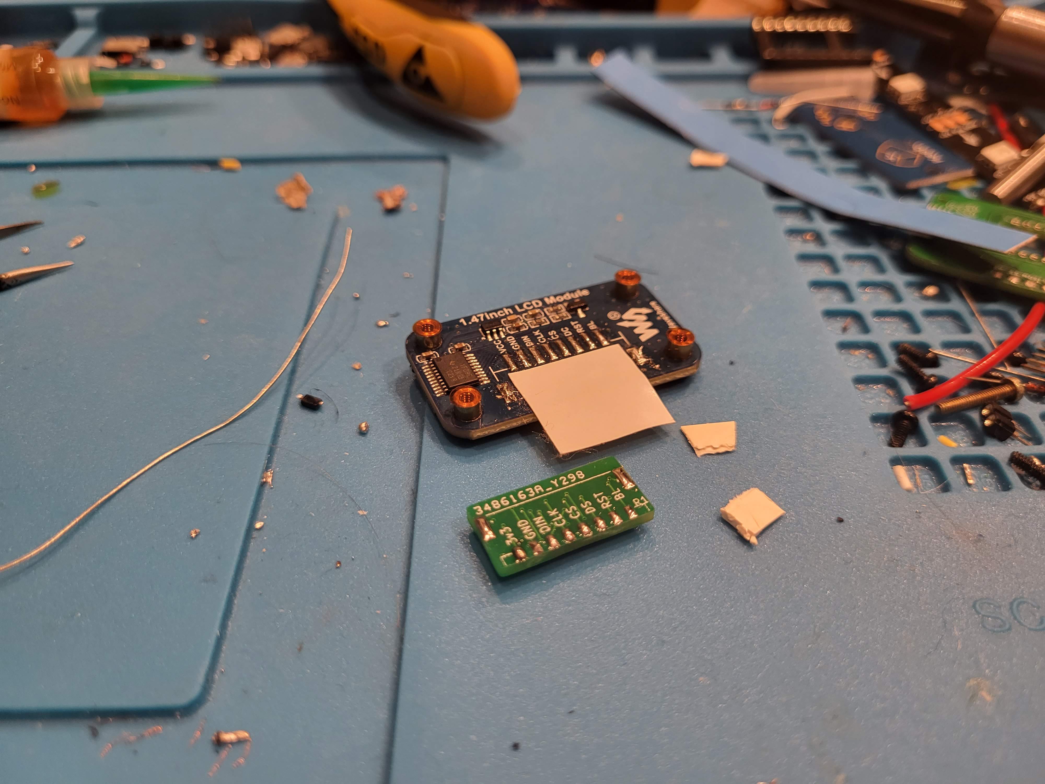
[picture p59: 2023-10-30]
pcb/waveshare-22224/images/waveshare-22224-soldering-01.jpg

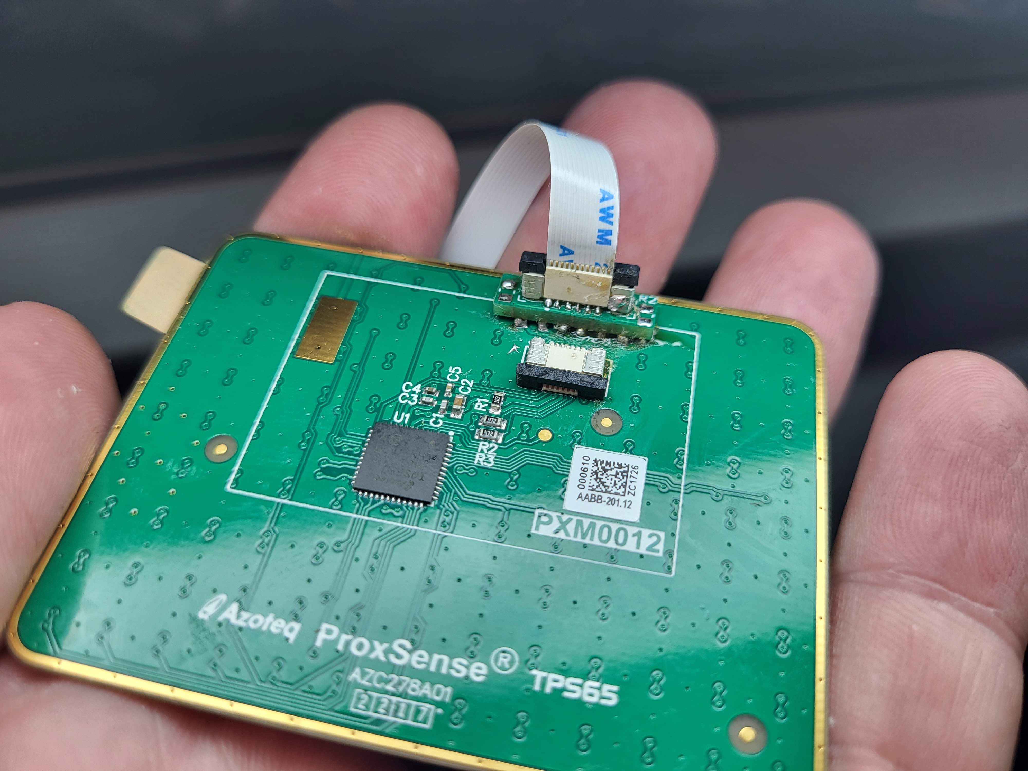
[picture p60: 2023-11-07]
pcb/azoteq-tps/vertical-fpc/images/assembled-vertical-1.jpg

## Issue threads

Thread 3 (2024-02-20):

Magnetic connector alternative

TildeWill, 2024-02-20:
In my keyboard, I want to swap modules while working, without opening up my keyboard to change a cable. Would VIK consider supporting a second, hot-swappable type of connector and magnets or some other system for securing the module in place? Inspiration from the Naya Create keyboard (https://naya.tech/)

sadekbaroudi, 2024-04-24:
Hi @TildeWill - I hadn't noticed this issue until now. Sorry for the delayed response.

I have definitely considered exactly this! One thing I've considered is creating a standard PCB that connects to the VIK connector via FPC, and houses a magnetic connector. This would allow backwards compatibility with existing PCBs, and would address exactly what you're looking for!

For an example of something similar to this, see the https://github.com/zzeneg/duet by @zzeneg

I just mentioned in issue #2 that I'm keeping a list of potential items for a future VIK 2.0. I will keep this issue open as well, as I really like the idea. I think a magnetic connector would be outstanding.

TildeWill, 2024-05-07:
I like the backwards compatibility idea!
I've looked at the duet and even ordered the same connectors - they're strong but not strong enough to hold a pointing device in place on an intense gaming session. I thought about using the Nintendo Switch Joy Con rail connectors because they're cheap and address my hot-swap needs, but those only have 10 pins. Feels like there must be something out there...

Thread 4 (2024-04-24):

Flexibility for keyboard to decide on Type A, Type B, or both, for fpc cable support

sadekbaroudi, 2024-04-24:
I'm have considered this in the past, and I'm considering it again...

Currently, VIK specifies that you must use a Type A fpc cable. The reality is, it doesn't have to... If I were to offer the option to wire the keyboard the way it is today, or inverted to match the module vik connector, then the keyboard designer could decide whether they wanted to use Type A or Type B. This would not break module compatibility, as the modules would always be wired the same...

So, currently there are the following symbols for the schematic:
vik-keyboard-connector
vik-module-connector

Instead, I'd include:
vik-keyboard-connector-type-a
vik-keyboard-connector-type-b
vik-module-connector

The requirement would be that the VIK keyboard certification card would have to include which type it uses. The keyboard distributor/designer/open source repo would have to make sure it clearly specifies this (by means of the VIK certification or otherwise).

Pro: more flexibility for keyboard designs to route the cable much more cleanly if needed
Con: people would need to be aware and carry both types of cables if they planned on using multiple boards with VIK connectors on the keyboard side

thomasbaart, 2025-02-17:
This issue was just mentioned on the splitkb.com Discord server. Our modules have the VIK pinout reversed, and our VIK port on the keyboard is mounted on the bottom side. As such, our documentation currently (sparsely) mentions:

> Our keyboards are compatible with any other non halcyon VIK module using a standard type A cable (Same side contacts).

and:

> Our modules are compatible with any other VIK keyboard using a type D cable (Opposite side contacts).

It'd probably be useful to have some kind of distinction, like putting some symbol next to both the module and the keyboard port. If both of them match, you use a same-side cable, otherwise you use a different-side cable.

sadekbaroudi, 2025-02-17:
@thomasbaart - sounds good. I just needed a nudge to implement this one. I can take care of this soon. I'll update the footprints as described in my first comment in this issue, and then update the VIK specs themselves with images to highlight the distinction. I know you implemented it on your board(s). Did you put any markings or anything that you'd like me to repurpose? Otherwise, I'll just make up my own.

thomasbaart, 2025-02-18:
TLDR: The _only_ reason why you would need to invert the pin sequence is to be able to _neatly tuck away the cable_. Doing so _requires_ the use of a different cable type.

Let's determine what makes a set of a keyboard, module and cable compatible with one another.

# Flat cable types

Flat connector cables can be grouped by three classes:

1. Cables with the pins on the _same_ side, where one side of the pins is shielded by insulation and/or is supported by stiff material.
    - Flat cables types that conform to this description are "Type A", "Type C" and "Type F".
2. Cables with the pins on _opposing_ sides, where one side of the pins is shielded by insulation and/or is supported by stiff material.
    - Flat cables types that conform to this description are "Type B" and "Type D".
3. Cables with one or both sets of pins exposed on _both sides_, without any shielding on one or both connectors.
    - Flat cables types that conform to this description are "Type E", "Type G", "Type H" and "Type I".

The cable type _only_ matters for making a connection with the connector. The connectors I've seen can only connect with the cable on the PCB side, so the side of the cable facing the PCB would need to be exposed. A cable in the third "class", with both sides exposed, could always be connected, though it'd be more fragile. The reason why you want your cable to be shielded on one side is to _prevent_ mixing up the sequence of pins (thus potentially shorting various pins on your controller), as you'll see below.

# Relative orientation of connectors

The readme states the following:

> ... the cable will automatically invert the order when connected.

This is _technically_ not true. It's not the cable doing the inverting, but rather the orientation of the connectors relative to one another:

- The same connector is used on both the keyboard and the module.
- One of the connectors needs to be rotated by 180º to match the other end of the cable.
- The cable is just a flexible piece of material with traces running along it, so if pin 1 is connected on the left side, it will remain on the left. With a rotated connector, that left pin will become pin 12 on the other side.

This distinction matters because the cable in of itself _does not_ invert the sequence of pins. The cable _can invert_ the sequence only if the cable itself is _rotated along its axis_. This can be done by bending it over itself an _uneven_ number of times, such as with a single 45º bend, or a half-turn corkscrew bend.

If the cable is bent perpendicular to itself (folded in half), the pin that's on the "left side" of the cable will still remain on the left side. It does not, in of itself, require the pin assignment to be inverted.

In short, if the orientation of the connectors is the same (both facing the same cardinal direction, and both mounted on the same side of the PCB), then a pin sequence inversion is not needed.

# Compatibility

What determines whether a keyboard is compatible with a module, then, is defined by the relative orientation of its connectors and whether the orientation of the cable is flipped along the way.

Let's go through the same example for the Vulpes Minora, which was supplied as the first example keyboard in the VIK specification:

- The connector is placed on the _top_ of the right side of the keyboard and faces _west_. I assume this uses the pin sequence outlined in the README, so pin 1 is `3.3V`, and pin 12 is `SCLK`.
- We're looking at the keyboard from the top, so in our perspective, pin 1 is on the _north_ side.
- Let's plug in the cable. It's a type A cable, as per the documentation, and as it simply connects to the connector, its north side will be connected to pin 1, same as the keyboard's connector.
- If we then connect a module with its connector being on the _top_ side, that connector would face _east_, and its pin 1 would face _south_: the opposite of what our cable has. It follows that we have to _invert_ the pin sequence.

Easy enough! We made sure both connectors are facing the same side of their respective PCBs, we kept their orientation the same during their installation as well as during the design phase, and so we're able to use a type A cable with the contacts on the same side, just as the specifications intended.

What if we want to make a module that has its connector on its bottom side?

- We're starting out with the same right side of a Vulpes Minora, so the connector is still placed on the _top_ side of the keyboard facing _west_, with pin 1 facing _north_.
- With a type A cable as specified by the documentation, the other end of the cable is still exposed on the bottom side. If we want to connect it to our module's bottom side, we need to _twist the cable along its axis_, thus inverting the direction in which pin 1 faces: pin 1 is now connected to the cable's _south_ side.
- With the module's connector on the _bottom_ side, it still faces _east_. Its pin 1 would face _north_, and we would still have to _invert_ the module's pin mapping.

Twisting the cable along its axis might be a bit of a snag, but not too difficult - we probably want to fold the cable by roughly 45º anyway as the module would be mounted in a 3D printed case in the middle. Nice!

Let's now take a look at an example that I'm familiar with: a Halcyon series keyboard, along with a Halcyon series module:

- The connector is placed on the _bottom_ of the keyboard and faces _south_. It uses the pin sequence as outlined in the README: pin 1 is `3.3V`, and pin 12 is `SCLK`.
- We're looking at our keyboard from the top, so in our perspective, pin 1 is on the _east_ side.
- Let's plug in the flat cable. It's threaded through a slot in the PCB toward the top, where a module is to be installed. Folding the cable over itself does not invert the pin sequence, so pin 1 still faces _east_.
- The module's connector is placed on the _bottom_ of its PCB, and it too faces _south_, because that's where the cable will be coming from. This orientation means that the connector's pin 1 also faces _east_.
- With both pin 1 on the cable as well as pin 1 on the connector both facing _east_, and with our cable _not being twisted_, we are _not inverting_ the sequence of pins on our module.
- If we would use a type A cable per the specifications, then we'd run into an issue now: the cable would need to be inverted in order for the exposed contacts to connect with the connector! If we'd twist the cable, we'd also need to invert the pin sequence. We're now faced with a choice: do we go for a tidy cable and use one with  _contacts on opposing sides_ without inverting the pin order, or do we properly adhere to specifications, use a type A cable, twist it and invert the pin order?

We went with the nice and tidy solution, making for a less awkward install and tidier cable, at the cost of _breaking compatibility with the VIK specifications_.

# Conclusion

From all this, we can conclude the following:

- Twisting the cable along its axis an uneven number of times will invert the pin order.
- Placing the connector on an _opposite side_ will also invert the pin order. Given the same cable as before, it requires you to twist the cable along its axis an uneven number of times.

With that in mind, it can be stated that:

- Given that the pinout on the keyboard is always the same and given that a _type A_ cable with contacts on the same sides is used, you _will invert_ the pin mapping on a module.
- Given that the pinout on the keyboard is always the same and given that a _type B_ cable with contacts on opposing sides is used, you _will not invert_ the pin mapping on a module.

And so:

- Given that the pinout on the keyboard is _always the same_, _the module can decide_ which type of cable the user should use: either _type A_ with contacts on the same sides, or _type B_ with contacts on opposing sides.

I think the most simple solution is to require modules to indicate whether they want a type A or type B cable, where type A would be the current default, and type B would be for modules that wish to not invert the pin mapping.

It could be as simple as appending a character to the text already present next to the connector, such as "3v3 A" and "3v3 B", or "VIK IN A" and "VIK IN B".

thomasbaart, 2025-02-18:
Or as Harvey eloquently put it, putting my entire essay to shame:

> The insulation on one side of the cable forces its orientation relative to the connector, so it doesn’t matter how many twists or folds you make. Type A will always require an inversion, while type B will always require the sequence to remain the same. The only requirement is that the keyboard will always retain the same sequence, if you start to mess with that too, then it starts to get really complicated.

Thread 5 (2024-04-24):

Formally grant SPI CS pin for any purpose if not used for SPI

sadekbaroudi, 2024-04-24:
Credit to @george-norton for the idea

The SPI CS in the VIK connector is intended for that purpose. However, if it's not used in the module, is there really any reason to not grant permission for the module to use as a general digital IO pin?

In every other case, this doesn't make sense, except for SPI CS

For I2C, you would disrupt the bus by using for any other purpose
For the other 3 SPI pins (MISO, MOSI, SCLK), you would also disrupt the bus by using for any other purpose
For RGB, you can't be sure that the main pcb isn't using it for RGB already, rendering it useless for any other purpose
For the other two general analog/digital GPIO, they're already free to use.

There really aren't any clear downsides to officially granting access to the module to SPI CS as a 3rd digital GPIO.

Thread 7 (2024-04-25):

vik module for haptic feedback: DRV2605L

sadekbaroudi, 2024-04-25:
The PCB should also contain a mechanism to mount a casing for the motor.

Something like this:
https://www.smart-prototyping.com/DRV2605L-Haptic-motor-Driver

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

Then you can connect in a vibration motor, like this:
https://www.digikey.com/en/products/detail/seeed-technology-co.,-ltd/316040001/5487672

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

sadekbaroudi, 2024-05-09:
@zzeneg made this!
https://github.com/sadekbaroudi/vik/pull/8

Closed 2024-05-09.

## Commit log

2023-05-23 first couple of modules for voltron interface for keyboards
    [bom.csv, designators.csv, haptic.kicad_pcb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]
2023-05-24 added pmw3360 module, vik logo footprints, and added vik logo to existing pcbs
    [bom.csv, designators.csv, haptic.kicad_pcb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]
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2023-05-25 new vik module, scroll ring with trackball and leds
    [bom.csv, designators.csv, positions.csv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]
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2023-06-02 fixed the comment about the fpc signal and pin ordering
2023-06-02 no longer voltron, trademark, yadda yadda
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2023-06-04 added step file for pers cirque leds module
    [pers60-cirque-leds-pcb.step]
2023-06-05 removed extra footprints and symbols, added kicad footprints, and instructions on how to use them
    [bom.csv, haptic.kicad_pcb, haptic.kicad_sch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]
2023-06-05 fixed label orientation on through hole footprint
2023-06-05 fixed missing content, and added links and references for connectors in the descriptions for the certification
2023-06-06 added in and out labels to connector footprint, and updated instructions in readme accordingly
    [bom.csv, haptic.kicad_pcb, haptic.kicad_sch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]
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2023-06-12 updated all footprints to include the 3v3 label so it's easier to verify correct cable insertion when using the pcbs
    [haptic.kicad_pcb, pmw3360.kicad_pcb, scroll-wheel-trackball.kicad_pcb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]
2023-06-26 updated vik to have 2 GPIO instead of two GND, along with all the modules
    [haptic.kicad_pcb, haptic.kicad_sch, pmw3360.kicad_pcb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]
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2023-07-27 renamed the pers60 to per56, as that's the correct part name
    [bom.csv, designators.csv, pers60-cirque-leds-pcb.step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]
2023-07-28 updated a few things, including standard pcb sizes and mounting, 3v3 logic level specification
    [scroll-wheel-trackball.kicad_pcb, scroll-wheel-trackpad.kicad_pcb]
2023-07-30 added feature list, and audio buzzer to bom
2023-07-30 added module mounting footprints to make designing both the module pcbs and the keyboard pcbs mounting for modules easier
    [bom.csv, designators.csv, pmw3360.kicad_pcb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]
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2023-09-27 moved the pmw3360 vik modules to deprecated, creating new ones
    [bom.csv, designators.csv, pmw3360.kicad_pcb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]
2023-09-28 updated both pmw3360 modules to have cheaper fabrication and more exposed VIK signals, and updated haptic to include better footprints for I2C pull ups
    [bom.csv, designators.csv, haptic.kicad_pcb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]
2023-09-29 gc9a01 round display 240 x 240 vik breakout adapter
    [bom.csv, designators.csv, gc9a01.kicad_pcb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]
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2023-10-22 made waveshare 22224 pcb large enough for jlcpcb PCBA
    [positions.csv, waveshare-22224.kicad_pcb, waveshare-22224.kicad_sch]
2023-10-22 added 0805 hand solderable pcb for waveshare 22224
    [bom.csv, designators.csv, positions.csv]
2023-10-23 added pmw3360 extra small pcb, 25mm by 25mm
    [bom.csv, designators.csv, pmw3360.kicad_pcb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]
2023-10-23 moved mounting holes a bit so they don't interfere with the pmw3360 lens
    [bom.csv, designators.csv, pmw3360.kicad_pcb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]
2023-10-25 added azoteq proxsense modules and new vik horizontal mini connector for jlcpcb C2919479
    [azoteq-tps.kicad_pcb, azoteq-tps.kicad_sch, bom.csv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]
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2023-11-22 added readmes for pmw3360 modules, and added silks for breakout for pmw3360-xs
    [pmw3360.kicad_pcb]
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2023-11-30 added missing mapping from 1mm fpc connector for RESET signal, and added trackpoint button through holes
    [bom.csv, designators.csv, positions.csv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]
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2023-12-18 VIK playground module, thanks to georgeN for the suggestion
    [bom.csv, designators.csv, positions.csv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]
2023-12-18 updated version of vik playground with more features, including TS3A27518EPWR switching multiplexer and demultiplexer for easy switching between direct pin and row col matrix switches
    [bom.csv, designators.csv, positions.csv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]
2023-12-18 fixed one component that had 0805 footprint, but using 0603 component, switched to the 0805 capacitor instead
    [bom.csv, vik-playground.kicad_pcb, vik-playground.kicad_sch]
2023-12-19 converted switch matrix col jumpers from solderable jumpers to pin header jumpers
    [bom.csv, positions.csv, vik-playground.kicad_pcb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]
2023-12-20 shift register was connected to 5v with 3.3v logic levels, fixed by switching to 3.3v vcc
    [vik-playground.kicad_pcb, vik-playground.kicad_sch]
2023-12-22 Logic level tweaks to trackpoint_2_piece adapter.
    * Use BSS138 for level shifting clock and data lines between 3.3v
    VIK I/O and 5v PS/2 I/O.
    * Tweaked silk to show clearly that through hole headers are 5v
    logic level.
    [trackpoint_2_piece.kicad_pcb, trackpoint_2_piece.kicad_sch]
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2023-12-29 added breadboard version of vik universal, hazel's idea
    [bom.csv, designators.csv, positions.csv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]
2023-12-29 added handwired version of vik universal, which is much smaller than the others
    [bom.csv, designators.csv, positions.csv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]
2023-12-29 fixed readmes for the vik universal boards
2023-12-29 Updated VIK breadboard to be 2.54mm horizontal spacing, along with a second set of numbered through holes to allow you to more easily wire up from the numbered columns to the VIK columns
    [bom.csv, designators.csv, positions.csv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]
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2024-01-01 fixed silks, added rgb interception headers and more power connectors
    [bom.csv, designators.csv, positions.csv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]
2024-01-01 realized that the vik universal breadboard wasn't actually a breadboard at all, so I redid it to be so
    [bom.csv, designators.csv, positions.csv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]
2024-01-01 added support for 3v3 through holes as well as the 5v, reversed the pinout for the trackpoint connector to match cable from trackpoint itself
    [bom.csv, designators.csv, positions.csv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]
2024-01-02 vik universal handwire - added jumpers to enable or disable I2C pull up resistors
    [bom.csv, designators.csv, vik-universal.kicad_pcb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]
2024-01-02 vik universal jumper input output matrix - added I2C pull ups, jumpers to enable or disable I2C pull up resistors
    [bom.csv, designators.csv, positions.csv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]
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2024-01-08 updated vikm connector symbols, per some recommendations from sigprof in fingerpunch discord
    [azoteq-tps.kicad_sch, ec11-evqwgd001.kicad_sch, gc9a01.kicad_sch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]
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2024-01-09 added MISO for SD card support, added jumper to select between backlight and sd card, defaults to backlight
    [bom.csv, designators.csv, ili9341v.kicad_pcb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]
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2024-05-15 ili9341v display module - updated to use hand solderable capacitors, 1206 instead of 0402
    [bom.csv, ili9341v.kicad_pcb, ili9341v.kicad_sch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]
2024-05-23 updated to add alternate parts for the LDO for the vik pmw3610 module
    [pmw3610.kicad_sch]
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2024-10-28 Fix vik-keyboard-connector-horizontal-mini footprint label
2025-03-19 vik splitter module for splitting one VIK IN to two VIK OUT connections
    [bom.csv, designators.csv, positions.csv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]
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
